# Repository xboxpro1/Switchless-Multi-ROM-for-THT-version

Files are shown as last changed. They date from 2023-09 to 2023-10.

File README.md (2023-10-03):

# CBM Switchless Multi-ROM for 2364 & 27128 & 27256 ROMs

This is a fork, rework and combination of two repositories from RetroNynjah.

<https://github.com/RetroNynjah/Switchless-Multi-ROM-for-2364>

<https://github.com/RetroNynjah/Switchless-Multi-ROM-for-27128-27256>

I would like to thank RetroNynjah for the brilliant idea and excellent work.<br/>
After a long search on the internet, there is finally the perfect ROM switcher.

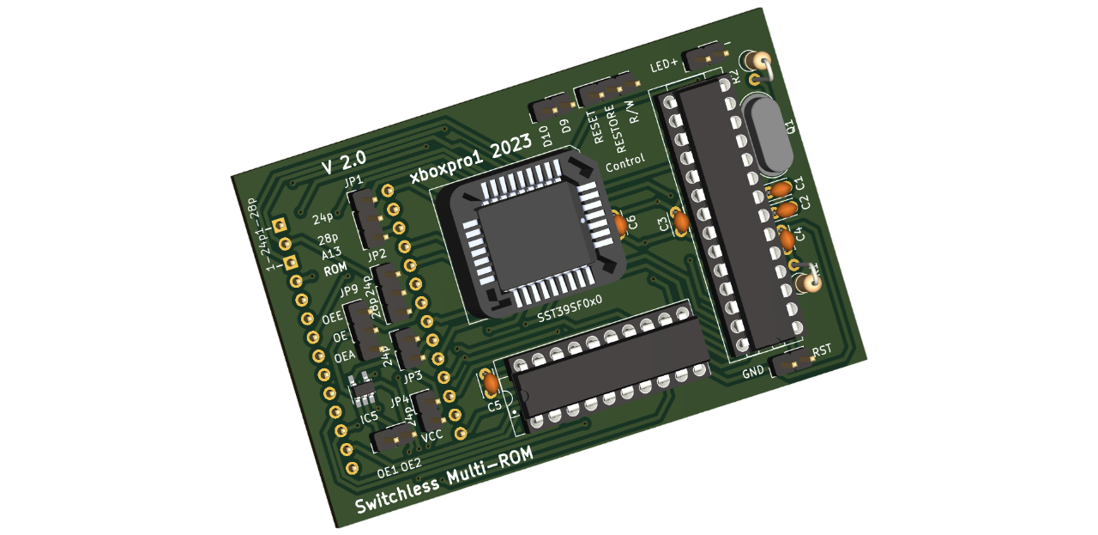
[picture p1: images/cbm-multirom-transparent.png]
<br/>
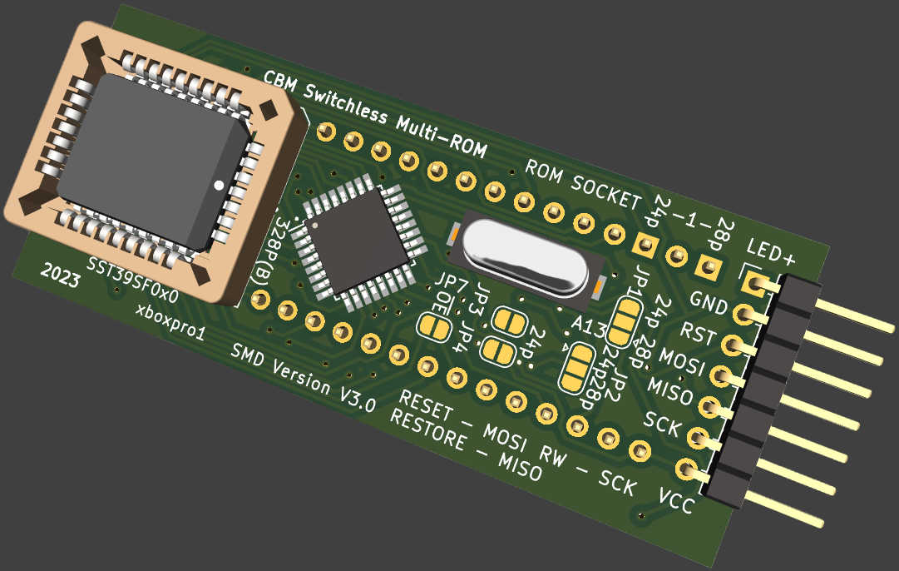
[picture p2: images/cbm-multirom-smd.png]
<br/>

A switchless multi-ROM for 2364 ROM (24-pin) and 27128/27256 ROM (28-pin) type applications. <br/>
The switch is controlled by an MCU that is picking up predefined magic words on the data bus.  

Example use cases:
* Menu driven Kernal switch for Commodore VIC-20
* Menu driven Kernal switch for Commodore C64 (longboards)
* Menu driven Kernal switch for Commodore C64C (shortboard)
* Menu driven Kernal switch for Commodore C128
* You tell me

Check the General-Info.pdf for a general description and BOM.

Check the Application-Info.pdf in the applications folder for examples on how to use it for the use cases above.

Check the Hardware-Info.pdf and SMD-Hardware-Info.pdf in the hardware folder for a general technical description and build instructions.

A short video that shows how it works can be seen here. 
<https://youtu.be/isT9-QBMzEc?si=csgdmX4p8TZYezGX>

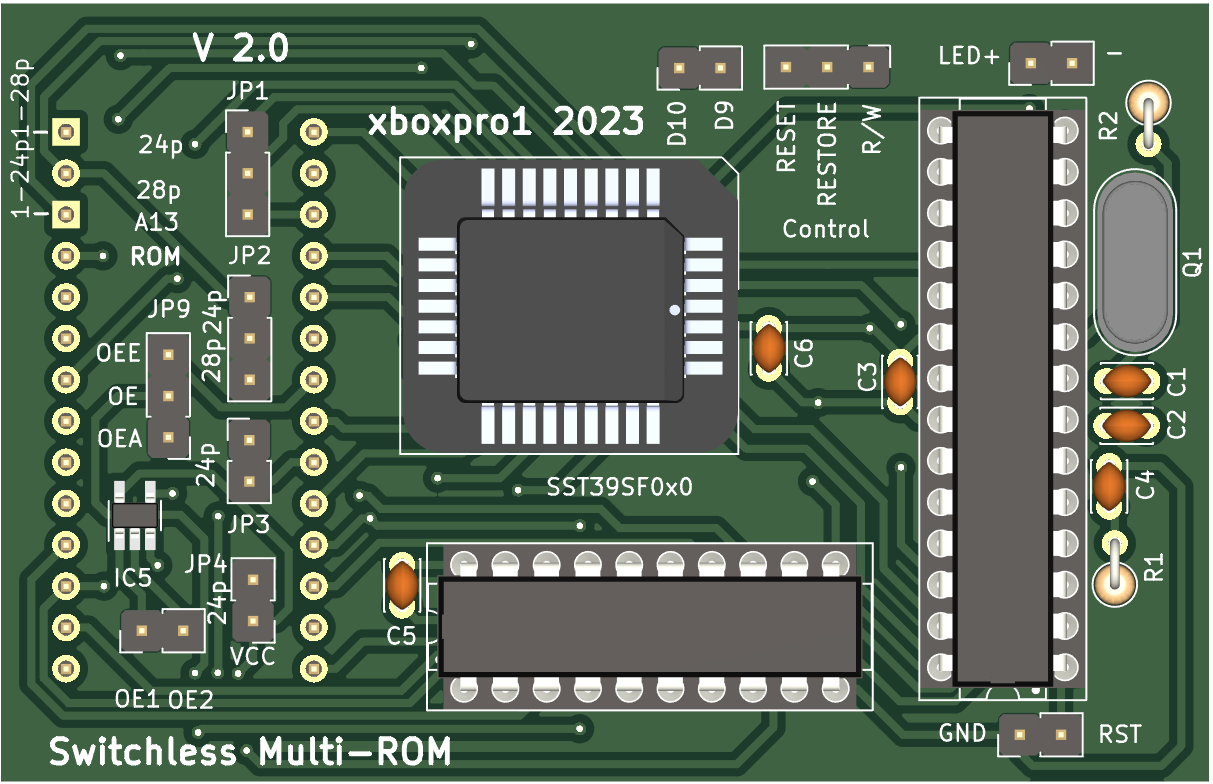
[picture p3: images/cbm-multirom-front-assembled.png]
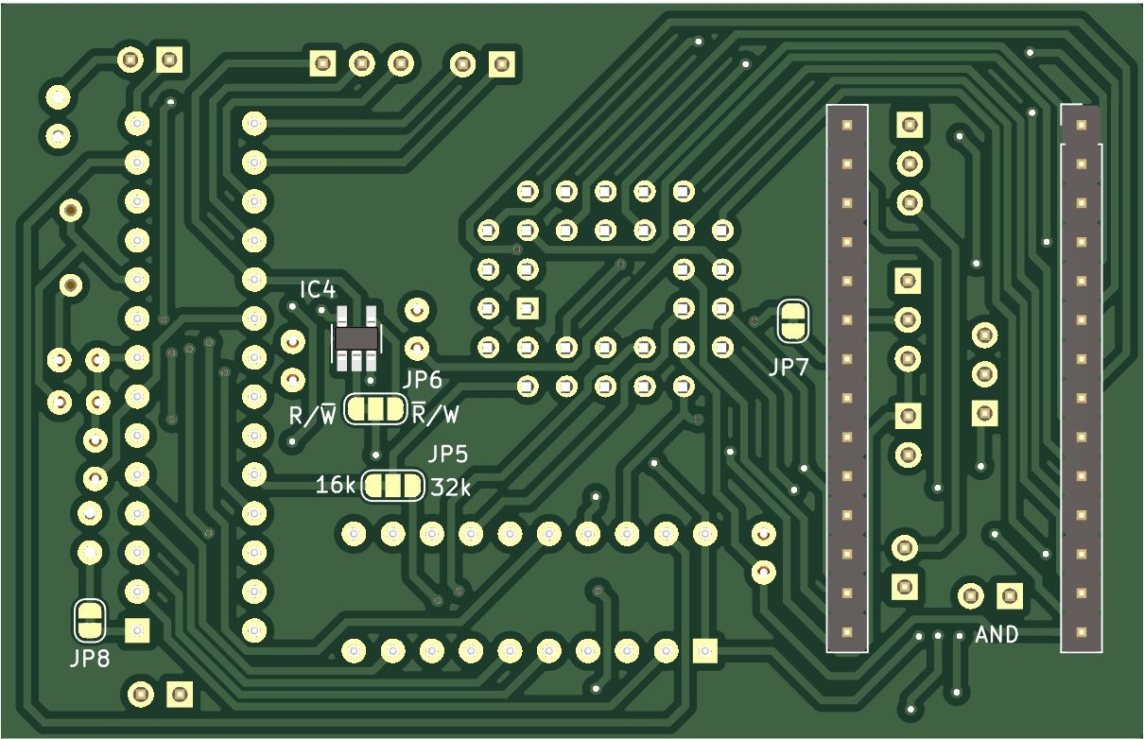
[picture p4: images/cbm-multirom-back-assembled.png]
  <br/>
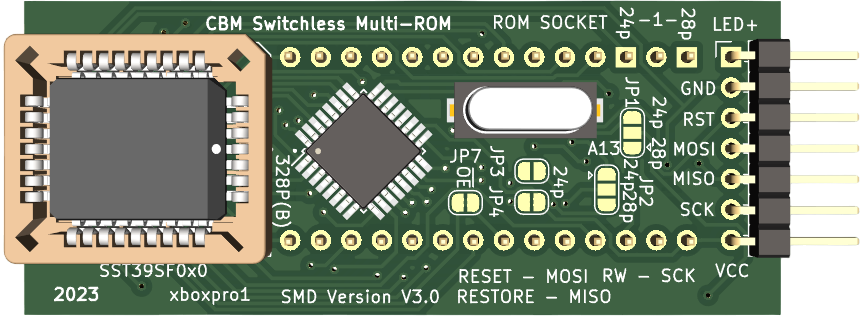
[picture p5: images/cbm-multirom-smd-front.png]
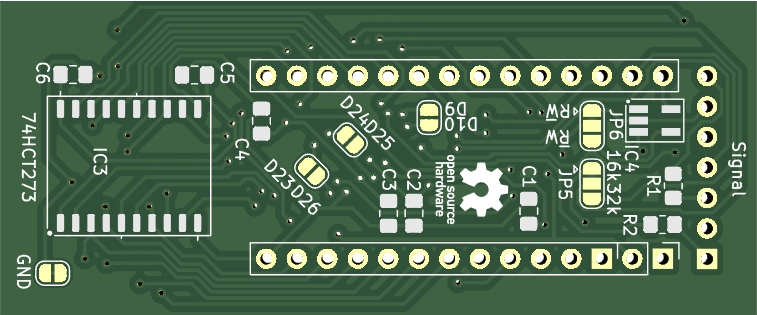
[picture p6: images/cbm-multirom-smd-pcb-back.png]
  <br/>

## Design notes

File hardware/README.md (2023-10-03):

# CBM Switchless Multi-ROM for 2364 & 27128 & 27256 ROMs

This is a fork, rework and combination of two repositories from RetroNynjah.

3D rendering<br/><br/>
3D rendering<br/>

Here are the files to make the hardware and the shematic.

Check the Hardware-Info.pdf and SMD-Hardware-Info.pdf in the hardware folder for a general technical description and build instructions.

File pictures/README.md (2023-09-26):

# CBM Switchless Multi-ROM for 2364 & 27128 & 27256 ROMs

This is a fork, rework and combination of two repositories from RetroNynjah.

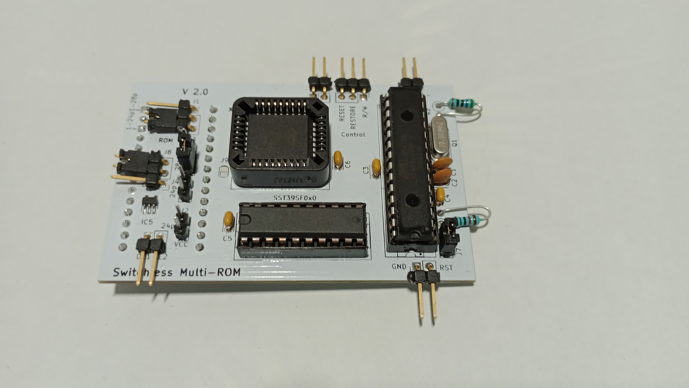
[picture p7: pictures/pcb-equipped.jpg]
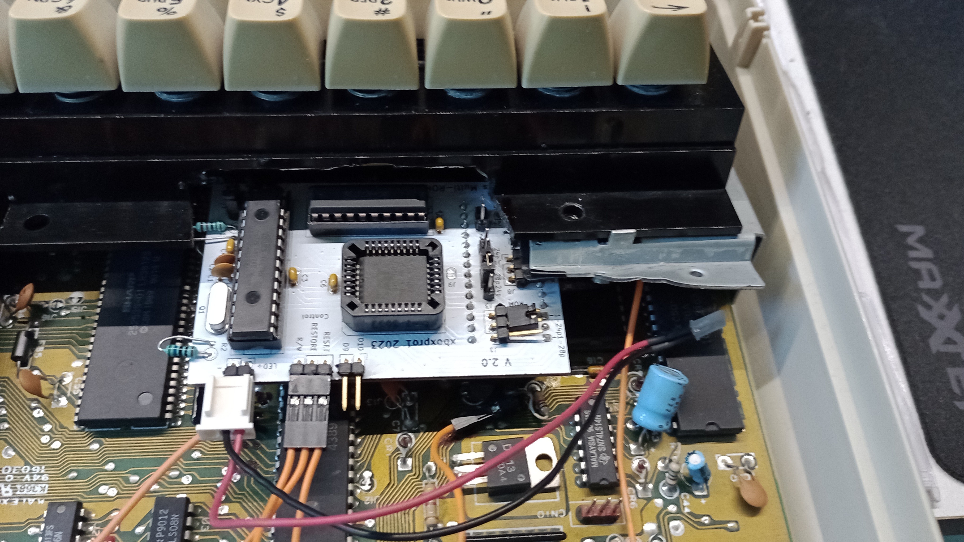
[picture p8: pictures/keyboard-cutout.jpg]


Here are the pictures of a fully assembled PCB that is installed in a C64C.
The keyboard's plastic frame had to be cut.

Check the Hardware-Info.pdf in the hardware folder for a general technical description and build instructions.

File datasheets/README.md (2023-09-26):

# CBM Switchless Multi-ROM for 2364 & 27128 & 27256 ROMs

This is a fork, rework and combination of two repositories from RetroNynjah.

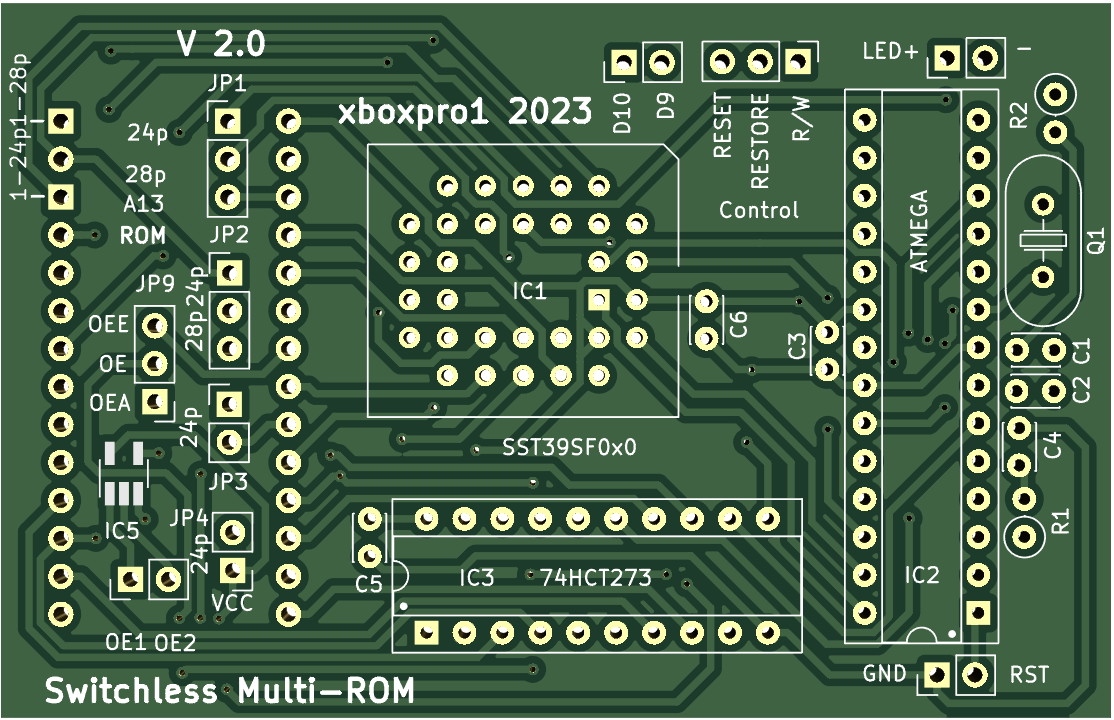
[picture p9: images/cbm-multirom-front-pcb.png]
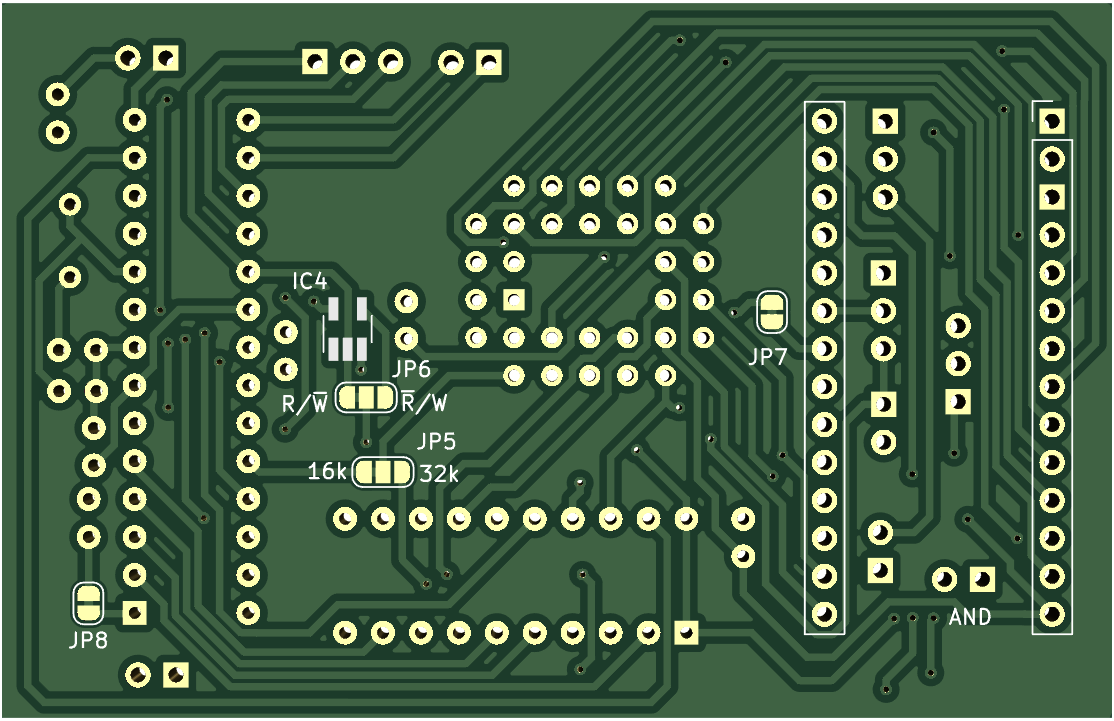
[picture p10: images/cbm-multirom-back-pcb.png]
 <br/>

Here are the used datasheets.

Check the General-Info.pdf for a general description and BOM.

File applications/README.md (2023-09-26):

# CBM Switchless Multi-ROM for 2364 & 27128 & 27256 ROMs

This is a fork, rework and combination of two repositories from RetroNynjah.

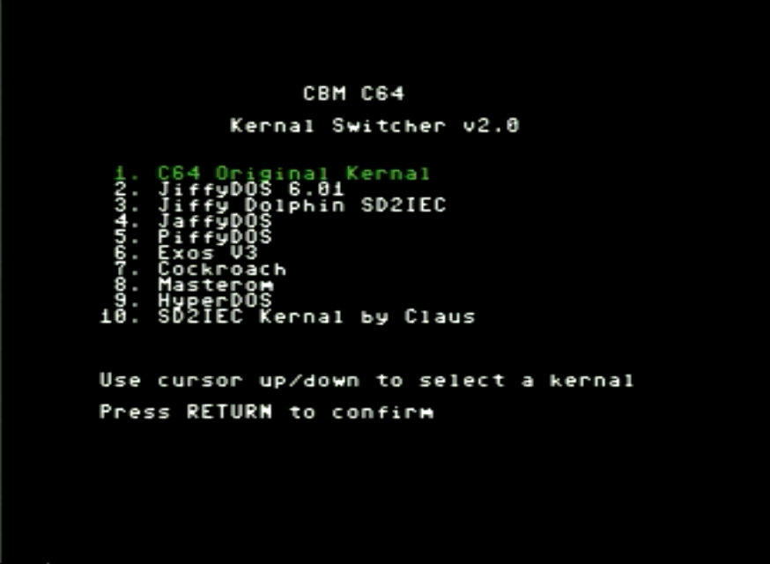
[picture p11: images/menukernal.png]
3D rendering
<br/>

Here are the files for the AVR firmware and the CBM Mini-Kernal.

Check the Application-Info.pdf in the applications folder for examples on how to compile the files.

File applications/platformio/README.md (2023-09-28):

# CBM Switchless Multi-ROM for 2364 & 27128 & 27256 ROMs

This is a fork, rework and combination of two repositories from RetroNynjah.

3D rendering<br/>

Here are the files to compile the AVR firmware with PlatformIO.

Check the Application-Info.pdf in the applications folder for examples on how to compile the files.

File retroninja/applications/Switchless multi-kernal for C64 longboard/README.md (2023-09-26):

# Switchless multi-kernal for C64 longboard

Can be used as a Kernal switch for the C64 longboard motherboards.  
The Kernal menu is activated by pressing the RESTORE key for a few seconds.

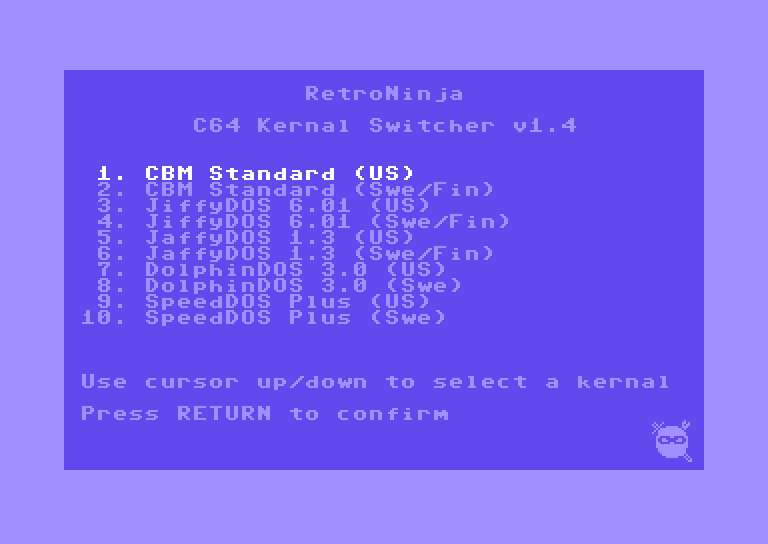
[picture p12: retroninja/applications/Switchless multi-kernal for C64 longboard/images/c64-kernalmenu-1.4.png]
C64 Kernal menu
<br/>

Read more in the User's Guide

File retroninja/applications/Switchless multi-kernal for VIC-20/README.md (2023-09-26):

# Switchless multi-kernal for VIC-20

Can be used as a Kernal switch for the VIC-20.  
The Kernal menu is activated by pressing the RESTORE key for a few seconds.

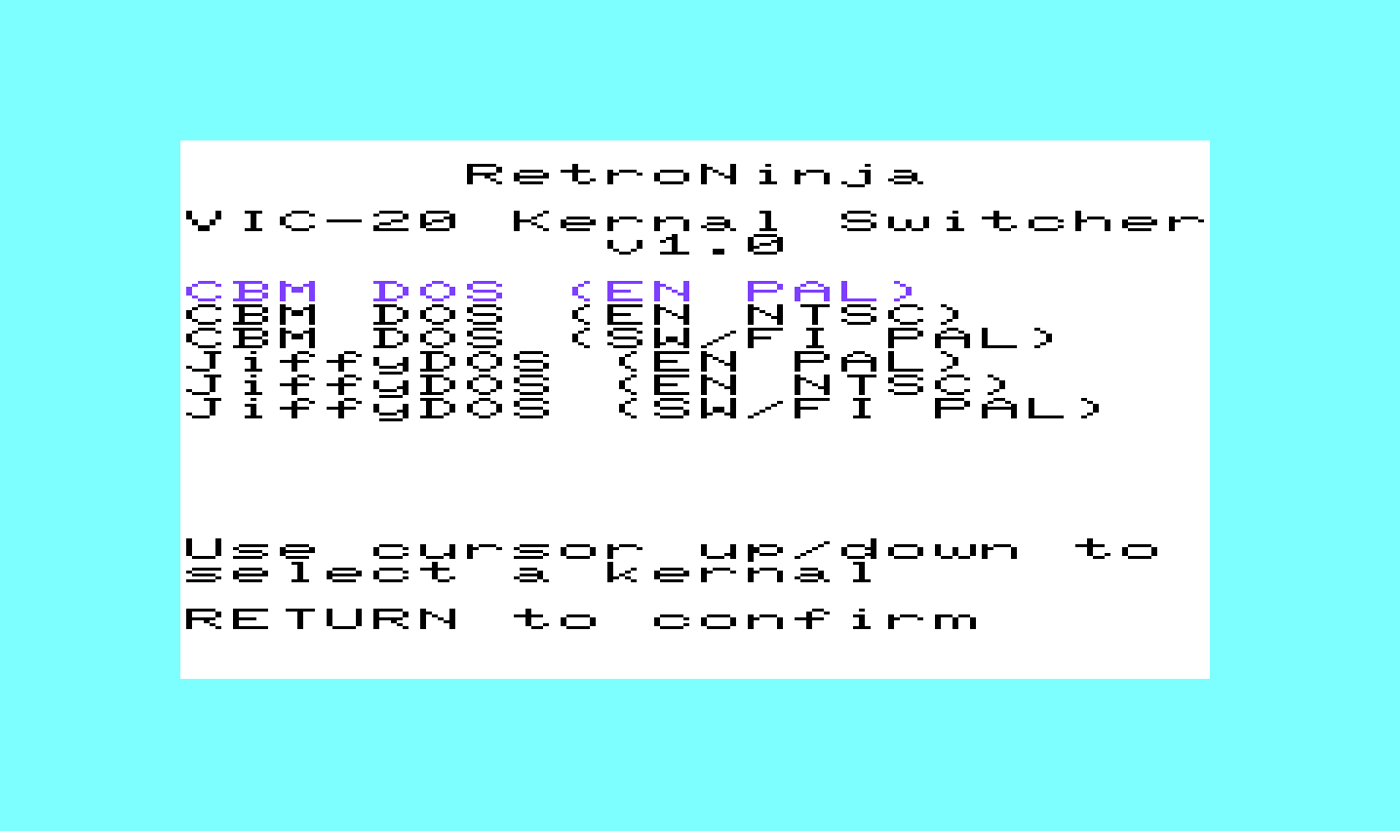
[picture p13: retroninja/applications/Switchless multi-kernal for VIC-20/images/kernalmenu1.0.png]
VIC-20 Kernal menu
<br/>

Read more in the User's Guide

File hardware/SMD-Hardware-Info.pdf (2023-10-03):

## CBM Switchless Multi ROM for 2364 & 27128 & 27256 ROMS

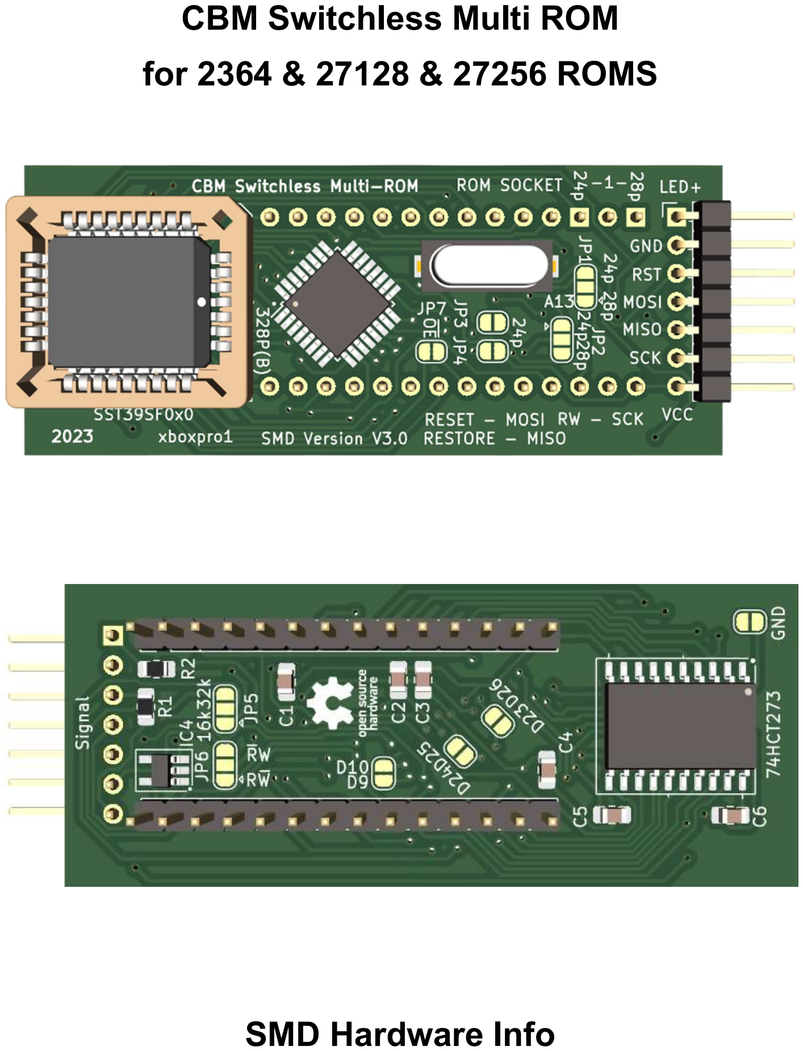
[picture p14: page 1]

## SMD Hardware Info

CBM Switchless Multi ROM for 2364 & 27128 & 27256 ROMS | SMD Hardware Info ______________________________________________________________________

2

2

CBM Switchless Multi ROM for 2364 & 27128 & 27256 ROMS | SMD Hardware Info ______________________________________________________________________

3

3

Table of Contents

CBM Switchless Multi ROM for 2364 & 27128 & 27256 ROMS | SMD Hardware Info ______________________________________________________________________

4

4

Functional Description

At power on, the AVR microcontroller (referred below as MCU) in the Switchless mini Kernal switch holds the reset line active-low while it reads address 0 from its internal EPROM to find out which Kernal ROM it should select, sets the A13-A18 address lines on the flash chip accordingly and releases the reset line to make sure the CBM computer is booted using the correct Kernal ROM image.
If at any time, Restore key is pressed and held for a few seconds the MCU will detect this and switch to Kernal ROM 0 which is the Switchless mini Kernal menu image. When the user selects a Kernal image from the menu, the Switchless mini Kernal writes a predefined switching command to the data bus along with a byte that indicates the selected image number. It does this over and over. Example command: CBMROM64#1 where 1 is a byte with value 0x01 that tells the

Switchless mini Kernal that we want to switch to Kernal ROM image 1. The Kernal switcher now captures the command from the data bus, writes the selected

Kernal number to the MCU EPROM for future use and it sets the address lines A13-A18 accordingly. It then resets the computer using the new Kernal image by pulling the reset line low. The computer will continue to start up using this new Kernal ROM until a new choice is made.
Even at a clock speed of 20 MHz, reading and analyzing data on a 1MHz data bus can be quite a challenge so the data on the computer data bus is buffered in the Switchless mini Kernal switcher by a 74HCT273 flip-flop that is clocked by the write signal (r/w) from the CBM CPU. By clocking the data with the r/w signal we filter out irrelevant bus traffic and the flip-flop holds the relevant data until the next r/w cycle. This gives the MCU a little more time to read the data from the flip-flop.
Switching C64 and C128 Kernals
Hold the Restore key for about three seconds until the Kernal menu is activated. Once in menu you can use cursor up/down to move the Kernal ROM you want to switch to and press Return. The switch resets the computer with the new Kernal ROM and saves your choice for next power-on.
Switching C64 Kernal in a C128
When switching the C64 Kernal in a C128, hold the CBM and Restore keys for about three seconds until the C64 Kernal menu is activated. Keep holding the CBM key while selecting a Kernal with the cursor up/down and Return keys. While pressing Return you should hold the CBM key until the reset is done to be taken to C64 mode. Otherwise you will end up in C128 mode after switching. For the C64 Kernal you have to do a GO64 or holding CBM and Restore key again. The switcher saves your choice for next power-on. In the a C128DCR you can use either C128 or C64 Kernal menu to switch the Kernal

ROM but both C64 and C128 Kernal ROM will be switched at the same time.

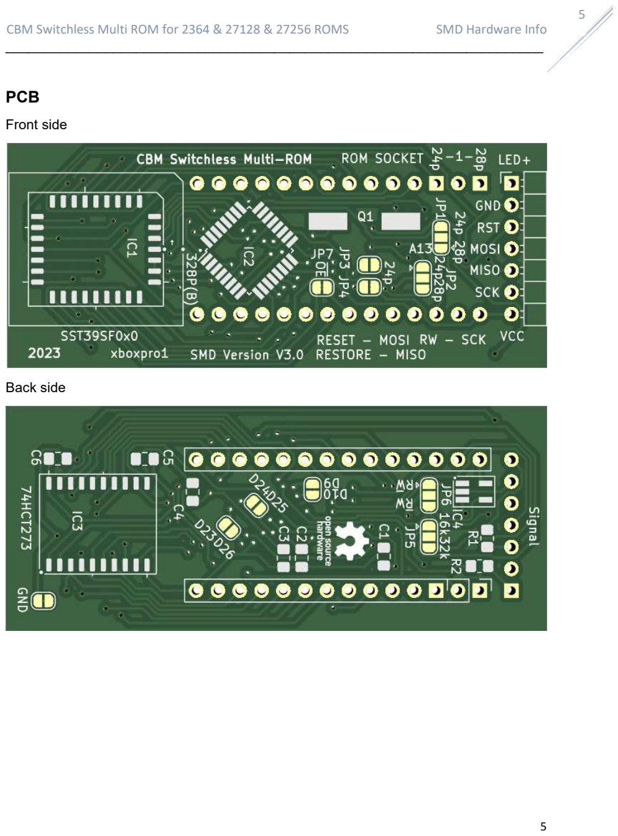
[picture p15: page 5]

CBM Switchless Multi ROM for 2364 & 27128 & 27256 ROMS | SMD Hardware Info ______________________________________________________________________

5

5

PCB

Front side

Back side

CBM Switchless Multi ROM for 2364 & 27128 & 27256 ROMS | SMD Hardware Info ______________________________________________________________________

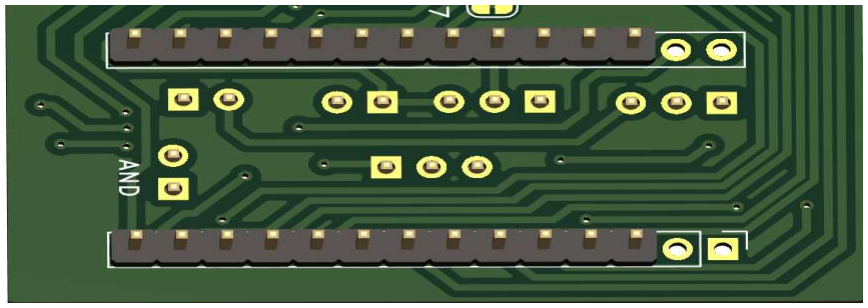
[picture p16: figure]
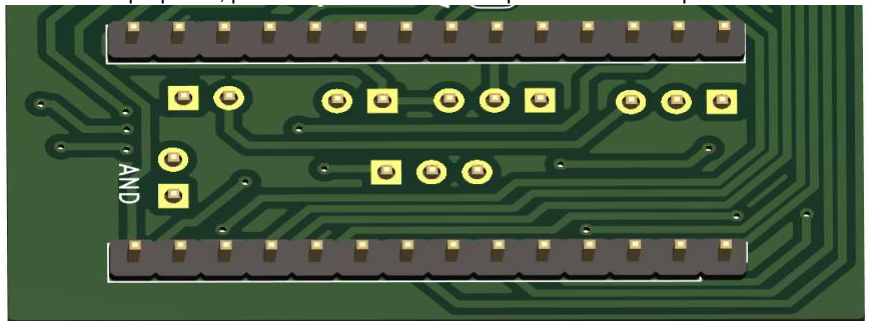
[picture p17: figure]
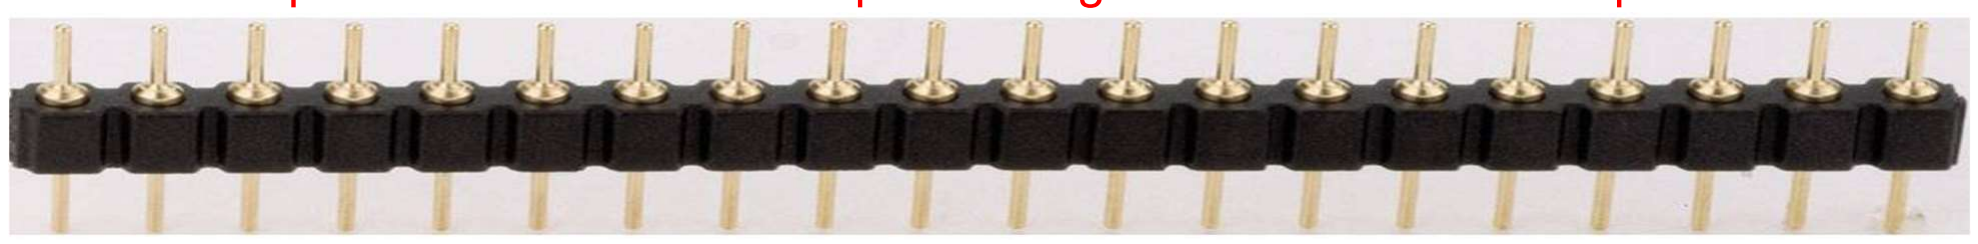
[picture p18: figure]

6

6

PCB Soldering

Recommended soldering order, first the PCB front SMD parts, IC1, IC2, and Q1. Then the PCB back SMD parts, IC3, (IC4), C1-C6, R1 and R2. IC4 is optional. Then the two machined pin headers for the CBM ROM socket.
SMD
If you want to use the Kernal ROM switcher in a CBM 1541, 1541-II, 1551, 1570, 1571 or 1581 Floppy Disk Drive, the signal r/w must be inverted. For this, the SMD IC4 must be soldered on the PCB back side.
Pin headers
If you only want to use the Switchless Multi ROM in a CBM computer with an 8k, 24-pin ROM. You just need to solder the machined pin headers in 24-pin mode.

For all other purposes, please solder the machined pin headers in 28-pin mode.

A machined pin header is round not square. Image below is a machined pin header.

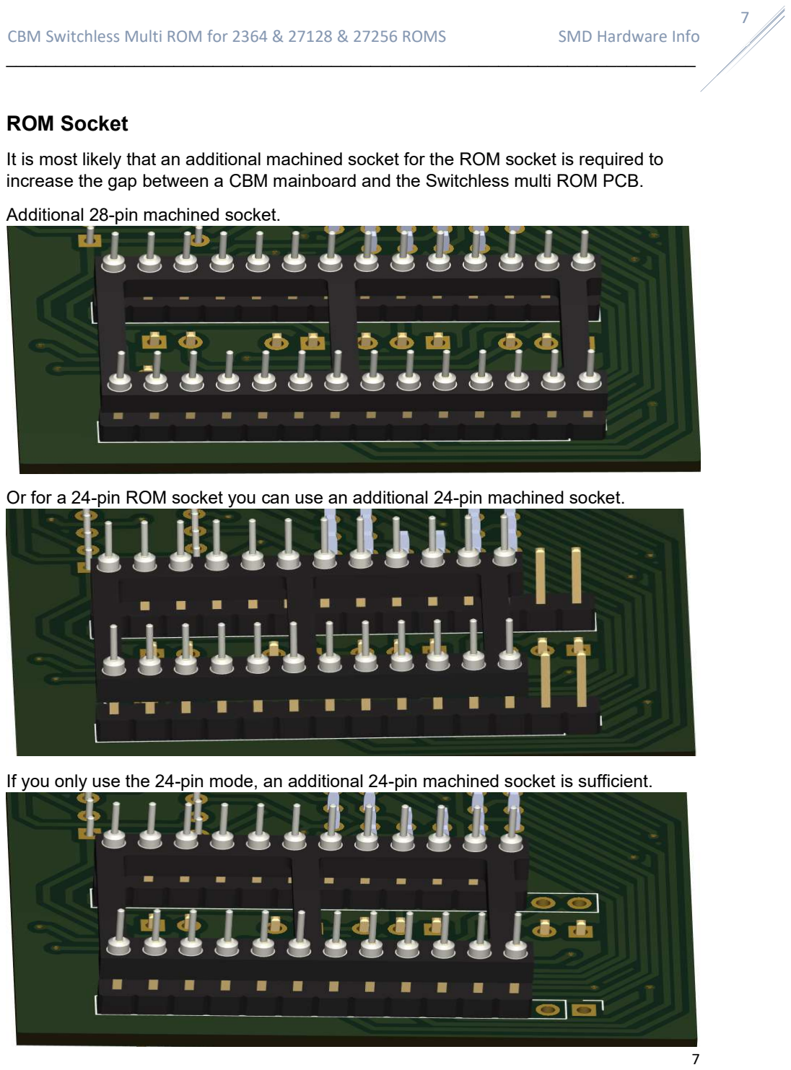
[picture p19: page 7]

CBM Switchless Multi ROM for 2364 & 27128 & 27256 ROMS | SMD Hardware Info ______________________________________________________________________

7

7

ROM Socket

It is most likely that an additional machined socket for the ROM socket is required to increase the gap between a CBM mainboard and the Switchless multi ROM PCB. Additional 28-pin machined socket.

Or for a 24-pin ROM socket you can use an additional 24-pin machined socket.

If you only use the 24-pin mode, an additional 24-pin machined socket is sufficient.

CBM Switchless Multi ROM for 2364 & 27128 & 27256 ROMS | SMD Hardware Info ______________________________________________________________________

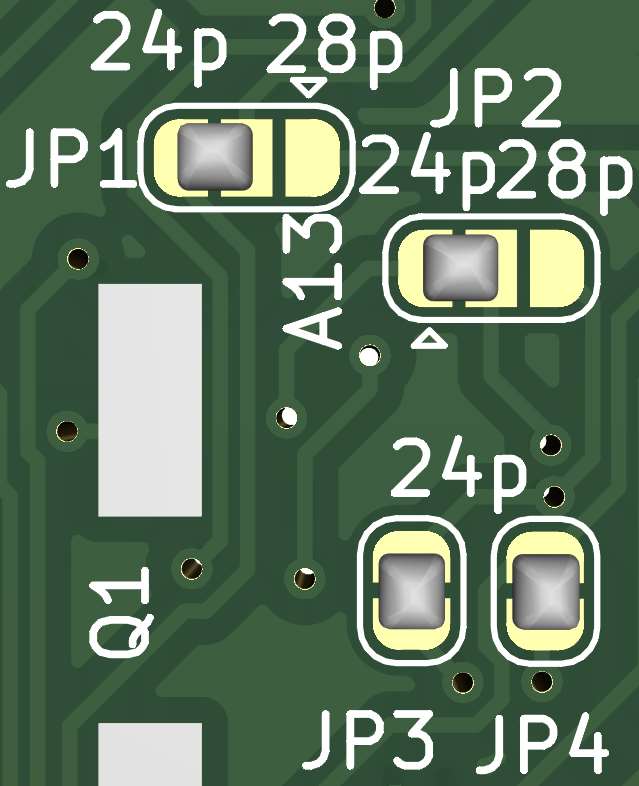
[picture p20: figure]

8

8

Jumper Settings

The pins of the 2364, 27128 and 27256 ROMs are slightly different. The mode must therefore be set using jumpers.

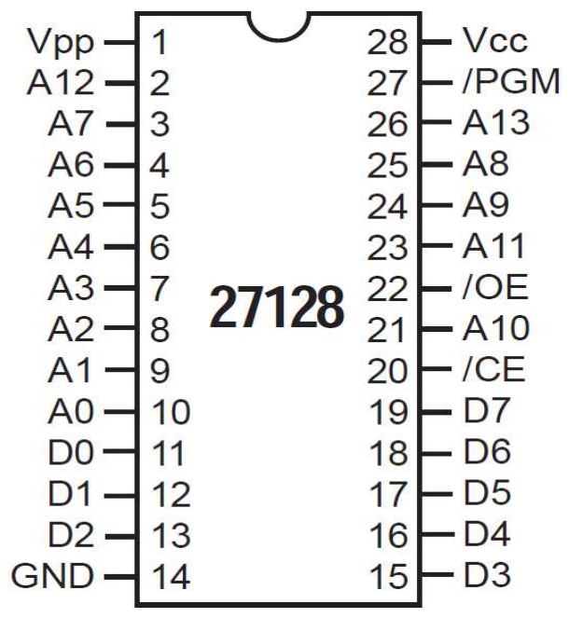
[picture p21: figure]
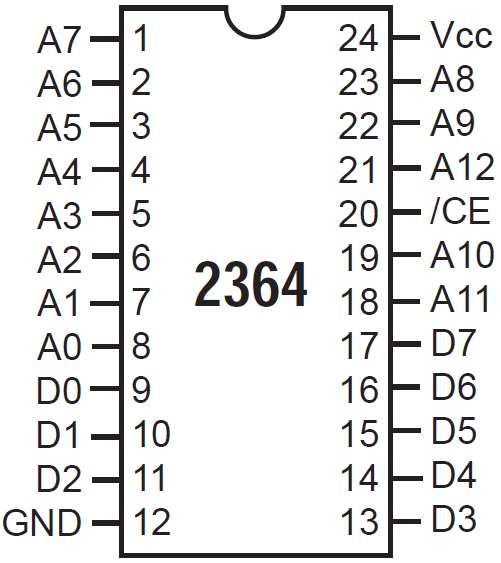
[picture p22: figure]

VIC20, C64, 24-pin, 8k mode
Solder bridge:

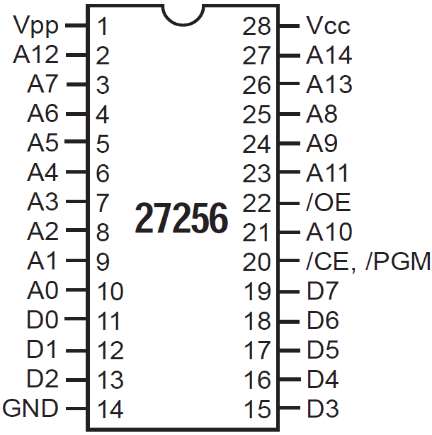
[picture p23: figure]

JP1: 24p (1-2) AVR MCU controls address line A13
JP2: 24p (1-2) CBM CPU controls address line A12 on ROM socket pin 23 JP3: 24p (1-2) CBM CPU controls address line A11 on ROM socket pin 20 JP4: 24p (1-2) CBM ROM socket pin 26 is connected to VCC

CBM Switchless Multi ROM for 2364 & 27128 & 27256 ROMS | SMD Hardware Info ______________________________________________________________________

9

9

Jumper Settings

C64C, C128, 28-pin, 16k mode
Solder bridge:
JP1: 28p (2-3) CBM CPU controls address line A13 on ROM socket pin 26 JP2: 28p (2-3) CBM CPU controls address line A11 on ROM socket pin 23
JP3: open | Attention, it won't work without an open solder bridge. JP4: open | Attention, it won't work without an open solder bridge.

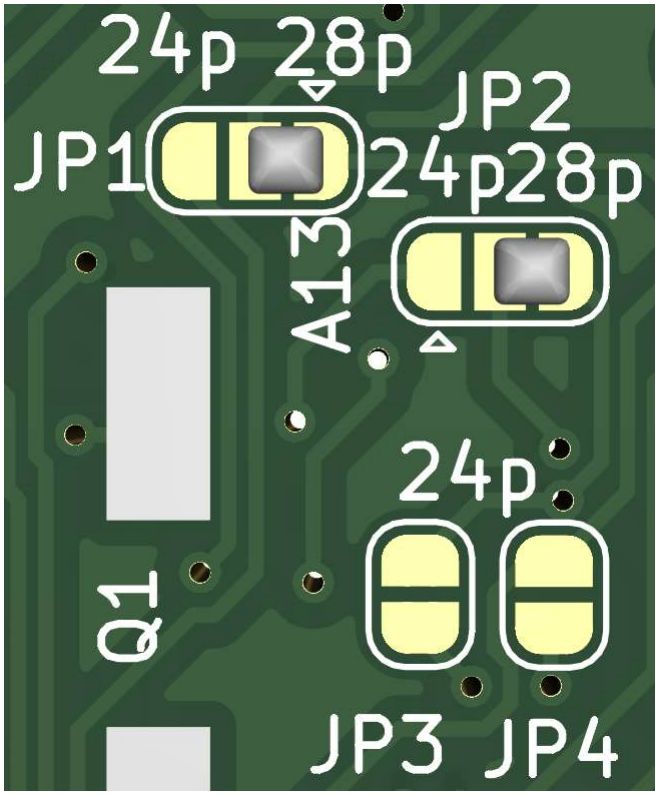
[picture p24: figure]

CBM Switchless Multi ROM for 2364 & 27128 & 27256 ROMS | SMD Hardware Info ______________________________________________________________________

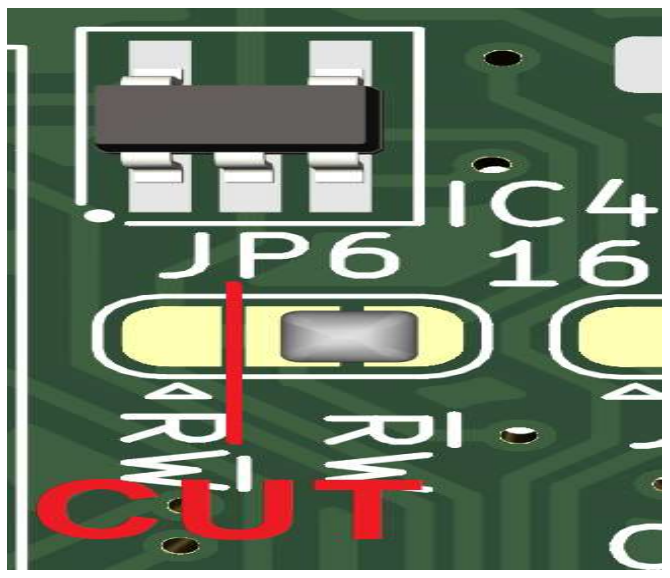
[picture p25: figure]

10

10

Jumper Settings

C128DCR, 28-pin, 32k mode
Solder bridge:
JP1 – JP4 are the same as 28-pin, 16k mode
JP5 is connected for 16k mode by default.
Cut the connection between pin 1 and pin 2 with a cutting knife. Use a multimeter to make sure there is no connection between pin 1 and pin 2. Make a solder bridge between pin 2 and pin 3 for the 32k mode.

CBM CPU controls address line A14 on ROM socket pin 27

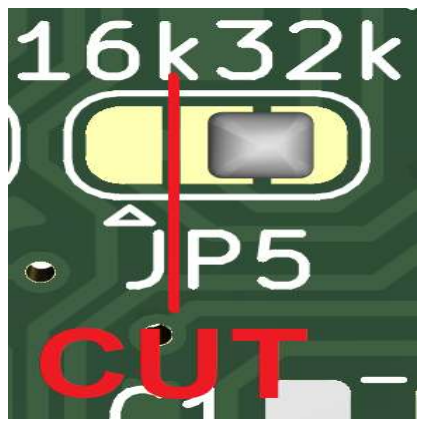
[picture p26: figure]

If you want to use the Kernal ROM switcher in a CBM 1541, 1541-II, 1551, 1570, 1571 or 1581 Floppy Disk Drive, the signal r/w must be inverted.
For this, the SMD IC4 must be soldered on the PCB back side.
JP6 is connected not to invert the r/w signal by default.
Cut the connection between pin 1 and pin 2 with a cutting knife. Use a multimeter to make sure there is no connection between pin 1 and pin 2.

Make a solder bridge between pin 2 and pin 3 to invert the r/w signal.
The r/w signal is inverted for IC3.

CBM Switchless Multi ROM for 2364 & 27128 & 27256 ROMS | SMD Hardware Info ______________________________________________________________________

11

11

LED

The LED+ connector is used for the case's power LED to display the ROM blink codes and Restore key presses. The LED can be deactivated in the firmware in order to be able to use the MCU pin 8 (LED pin) for another purpose.

ISP Connection

To program the MCU via ISP, the ISP programmer must be connected as follows.
MOSI | | PCB MOSI
MISO | | PCB MISO
SCK | | PCB SCK
RESET | | PCB RST
GND | | PCB GND
VCC | | PCB VCC

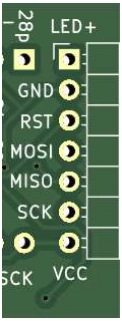
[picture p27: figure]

CBM Switchless Multi ROM for 2364 & 27128 & 27256 ROMS | SMD Hardware Info ______________________________________________________________________

12

12

Parts

Parts for SMD Version V3.0

Nr. | Amount | Component | Part | Description | Comment
1 | 1 | IC1 | SST39SF0x0 | 32-PLCC Flash | SST39SF010/20/40
2 | 1 | IC2 | ATmega MCU | 32-TQFP MCU | Atmega48/88/168/328 P or PB
3 | 1 | IC3 | 74HCT273 | 20-SOIC 5.3mm | Flip-Flop
4 | 1 | IC4 | 74HCT1G04 | SOT23-5 1 * Inverter | Only needed if clock needs inverting
5 | 1 | Q1 | 20MHz Crystal | HC49-SMD | 16MHz is ok for 1MHz systems
6 | 4 | C1 - C4 | 100nF capacitor | 0805 ceramic
7 | 2 | C5, C6 | 27pF capacitor | 0805 ceramic | 22pF works fine too
8 | 1 | R1 | 10kΩ resistor | 0805 Resistor
9 | 1 | R2 | 560Ω resistor | 0805 Resistor
10 | 1 | IC1 Socket | PLCC Socket | SMD PLCC-32 | For flash memory chip
11 | 2 | ROM Headers | 14-Pin Header | Pitch2.54mm | Use machined or flat pins - not square
12 | 1 | Connector | 7-Pin Header | Angeled 2.54mm | For Connection
13 | 1 | ROM Socket | IC Socket 28-pin | 15.24mm THT | Optional additional machined Socket
14 | 1 | ROM Socket | IC Socket 24-pin | 15.24mm THT | Optional additional machined Socket

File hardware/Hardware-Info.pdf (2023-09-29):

## CBM Switchless Multi ROM for 2364 & 27128 & 27256 ROMS

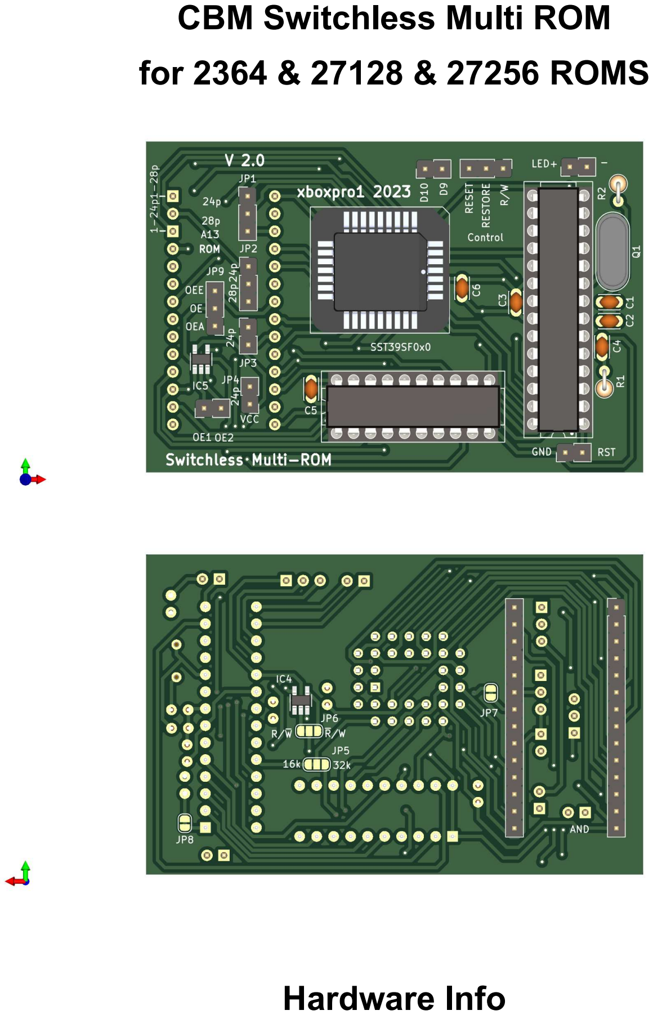
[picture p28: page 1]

## Hardware Info

CBM Switchless Multi ROM for 2364 & 27128 & 27256 ROMS | Hardware Info ______________________________________________________________________

2

2

CBM Switchless Multi ROM for 2364 & 27128 & 27256 ROMS | Hardware Info ______________________________________________________________________

3

3

Table of Contents

CBM Switchless Multi ROM for 2364 & 27128 & 27256 ROMS | Hardware Info ______________________________________________________________________

4

4

Functional Description

At power on, the AVR microcontroller (referred below as MCU) in the Switchless mini Kernal switch holds the reset line active-low while it reads address 0 from its internal EPROM to find out which Kernal ROM it should select, sets the A13-A18 address lines on the flash chip accordingly and releases the reset line to make sure the CBM computer is booted using the correct Kernal ROM image.
If at any time, Restore key is pressed and held for a few seconds the MCU will detect this and switch to Kernal ROM 0 which is the Switchless mini Kernal menu image. When the user selects a Kernal image from the menu, the Switchless mini Kernal writes a predefined switching command to the data bus along with a byte that indicates the selected image number. It does this over and over. Example command: CBMROM64#1 where 1 is a byte with value 0x01 that tells the

Switchless mini Kernal that we want to switch to Kernal ROM image 1. The Kernal switcher now captures the command from the data bus, writes the selected

Kernal number to the MCU EPROM for future use and it sets the address lines A13-A18 accordingly. It then resets the computer using the new Kernal image by pulling the reset line low. The computer will continue to start up using this new Kernal ROM until a new choice is made.
Even at a clock speed of 20 MHz, reading and analyzing data on a 1MHz data bus can be quite a challenge so the data on the computer data bus is buffered in the Switchless mini Kernal switcher by a 74HCT273 flip-flop that is clocked by the write signal (r/w) from the CBM CPU. By clocking the data with the r/w signal we filter out irrelevant bus traffic and the flip-flop holds the relevant data until the next r/w cycle. This gives the MCU a little more time to read the data from the flip-flop.
Switching C64 and C128 Kernals
Hold the Restore key for about three seconds until the Kernal menu is activated. Once in menu you can use cursor up/down to move the Kernal ROM you want to switch to and press Return. The switch resets the computer with the new Kernal ROM and saves your choice for next power-on.
Switching C64 Kernal in a C128
When switching the C64 Kernal in a C128, hold the CBM and Restore keys for about three seconds until the C64 Kernal menu is activated. Keep holding the CBM key while selecting a Kernal with the cursor up/down and Return keys. While pressing Return you should hold the CBM key until the reset is done to be taken to C64 mode. Otherwise you will end up in C128 mode after switching. For the C64 Kernal you have to do a GO64 or holding CBM and Restore key again. The switcher saves your choice for next power-on. In the a C128DCR you can use either C128 or C64 Kernal menu to switch the Kernal

ROM but both C64 and C128 Kernal ROM will be switched at the same time.

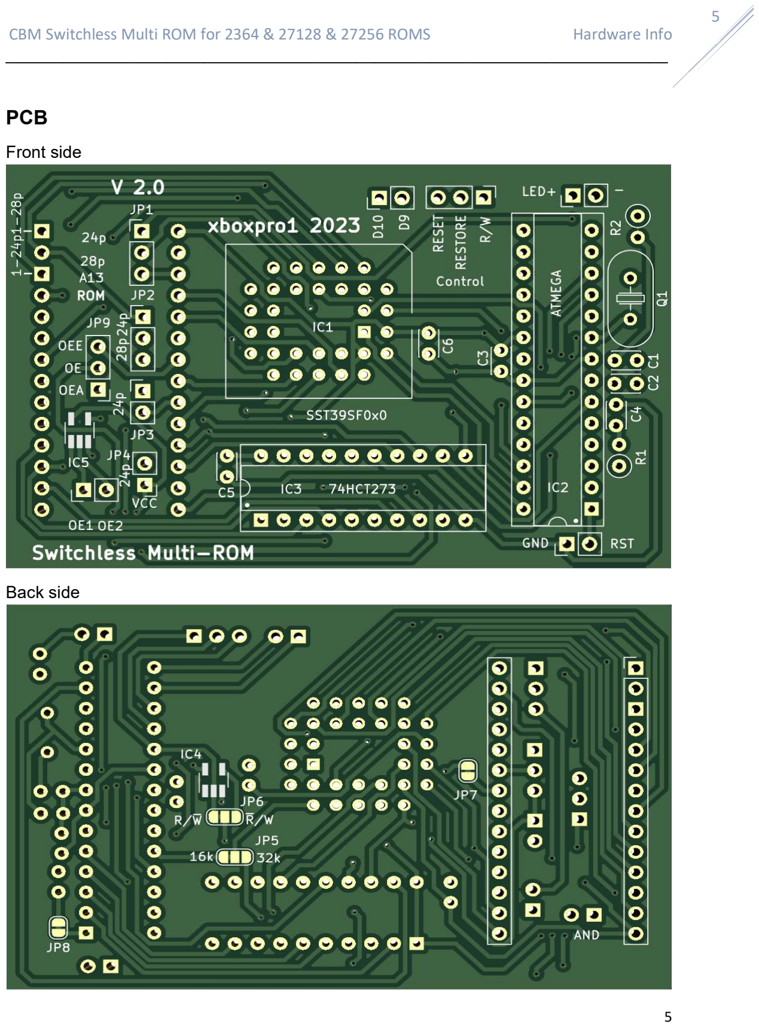
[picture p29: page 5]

CBM Switchless Multi ROM for 2364 & 27128 & 27256 ROMS | Hardware Info ______________________________________________________________________

5

5

PCB

Front side

Back side

CBM Switchless Multi ROM for 2364 & 27128 & 27256 ROMS | Hardware Info ______________________________________________________________________


6

6

PCB Soldering

Recommended soldering order, first the SMD parts, then the two machined pin headers for the CBM ROM socket and then the rest in any order.
SMD
If you want to use the Kernal ROM switcher in a CBM 1541-II, 1571 or 1581 Diskdrive the signal r/w must be inverted. For this, the SMD IC4 must be soldered on the PCB back side. SMD IC5, JP9, the OE1/OE2 and D9/D10 connectors on the PCB front side are not needed unless you want to experiment with the Switchless multi ROM. Pin headers
If you only want to use the Switchless multi ROM in a CBM computer with an 8k, 24-pin ROM. You just need to solder the machined pin headers in 24-pin mode.

For all other purposes, please solder the machined pin headers in 28-pin mode.

A machined pin header is round not square. Image below is a machined pin header.

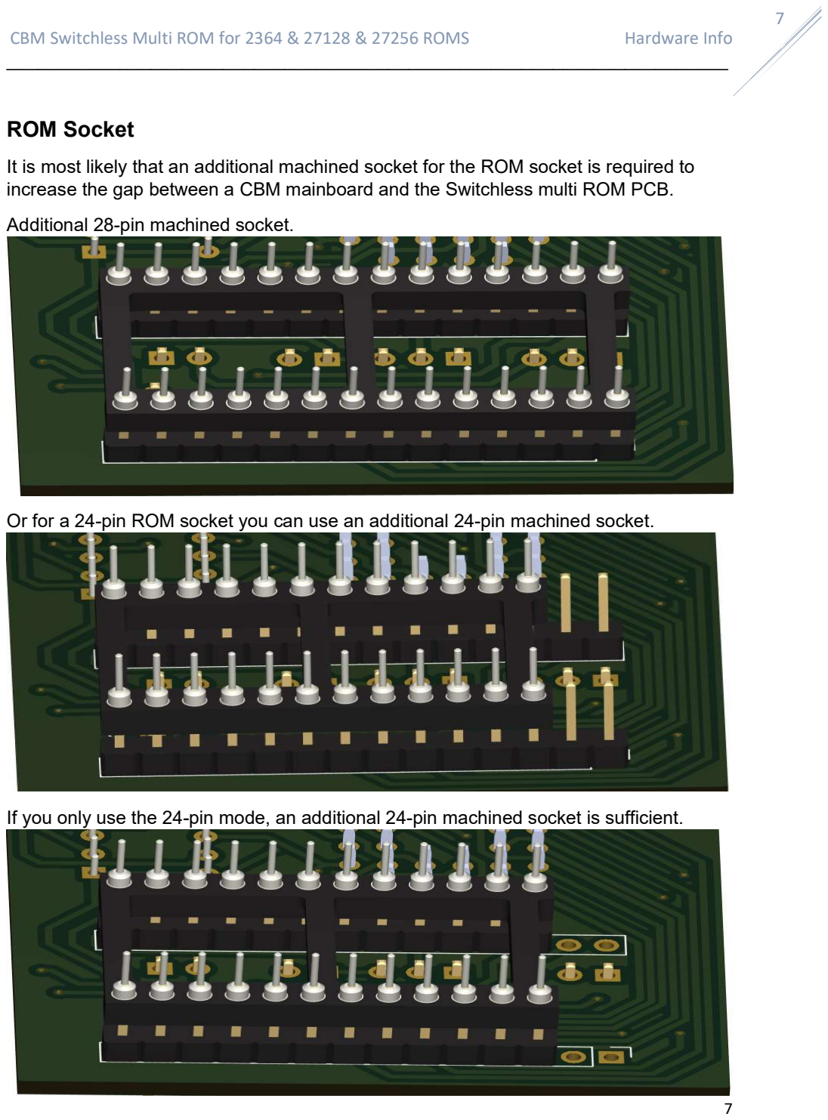
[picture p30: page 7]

CBM Switchless Multi ROM for 2364 & 27128 & 27256 ROMS | Hardware Info ______________________________________________________________________

7

7

ROM Socket

It is most likely that an additional machined socket for the ROM socket is required to increase the gap between a CBM mainboard and the Switchless multi ROM PCB. Additional 28-pin machined socket.

Or for a 24-pin ROM socket you can use an additional 24-pin machined socket.

If you only use the 24-pin mode, an additional 24-pin machined socket is sufficient.


CBM Switchless Multi ROM for 2364 & 27128 & 27256 ROMS | Hardware Info ______________________________________________________________________

8

8

Jumper Settings

The pins of the 2364, 27128 and 27256 ROMs are slightly different. The mode must therefore be set using jumpers.

VIC20, C64, 24-pin, 8k mode
JP1: 24p (1-2) AVR MCU controls address line A13
JP2: 24p (1-2) CBM CPU controls address line A12 on ROM socket pin 23 JP3: 24p (1-2) CBM CPU controls address line A11 on ROM socket pin 20 JP4: 24p (1-2) CBM ROM socket pin 26 is connected to VCC

CBM Switchless Multi ROM for 2364 & 27128 & 27256 ROMS | Hardware Info ______________________________________________________________________


9

9

Jumper Settings

C64C, C128, 28-pin, 16k mode
JP1: 28p (2-3) CBM CPU controls address line A13 on ROM socket pin 26 JP2: 28p (2-3) CBM CPU controls address line A11 on ROM socket pin 23
JP3: open | Attention, it won't work without an open jumper. JP4: open | Attention, it won't work without an open jumper.

CBM Switchless Multi ROM for 2364 & 27128 & 27256 ROMS | Hardware Info ______________________________________________________________________


10

10

Jumper Settings

C128DCR, 28-pin, 32k mode
JP1 – JP4 are the same as 28-pin, 16k mode
JP5:
JP5 is connected for 16k mode by default.
Cut the connection between pin 1 and pin 2 with a cutting knife. Use a multimeter to make sure there is no connection between pin 1 and pin 2. Make a solder bridge between pin 2 and pin 3 for the 32k mode.

CBM CPU controls address line A14 on ROM socket pin 27
If you want to use the Switchless multi Kernal ROM in a 1541-II, 1571 or 1581 Floppy Disk Drive the signal r/w must be inverted.
For this, the SMD IC4 must be soldered on the PCB back side.


JP6:
JP6 is connected not to invert the r/w signal by default.
Cut the connection between pin 1 and pin 2 with a cutting knife. Use a multimeter to make sure there is no connection between pin 1 and pin 2.

Make a solder bridge between pin 2 and pin 3 to invert the r/w signal.
The r/w signal is inverted for IC3.


CBM Switchless Multi ROM for 2364 & 27128 & 27256 ROMS | Hardware Info ______________________________________________________________________


11

11

LED

The LED connector is used for the case's power LED to display the ROM blink codes and Restore key presses. The LED can be deactivated in the firmware in order to be able to use the MCU pin 8 (LED pin) for another purpose.

ISP Connection

To program the MCU via ISP, the ISP programmer must be connected as follows.
MOSI | | PCB RESET
MISO | | PCB RESTORE
SCK | | PCB R/W
RESET | | PCB RST
GND | | PCB GND
VCC | | PCB JP4 – pin 1

CBM Switchless Multi ROM for 2364 & 27128 & 27256 ROMS | Hardware Info ______________________________________________________________________

12

12

Experimental

Parts
Some parts on the PCB are for experimental testing and are not needed for normal operation. Unless you want to experiment too.
These parts are: IC5, JP9, connector OE1/OE and D9/D10.


Additional MCU pins


There are two additional MCU pins (9 and 10) on the D9/D10 connector for other purposes.
Jumper
There are two additional jumpers on the PCB back side which are connected by default. JP7 connects the OE signal from the ROM socket pin 22 (OEE) with the flash-chip OE

signal on the PLCC socket pin 24 (OE). If you cut the connection it won't work at all. Unless you make a solder bridge on JP7 or solder JP9 and connect the pins OEE and OE with a jumper.
JP8 connects the resistor R1 to the AVR MCU external reset pin 1. If you cut the connection, you have thanks to the MCUdude MiniCore library an additional MCU pin
22. For this, reset must be disabled via the fuse settings when flashing the MCU. Attention:
ISP programming of the MCU is no longer possible if reset is disabled via fuse settings. In order to be able to flash the MCU you have to use the USB universal programmer.


CBM Switchless Multi ROM for 2364 & 27128 & 27256 ROMS | Hardware Info ______________________________________________________________________

13

13

Experimental

JP9 connects the OE signal from the ROM socket pin 22 (OEE) or the output from IC5, a single “AND” Gate, with the flash-chip OE signal on the PLCC socket pin 24 (OE).
IC5 is a single “AND” Gate for experimental testing. Theoretically, the flash chip could accommodate Character ROM, Basic ROM and Kernal ROM at the same time.
To do this, the MCU firmware would have to be experimentally changed.
OE1/OE2 connector
The OE1/OE2 connector is for the two inputs of the single “AND” Gate.

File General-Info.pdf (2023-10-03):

## CBM Switchless Multi ROM for 2364 & 27128 & 27256 ROMS


## General Info

CBM Switchless Multi ROM for 2364 & 27128 & 27256 ROMS | General Info ______________________________________________________________________

2

2

CBM Switchless Multi ROM for 2364 & 27128 & 27256 ROMS | General Info ______________________________________________________________________

3

3

Table of Contents

CBM Switchless Multi ROM for 2364 & 27128 & 27256 ROMS | General Info ______________________________________________________________________

4

4

Foreword

This is a fork, rework and combination of two repositories from RetroNynjah. https://github.com/RetroNynjah/Switchless-Multi-ROM-for-2364https://github.com/RetroNynjah/Switchless-Multi-ROM-for-27128-27256
I would like to thank RetroNynjah for the brilliant idea and excellent work. After a long search on the internet, I finally found a perfect ROM switcher.

Overview

The Switchless Multi ROM PCB is meant to sit in a ROM socket instead of
a 24-pin 2364 ROM or a 28-pin 27128/27256 ROM.
The AVR microcontroller (referred below as MCU) is connected to the data pins of the ROM socket through a flip-flop that latches the data to give the MCU more time to read the data. It is also connected to some header pins that can be connected to a clock source (r/w signal), a reset signal, a Restore key signal and optionally other signals. It also has an on-board flash chip that contains multiple ROM images.
With the help of an external clock source (r/w signal), the MCU can capture bytes that are passing on the data bus and react to a predefined command string of ”magic bytes” by switching the upper address pins on the flash circuit to switch to a different ROM image. This command string is sent from the a mini Kernal after selecting a kernel ROM. The mini kernel is selected by holding the Restore key for longer than two seconds.
The Switchless Multi ROM has three firmware modes: 2364, 27128 and 27256 mode. The 24-pin or 28-pin hardware mode is selected via jumper.
In 2364 mode, 8Kbyte ROMs, address lines A13 – A18 are set by the MCU.
In 27128 mode, 16Kbyte ROMs, address lines A14 – A18 are set by the MCU.
In 27256 mode, 32Kbyte ROMs, address lines A15 – A18 are set by the MCU.
Mode switching in the MCU firmware is done with bit shifting (flash Bank).
There is an Excel sheet in the tools folder. The macros are harmless, but not necessary. The macros switch Excel error detection off and on. Switches to hexadecimal uppercase letters and filter non hexadecimal letters.
In this Excel sheet you can see the switching between 8k, 16k and 32k ROMs via bank switching (bit shifting). And how the address lines are controlled.

CBM Switchless Multi ROM for 2364 & 27128 & 27256 ROMS | General Info ______________________________________________________________________

5

5

Changes

General
Instead of SMD parts, the board is mostly made of through-hole parts (THT). This makes it easier to solder for hobbyists, and reflashing the flash-chip.

The Switchless Multi ROM can be used as a replacement for a 2364 24-pin ROM or a 27128 / 27256 28-pin ROM.
Hardware
MCU Port C (PC0-PC5) controls the address lines A13 - A18.
MCU Port B0 (pin 8) controls the LED.
Switching between a 24-pin ROM and a 28-pin ROM is done via jumpers. Use of the case's power LED instead of the invisible on-board LED. Firmware
The address lines are set with direct port manipulation instead of setting each address line individually.
Using the Pololu FastGPIO library makes the source code easier to understand and readable. The firmware is faster and the size smaller.
The firmware switches between 8k, 16k and 32k ROM´s via flash bank switching. The LED blinking can be easy disabled.
Mini Kernal
Changed the ”magic bytes” command string and deactivated sprites.

Notes

The hardware is not compatible with the RetroNynjah firmware. The MCU firmware currently does not support floppy drives.

CBM Switchless Multi ROM for 2364 & 27128 & 27256 ROMS | General Info ______________________________________________________________________

6

6

Requirements

Software
To compile the firmware for the MCU, the Arduino IDE needs to be installed. See: https://www.arduino.cc/en/software
MCUdude MiniCore must be installed using the Arduino IDE's Board Manager. See: https://github.com/MCUdude/MiniCore
To use the FastGPIO library from Pololu, it must be installed using the Arduino IDE´s Library Manager.
See: https://github.com/pololu/fastgpio-arduino
In order to compile the menu mini Kernal, CBM prg Studio must be installed. See: https://www.ajordison.co.uk/index.html
If you want to flash the MCU firmware via ISP, I recommend AVRDUDESS. See: https://github.com/ZakKemble/AVRDUDESS
Hardware
A USB universal programmer is required to flash the MCU firmware and the flash-chip memory. Like the TL866II Plus programmer, for example.
To flash the MCU firmware via ISP, I recommend the USBASP AVR Programmer. Use Zadig to install the USBASP driver for Windows.
See: https://www.instructables.com/USBASP-Installation-in-Windows-10/ Soldering tools, a Multimeter, a PLCC32-DIP32 adapter.
PCB
I recommend having the PCB made by a manufacturer, such as PCBWAY or ELECROW. Ten boards cost around €15 with shipping. The gerber zip file is required for production.

CBM Switchless Multi ROM for 2364 & 27128 & 27256 ROMS | General Info ______________________________________________________________________

7

7

Preparation

To install the Switchless Multi ROM on a CBM mainboard, several preparations must be made. If the Kernal ROM IC is soldered in, it must be removed and a socket installed in its place.
Although the Kernal IC is located at different positions, it can be found via the label.
On the VIC20 mainboard, the label is UE12. Commodore identifier 901486.
See: http://www.zimmers.net/anonftp/pub/cbm/schematics/computers/vic20/parts.txt On the C64 mainboard, the label is U4. Commodore identifier 901227.
See: http://www.zimmers.net/anonftp/pub/cbm/schematics/computers/c64/README On the SX-64 mainboard, the label is U4. Commodore identifier 251104.
See: http://www.zimmers.net/anonftp/pub/cbm/schematics/computers/c64/README On the C64C mainboard, the label is U4. Commodore identifier 251913.
See: http://www.zimmers.net/anonftp/pub/cbm/schematics/computers/c64/README On the C128 mainboard, the label for the C64C mode ROM is U32. Identifier 251913. On the C128 mainboard, the label for the C128 mode ROM is U35. Identifier 318020. On the C128DCR mainboard, the label is U32. Commodore identifier 318023.

See: http://www.zimmers.net/anonftp/pub/cbm/schematics/computers/c128/parts.txt http://www.zimmers.net/anonftp/pub/cbm/firmware/computers/c128/128ROMs.readme

Furthermore, the Switchless Multi ROM required 3 additional signals: r/w (available on any CIA pin 22) reset (available on any CIA pin 34) Restore key (available on keyboard connector pin 3)

Cables can be soldered directly to the pins on the back of the CBM motherboard described above or connected through the hole. Through-hole connections can be derived from these signals and used with pin headers instead. For such vias, the solder must be removed using a desoldering station or a soldering iron and a desoldering pump and then the pin headers can be installed there. This enables the use of Dupont cables. CBM mainboard schematics can be found at: http://www.zimmers.net/anonftp/pub/cbm/schematics/computers/
These signals must be connected to the control connector on the circuit board. r/w | pin 1 Restore key | pin 2 Reset | pin 3

CBM Switchless Multi ROM for 2364 & 27128 & 27256 ROMS | General Info ______________________________________________________________________

8

8

Parts

Parts for the SMD Version V3.0 can be found in the hardware folder.
The AVR ATmega model is not critical. The firmware requires less than 2KB of MCU flash memory. I have tested Atmega48A, 328P and they have worked for me.
For 1MHz systems, it is enough with 16MHz.
IC5, JP9, connector OE1/OE2 and connector D9/D10 are optional and not necessary. These parts are for experimental purposes only. Theoretically, the flash chip could accommodate Character ROM, Basic ROM and Kernal ROM at the same time.
I usually order my components from the distributor tme.eu.

Additional Info

Hardware information can be found in the hardware folder. Application information is in the applications folder.
RetroNynjah´s Guides are in the retroninja folder. I recommend reading these guides too. You can find a lot of useful information. For example, many images where you can find the signals, r/w, reset and the Restore key on the CBM mainboards.
Keep it simple.
Nr. | Amount | Component | Part | Description | Comment
1 | 1 | IC1 | SST39SF0x0 | 32-PLCC Flash | SST39SF010/20/40
2 | 1 | IC2 | ATmega MCU | 28-pin PDIP | Atmega48/88/168/328
3 | 1 | IC3 | 74HCT273 | 20-pin PDIP | Flip-Flop
4 | 1 | IC4 | 74HCT1G04 | SOT23-5 1 * Inverter | Only needed if clock needs inverting
5 | 1 | IC5 | 74HCT1G08 | SOT23-5 1 * AND Gate | Optional
6 | 1 | Q1 | 20MHz Crystal | HC49/4H THT | 16MHz is ok for 1MHz systems
7 | 4 | C1 - C4 | 100nF capacitor | 2.5mm THT
8 | 2 | C5, C6 | 27pF capacitor | ceramic 2.5mm THT | 22pF works fine too
9 | 1 | R1 | 10kΩ resistor | 0207 THT
10 | 1 | R2 | 560Ω resistor | 0207 THT
11 | 1 | IC1 Socket | PLCC Socket | 32-pin THT | M-PLCC 32 T
12 | 1 | IC2 Socket | IC Socket 28-pin | 7.62mm THT | For AVR
13 | 1 | IC3 Socket | IC Socket 20-pin | 7.62mm THT | For Flip-Flop
14 | 2 | ROM Headers | 14-Pin Header | Pitch2.54mm | Use machined or flat pins - not square
15 | 1 | Connector | 20-Pin Header | Straight 2.54mm | For Connection and Jumper
16 | 1 | Connector | 20-Pin Header | Angeled 2.54mm | For Connection and Jumper
17 | 5 | J1 - J4, J9 | Jumper | Pitch2.54mm | Jumpers for configuration
18 | 1 | ROM Socket | IC Socket 28-pin | 15.24mm THT | Optional additional machined Socket
19 | 1 | ROM Socket | IC Socket 24-pin | 15.24mm THT | Optional additional machined Socket

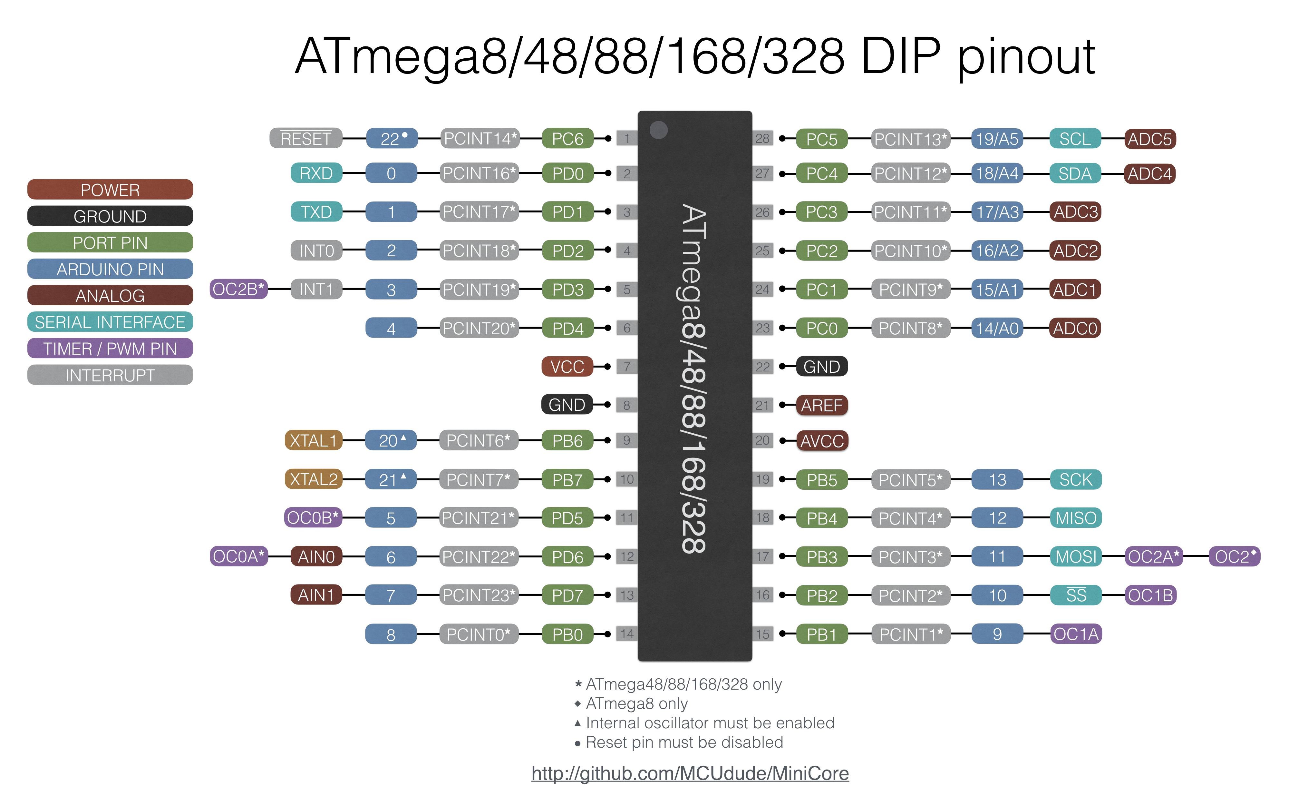
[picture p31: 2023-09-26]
tools/atmega-pinout.jpg

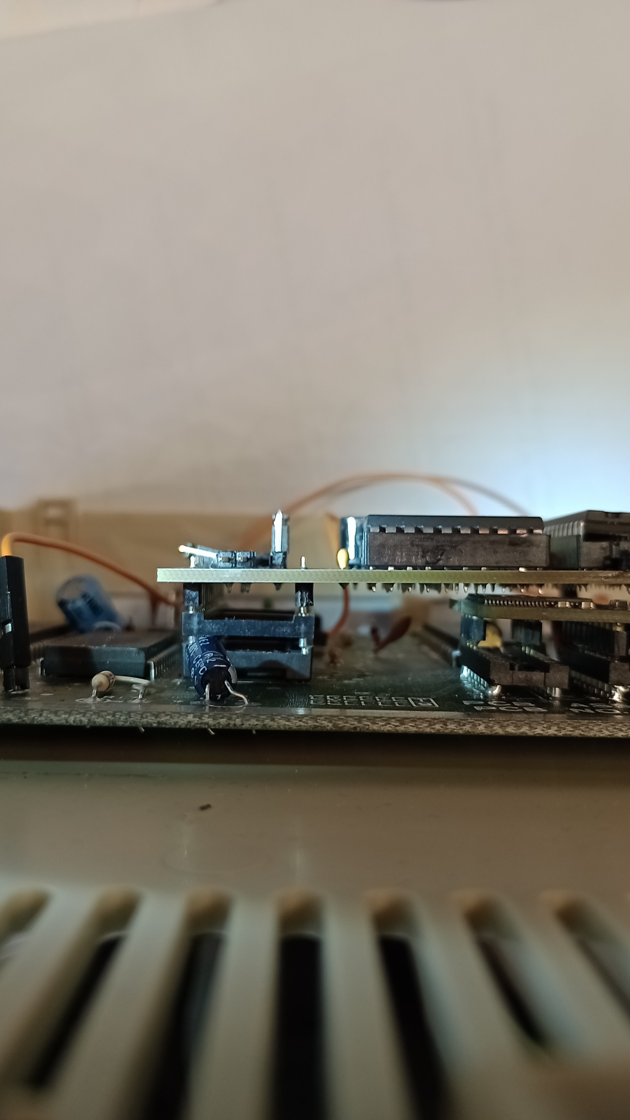
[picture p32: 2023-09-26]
pictures/additional-ic-socket.jpg

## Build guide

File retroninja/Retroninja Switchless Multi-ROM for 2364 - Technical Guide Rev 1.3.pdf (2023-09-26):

# Retroninja Switchless Multi-ROM for 2364

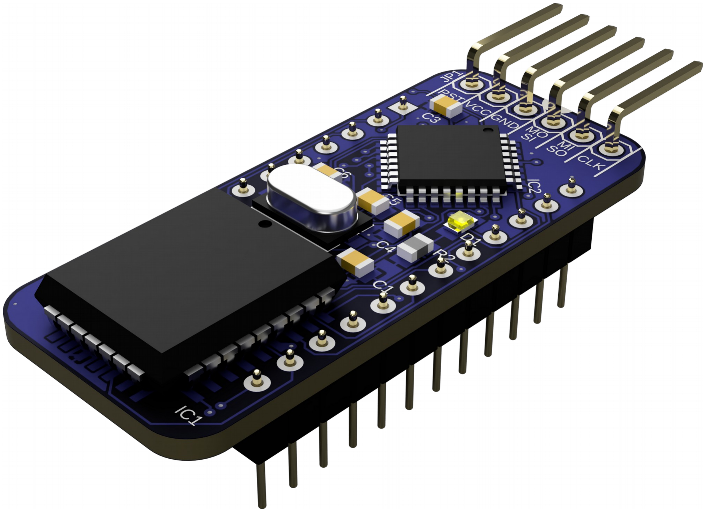
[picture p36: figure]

# Technical Guide

Retroninja Switchless Multi-ROM for 2364 | Technical Guide Version 1.3

## Table of Contents

# Background

I first created this ROM switcher as a DOS ROM switcher for the Commodore 1541 disk drive which in turn was derived from a Commodore 1541-II drive ROM switch that I had previously designed.
I realized that it can be used for a lot of other equipment that is using similar ROMs so it was re-branded and modified making the clock inverter optional.

# Theory of operation

The circuit is meant to sit in a ROM socket instead of a 24-pin 2364 ROM.
The AVR microcontroller (MCU) is connected to the data pins of the ROM socket through a flip-flop that latches the data to give the MCU more time to read the data. It's also connected to some header pins that can be connected to a clock source, a reset line and optionally other signals. It also has an on-board flash chip that contains multiple ROM images.
With the help of an external clock source, the MCU can capture bytes that are passing on the data bus and react to a predefined string of ”magic bytes” by switching the upper address pins on the flash circuit to switch to a different ROM image.
The flip-flop triggers on positive-edge of clock and if data is arriving on the bus at the negative edge of the clock signal then the clock source needs to be inverted for the flip-flop to latch the data correctly. This can be done by installing the inverter gate at IC5 and configuring solder jumper SJ1 for inverted clock.
The need for this differs between implementations depending on how the magic bytes ends up on the bus. The address pins above A12 (A13-A18) are controlled by the MCU which gives a maximum of 64*8KByte switchable ROMs.
An onboard LED can be used for diagnostic blinking or other feedback.

# Usage examples

The two use cases I've used it in is for switching JiffyDOS ROM in Commodore disk drives and Kernal in the Commodore 8-bit computers but it should be usable for other things too.

Commodore 1541 DOS ROM Switcher
The MCU source code for the 1541 ROM switch can be found under samples in the GitHub repository at: https://github.com/RetroNynjah/Switchless-Multi-ROM-for-2364
At power on, the MCU in the ROM switcher reads address 0 from its internal EEPROM to find out which ROM it should select, sets the A13-A18 address pins on the flash chip accordingly and resets the drive to make sure it’s booted with the correct image. This can be noticed when the drive is powered on and the drive initializes and stops spinning and then spins up again briefly during the switch reset.
It then starts listening for a switch command.
Even at a clock speed of 16 MHz, reading and analyzing data on a 1MHz data bus can be a challenge so the data on the 1541 data bus is buffered in the switcher by a 74AHCT273 flip-flop that is clocked by the Write signal on the 6502 MPU in the 1541. By clocking the data with the R/W signal we filter out irrelevant bus traffic and the flip-flop holds the relevant data until the next R/W cycle. This gives the MCU a little more time to read the data from the flip-flop.
The MCU listens for a predefined sequence of bytes in reverse order (MORNR@) and once the sequence is found, it treats the following numeric character as the target ROM image number. The reverse order of the characters on the bus is why the image number must be specified at the beginning of the command.

The MCU sets address pins A13-A18 on the flash chip according to image selection and it stores the ROM number at address 0 of its internal EEPROM for use at next power-on. It then resets the drive by toggling the IEC reset line.
The command can be sent from basic on a computer such as C64 or C128 by utilizing any disk drive command that contains text strings such as:

The LOAD command in the example will return a file not found error but you should see the drive switch ROM and perform a drive reset. The ROM switch LED will blink 2 times to indicate that image 2 was selected.
When building a 1541 ROM switch you should bridge the solder jumper like this:
SJ1
Inverted Clock | Non-inverted Clock

Note: To invert clock we must also install IC5

Some pins on the switch needs to be connected to the right signals in the drive. These signals can be connected to the drive using test clips but to have a secure installation it's better to solder the cables to the bottom of the PCB.
Switch pin | Drive signal
CLK | R/W (6502 pin 34)
MOSI | RESET (Middle pin of IEC DIN connector)

This switch only suits the 1541 and clones that has 24-pin ROM sockets.
1541C/1541-II drives and some clones have 28-pin 27128 type ROMs. I have another Multi-ROM version that is compatible with those in the following repository: https://github.com/RetroNynjah/Switchless-Multi-ROM-for-27128-27256

Commodore 64 longboard menu-driven Kernal switch
The MCU source code and Mini-Kernal source code for the C64 longboard kernal switch can be found under applications in the GitHub repository at:
https://github.com/RetroNynjah/Switchless-Multi-ROM-for-2364
At power on, the MCU in the Kernal switch reads address 0 from its internal EEPROM to find out which Kernal it should select, sets the A13-A18 address pins on the flash chip accordingly and resets the computer to make sure it’s booted with the correct image.
If at any time, restore is pressed and held for a few seconds the MCU will detect this and switch to Kernal 0 which is a menu Kernal. For this application I created a custom Mini-Kernal for the C64 that displays a list of Kernals to choose from.

LOAD “2@RNROM”,8

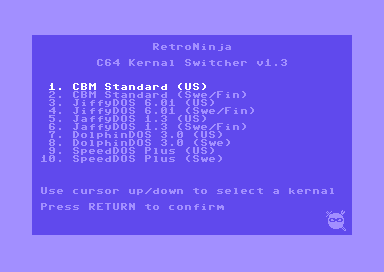
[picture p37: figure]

When the user selects a Kernal image from the menu, the Mini-Kernal writes a predefined switching command to RAM along with a byte that indicates the selected image number. It does this over and over. Example of the command: RNROM64#1 where 1 is a byte with value 0x01 that tells the switch that we want to switch to kernal image 1.
The Kernal switch now captures the command from the data bus, writes the selected kernal number to the MCU EEPROM for future use, then it switches the address pins A13-A18 accordingly. It then pulls the reset line briefly to make the computer restart using the new Kernal. The computer will continue to start up using this Kernal until a new choice is made.
The flash is populated with the Mini-Kernal followed by up to 10*8 KB Kernals. It would in theory be possible to add up to 63 kernals if both the Mini-Kernal and the MCU firmware was modified in some way to accommodate that many Kernal images.
Here's an example layout that fills out an SST39SF010A:

If the same layout would be used with a larger flash chip it should be duplicated to fill out the flash. When building a C64 kernal switch you should bridge the solder jumpers like this:
SJ1
Inverted Clock | Non-inverted Clock

Note: As we don't invert the clock we don't need to install IC5

Some pins on the switch needs to be connected to the right signals in the computer. These signals can be connected to various ICs in the computer using test clips but to have a secure installation it's better to solder the cables to vias on the PCB. See pictures in the samples directory of the GitHub repository.
Switch pin | Computer signal
CLK | R/W
MISO | RESTORE
MOSI | RESET
Mini-Kernal | CBM Kernal | JiffyDOS US | JiffyDOS SE | JiffyDOS DK | JaffyDOS US | JaffyDOS SE | SpeedDOS | SpeedDOS | DolphinDOS | DolphinDOS | Mini-Kernal | Mini-Kernal | Mini-Kernal | Mini-Kernal | Mini-Kernal
8kB | 8kB | 8kB | 8kB | 8kB | 8kB | 8kB | 8kB | 8kB | 8kB | 8kB | 8kB | 8kB | 8kB | 8kB | 8kB

This C64 Kernal switch only suits the C64 longboards which have a 24pin ROM and has basic in a separate ROM. All C64 motherboards are longboards except for PCB 250469 which can be found in newer C64C's. The C64 shortboard (PCB 250469) have 28-pin 27128 type Kernal ROMs and I have another Multi-ROM version that is compatible with those in the following repository: https://github.com/RetroNynjah/Switchless-Multi-ROM-for-27128-27256

Commodore VIC-20 menu-driven Kernal switch
The MCU source code and Mini-Kernal source code for the VIC-20 kernal switch can be found under applications in the GitHub repository at:
https://github.com/RetroNynjah/Switchless-Multi-ROM-for-2364
At power on, the MCU in the Kernal switch reads address 0 from its internal EEPROM to find out which Kernal it should select, sets the A13-A18 address pins on the flash chip accordingly and resets the computer to make sure it’s booted with the correct image.
If at any time, restore is pressed and held for a few seconds the MCU will detect this and switch to Kernal 0 which is a menu Kernal. For this application I created a custom Mini-Kernal for the VIC-20 that displays a list of Kernals to choose from.

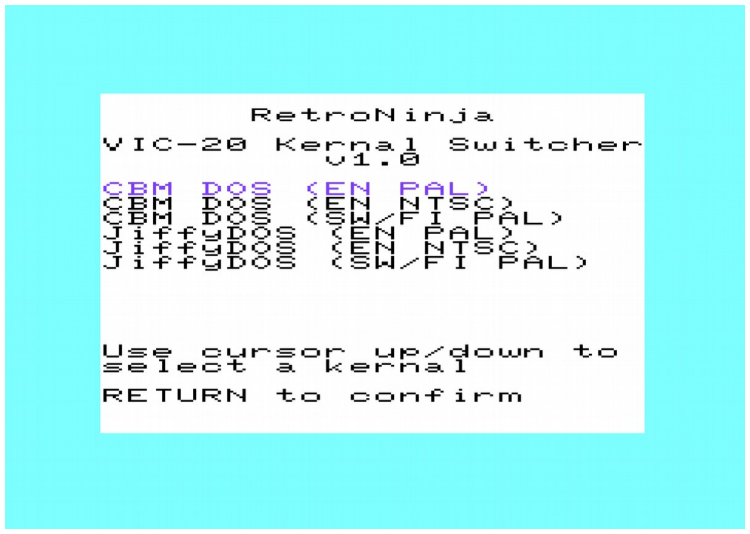
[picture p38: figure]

When the user selects a Kernal image from the menu, the Mini-Kernal writes a predefined switching command to RAM along with a byte that indicates the selected image number. It does this over and over. Example of the command: RNROM20#1 where 1 is a byte with value 0x01 that tells the switch that we want to switch to kernal image 1.
The Kernal switch now captures the command from the data bus, writes the selected kernal number to the MCU EEPROM for future use, then it switches the address pins A13-A18 accordingly. It then pulls the reset line briefly to make the computer restart using the new Kernal. The computer will continue to start up using this Kernal until a new choice is made.
The flash is populated with the Mini-Kernal followed by up to 10*8 KB Kernals. It would in theory be possible to add up to 63 kernals if both the Mini-Kernal and the MCU firmware was modified in some way to accommodate that many Kernal images.
Here's an example layout that fills out an SST39SF010A:

If the same layout would be used with a larger flash chip it should be duplicated to fill out the flash.

Mini-Kernal | CBM EN PAL | CBM EN NTSC | CBM SE PAL | Jiffy EN PAL | Jiffy EN NTSC | Jiffy SE PAL | Mini-Kernal | Mini-Kernal | Mini-Kernal | Mini-Kernal | Mini-Kernal | Mini-Kernal | Mini-Kernal | Mini-Kernal | Mini-Kernal
8kB | 8kB | 8kB | 8kB | 8kB | 8kB | 8kB | 8kB | 8kB | 8kB | 8kB | 8kB | 8kB | 8kB | 8kB | 8kB

When building a VIC-20 kernal switch you should bridge the solder jumpers like this: SJ1
Inverted Clock | Non-inverted Clock

Note: As we don't invert the clock we don't need to install IC5

Some pins on the switch needs to be connected to the right signals in the computer. These signals can be connected to various ICs in the computer using test clips but to have a secure installation it's better to solder the cables to vias on the PCB. See pictures in the samples directory of the GitHub repository.
Switch pin | Computer signal
CLK | R/W
MISO | RESTORE
MOSI | RESET

# Assembling the module

The PCB is small and a bit difficult to solder but it can be hand soldered. The reason for the small size is space constraints in some Commodore drives that this module was designed for originally. Other drives any devices may have the same constraints so keeping it small is good for compatibility.
The flash chip (PLCC) is the trickiest part to solder and If you find it hard to hand solder I recommended reflow soldering the top side using stencil and solder paste. Then solder the bottom side by hand and finally solder the pin headers.
There is a solder jumper on the bottom that must be configured.
If you configure SJ1 for inverted clock then you must also install IC5. Otherwise you can leave it out. It will only be used when SJ1 is configured for inverted clock.
Note: Don't forget to program the flash before soldering!

# Parts

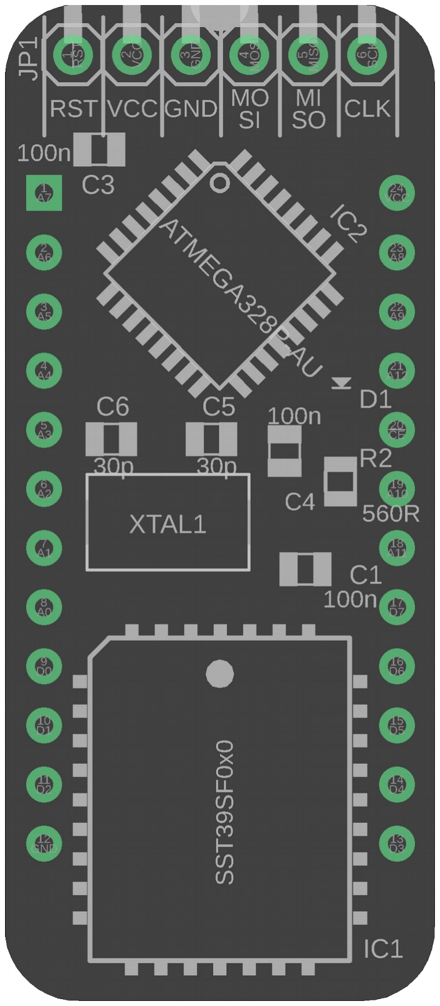
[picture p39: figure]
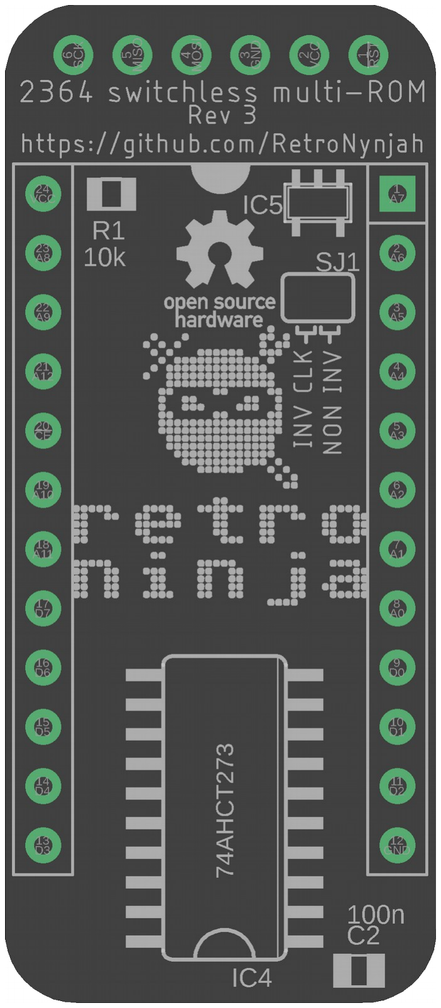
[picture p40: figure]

Top side is to the left, bottom side is to the right.
Component | Part | Description | Comment
JP1 | Header | 6-pin right-angle
D1 | LED | 0805 LED
C1, C2, C3,C4 | 100nF capacitor | 0805 ceramic capacitor
C5, C6 | 30pF capacitor | 0805 ceramic capacitor | 22pF works fine too
XTAL1 | ECS-160-20-3X-TR | 16MHz Crystal 7.0x4.1 mm
R1 | 10kΩ resistor | 0805 Resistor
R2 | 560Ω resistor | 0805 Resistor
IC1 | SST39SF0x0 | 32-PLCC Flash 4.5-5.5V | SST39SF010/20/40
IC2 | ATmega MCU | 32-TQFP MCU | Atmega48/88/168/328
IC3 | Headers | 2 header rows, 14 pin | Use machined or flat pins - not square
IC4 | 74AHCT273 | 20-SOIC 5.3mm Flip-Flop
IC5 | 741G04 | SOT23-5 1 x Inverter | Only needed if clock needs inverting
The ATmega model is not critical. The firmware requires less than 2KB of MCU flash. I have tested Atmega48, 48A, 48PA, 88A, 328P and they have worked for me. Any other pin-compatible ATmega could work too depending on your application.

# Programming the microcontroller

The firmware can be flashed using the 6-pin ISP header. The source code is written for Arduino and programming the firmware can be done directly from the Arduino IDE using an ISP programmer.
If you are using an Atmega328 it can be programmed as an Arduino UNO. The other variants require custom board definitions. I have used the MiniCore from MCUdude (https://github.com/MCUdude/MiniCore) with default board settings.
If you can't or don't want to use Arduino I have some precompiled hex files for the Kernal switch and drive ROM switch along with fuse configurations and syntax examples for how to program them using avrdude. These can be found under the Examples folder in my GitHub repository.

# Programming the flash chip (ROM)

The flash chip needs to be programmed before soldering it. If you need to reprogram the flash later it must first be desoldered and then resoldered again after reprogramming.
You need to concatenate all your images into one file and fill up any empty space in flash with valid extra images to avoid bricking your host device if an incorrect image number is selected. If that would happen the EEPROM can be reset by re-flashing the firmware.
All images must be 8kB in size.

# Document revision history

1.0 Initial version
1.1 Cover page image corrected
1.2 BOM Corrected
1.3 VIC-20 Kernal switch section added

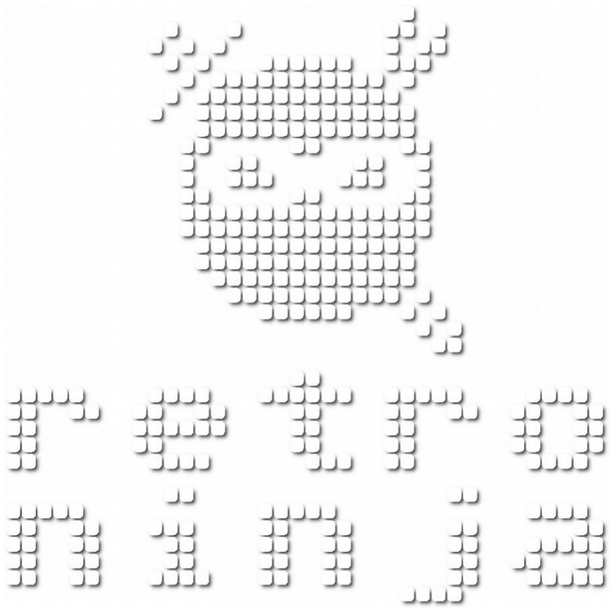
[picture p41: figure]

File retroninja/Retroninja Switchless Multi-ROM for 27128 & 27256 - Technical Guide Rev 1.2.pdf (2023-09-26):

# Retroninja Switchless Multi-ROM for 27128

& 27256

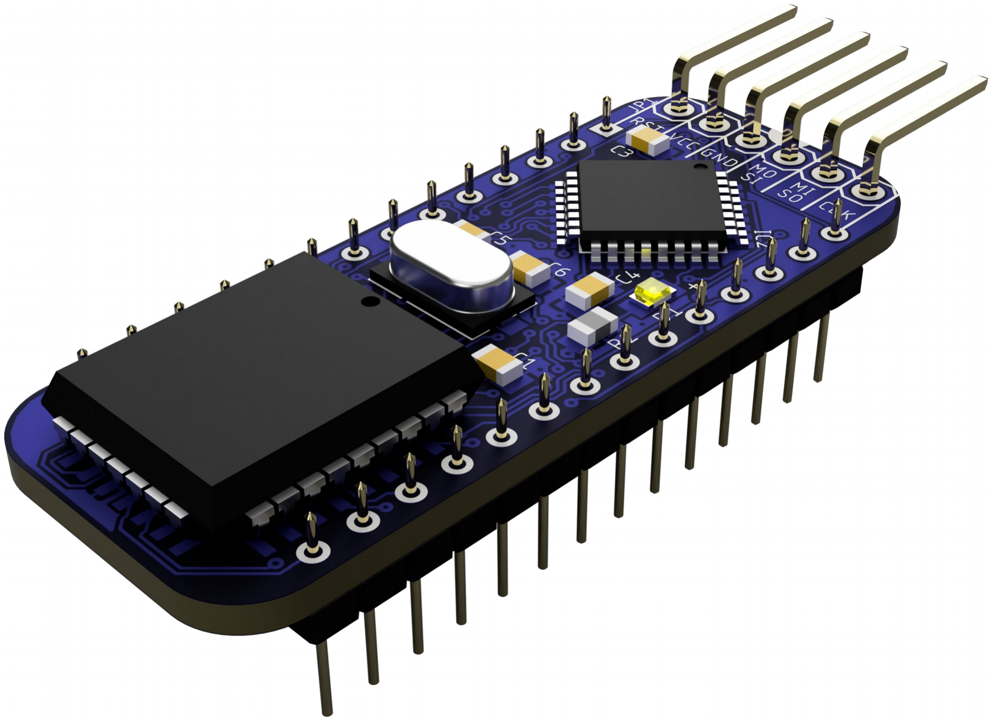
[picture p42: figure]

# Technical Guide

Retroninja Switchless Multi-ROM for 27128 & 27256 | Technical Guide Version 1.2

## Table of Contents

# Background

I first created this ROM switcher as a DOS ROM switcher for the Commodore 1541-II disk drive which uses a 27128 compatible ROM. The space in the 1541-II is very limited. That's why the module is so small and has to use SMD components.
I realized that it can be used for a lot of other equipment that is using similar ROMs so it was re-branded and upgraded to support switching 27256 ROM images too.

# Theory of operation

The circuit is meant to sit in a ROM socket instead of a 28-pin 27128/27256 ROM.
The AVR microcontroller (MCU) is connected to the data pins of the ROM socket through a flip-flop that latches the data to give the MCU more time to read the data. It's also connected to some header pins that can be connected to a clock source, a reset line and optionally other signals. It also has an on-board flash chip that contains multiple ROM images.
With the help of an external clock source, the MCU can capture bytes that are passing on the data bus and react to a predefined string of ”magic bytes” by switching the upper address pins on the flash circuit to switch to a different ROM image.
The flip-flop triggers on positive-edge of clock and if data is arriving on the bus at the negative edge of the clock signal then the clock source needs to be inverted for the flip-flop to latch the data correctly. This can be done by installing the inverter gate at IC5 and configuring solder jumper SJ1 for inverted clock.
The need for this differs between implementations depending on how the magic bytes ends up on the bus. The module has two modes: 27128 and 27256 mode. The mode is selected using a solder jumper. In 27128 mode the A14 address pin on the flash chip is controlled by the MCU giving the MCU five address pins (A14-A18) to use which gives a maximum of 32*16KByte ROMs. In 27256 mode the A14 pin is controlled by the host system leaving four address pins (A15-A18) to the MCU which gives a maximum of 16*32KByte ROMs. An onboard LED can be used for diagnostic blinking or other feedback.

# Usage examples

The two use cases I've used it in is for switching JiffyDOS ROM in Commodore disk drives and Kernal in the Commodore 8-bit computers but it should be usable for other things too.

Commodore 1541-II/1571/1581 DOS ROM Switcher
The MCU source code for the 1541-II/1571/1581 ROM switch can be found under applications in the GitHub repository: https://github.com/RetroNynjah/Switchless-Multi-ROM-for-27128-27256
At power on, the MCU in the ROM switcher reads address 0 from its internal EPROM to find out which ROM it should select, sets the A14-A18 (or A15-A18) address pins on the flash chip accordingly and resets the drive to make sure it’s booted with the correct image. This can be noticed when the drive is powered on and the drive initializes and stops spinning and then spins up again briefly during the switch reset.
It then starts listening for a switch command.
Even at a clock speed of 20 MHz, reading and analyzing data on a 1-2MHz data bus can be quite a challenge so the data on the drive data bus is buffered in the switcher by a 74AHCT273 flip-flop that is clocked by the Write signal on the 6502 MPU in the drive. By clocking the data with the R/W signal we filter out irrelevant bus traffic and the flip-flop holds the relevant data until the next R/W cycle. This gives the MCU a little more time to read the data from the flip-flop.

The MCU listens for a predefined sequence of bytes in reverse order (MORNR@) and once the sequence is found, it treats the following numeric character as the target ROM image number. The reverse order of the characters on the bus is why the image number must be specified at the beginning of the command.
The MCU sets address pins A14-A18 (or A15-A18) on the flash chip according to image selection and it stores the ROM number at address 0 of its internal EPROM for use at next power-on. It then resets the drive by toggling the reset line.
The command can be sent from basic on a computer such as C64 or C128 by utilizing any disk drive command that contains text strings such as:

If the computer is equipped with JiffyDOS and the correct drive has been selected using CTRL-D or similar, DOS wedge commands can be used for switching ROM:

The commands in the above examples will return a file not found error but you should see the drive switch ROM and perform a drive reset and turn of the error LED. The ROM switch LED will blink 2 times to indicate that image 2 was selected.
When building a 1541-II ROM switch you should bridge the solder jumpers like this:
SJ1
Inverted Clock | Non-inverted Clock

Note: To invert clock we must also install IC5

SJ2
27256 | 27128

And for a 1571 and 1581 ROM switch the solder jumpers should be configured like this: SJ1
Inverted Clock | Non-inverted Clock

Note: To invert clock we must also install IC5

SJ2
27256 | 27128

Some pins on the switch needs to be connected to the right signals in the drive. These signals can be connected to the drive using test clips but to have a secure installation it's better to solder the cables to the bottom of the PCB.

LOAD “2@RNROM”,8

@2@RNROM

Switch pin | Drive signal
CLK | R/W (6502 pin 34)
MOSI | RESET (Middle pin of IEC DIN connector)

This switch only suits the 1541-II/1571/1581 and clones that has 28-pin ROM sockets.
1541 drives and some of it's clones have 24-pin 2364 type ROMs and I have another Multi-ROM version that is compatible with those in the following repository: https://github.com/RetroNynjah/Switchless-Multi-ROM-for-2364

Commodore 64 shortboard/C128 menu-driven Kernal switch
The MCU source code and Mini-Kernal source code for the C64 shortboard/C128 kernal switch can be found under samples in the GitHub repository at: https://github.com/RetroNynjah/Switchless-Multi-ROM-for-27128-27256
At power on, the MCU in the Kernal switch reads address 0 from its internal EPROM to find out which Kernal it should select, sets the A14-A18 (or A15-A18) address pins on the flash chip accordingly and resets the drive to make sure it’s booted with the correct image.
If at any time, restore is pressed and held for a few seconds the MCU will detect this and switch to Kernal 0 which is a menu Kernal. For this application I created a custom Mini-Kernal for the C64 and one for the C128 that display lists of Kernals to choose from.


When the user selects a Kernal image from the menu, the Mini-Kernal writes a predefined switching command to RAM along with a byte that indicates the selected image number. It does this over and over. Example of the command: RNROM64#1 or RNROM128#1 where 1 is a byte with value 0x01 that tells the switch that we want to switch to kernal image 1.
The Kernal switch now captures the command from the data bus, writes the selected kernal number to the MCU EPROM for future use, then it switches the address pins A14/A15-A18 accordingly. It then pulls the reset line briefly to make the computer restart using the new Kernal. The computer will continue to start up using this Kernal until a new choice is made.
Having different commands for the platforms makes it possible to equip both the ROM sockets in a Commodore 128 (not CR/DCR) with Kernal switches and keep them separated.
In this case both switches will trigger their menus when RESTORE is held as the MCUs don't know if they are being addressed or not. The MCUs will switch back to the previous image if they detect that a reset is being performed by something other than themselves.
To activate the C64 switch menu in a C128 you hold the CBM key together with RESTORE. When selecting an image from the C64 kernal menu you hold CBM while you press RETURN to make it boot into C64 mode with the new Kernal.
The C128CR/DCR doesn't have a separate ROM for the C64 part and doesn't need an separate switch for C64 mode but it needs to have the C64 Basic and Kernal images bundled in the same flash ROM as the C128 Kernals. This switch will switches Kernals for both C64 mode and C128 mode at the same time. This can be both good or bad depending on how you combine your Kernals.
It also needs to have the Mini-Kernals modified so that both Mini-Kernals uses the same switching
command such as RNROMDCR#1 and have an MCU firmware compatible with 27256 switching.
I have not yet created a firmware for that as I don't have access to a CR/DCR.
For the C128, the flash is populated with a 16 KB C128 Mini-Kernal followed by up to 31*16 KB Kernals (good luck finding more than a couple). It's wise to fill all empty space in flash with enough copies of the Mini-Kernal.

For the C64, the flash is populated with a 16 KB combination of 8 KB basic ROM and 8 KB Mini-Kernal followed by up to 31*16 KB Basic+Kernal combinations.
Here's an example ROM layout for a C64 shortboard or the C64 Kernal in the C128 that fits an SST39SF010A:

Example for a C128 with an SST39SF010A:

Example for a C128CR/DCR with an SST39SF010A:

As both C64 mode and C128 mode Kernals are in the same ROM a larger flash chip may be needed to accommodate all Kernals. If you have more C64 Kernals than C128 Kernals you still need to fill the vacant C128 slots with working Kernals such as a stock CBM kernal or you will never be able to start the C128 into C64 mode either.
When building a C64/C128 kernal switch you should bridge the solder jumpers like this:
SJ1
Inverted Clock | Non-inverted Clock

Note: As we don't invert the clock we don't need to install IC5

| SJ2 (non CR/DCR)
27256 | 27128

SJ2 (CR/DCR)
27256 | 27128
Basic | Mini-Kernal | Basic | CBM Kernal | Basic | JiffyDOS US | Basic | JiffyDOS SE | Basic | JiffyDOS DK | Basic | JaffyDOS | Basic | DolphinDOS | Basic | SpeedDOS
8kB | 8kB | 8kB | 8kB | 8kB | 8kB | 8kB | 8kB | 8kB | 8kB | 8kB | 8kB | 8kB | 8kB | 8kB | 8kB
16kB | | 16kB | | 16kB | | 16kB | | 16kB | | 16kB | | 16kB | | 16kB
C64 Basic | 64 Mini | 128 Mini | C64 Basic | 64 CBM krnl | 128 CBM krnl | C64 Basic | 64 Jiffy US | 128 Jiffy US | C64 Basic | 64 Jiffy SE | 128 Jiffy SE
8kB | 8kB | | 8kB | 8kB | | 8kB | 8kB | | 8kB | 8kB
16kB | | 16kB | 16kB | | 16kB | 16kB | | 16kB | 16kB | | 16kB
Mini-Kernal | CBM Kernal | JiffyDOS US | JiffyDOS SE | JiffyDOS DK | Mini-Kernal | Mini-Kernal | Mini-Kernal
16kB | 16kB | 16kB | 16kB | 16kB | 16kB | 16kB | 16kB

Some pins on the switch needs to be connected to the right signals in the computer. These signals can be connected to various ICs in the computer using test clips but to have a secure installation it's better to solder the cables to vias on the PCB. See pictures in the samples directory of the GitHub repository.
Switch pin | Computer signal
CLK | R/W
MISO | RESTORE
MOSI | RESET

This switch when configured as a C64 Kernal switch only suits the C64 shortboard (PCB 250469) and the C64 part of the C128. C64 longboards have 24-pin 2364 type Kernal ROMs and I have another Multi-ROM version that is compatible with those in the following repository: https://github.com/RetroNynjah/Switchless-Multi-ROM-for-2364

# Assembling the module

The PCB is small and a bit difficult to solder but it can be hand soldered. The reason for the small size is space constraints in the Commodore 1541-II disk drives that this PCB was initially designed for. Other drives such as 1571 and 1581 have the same constraints.
The flash chip (PLCC) is the trickiest part to solder and I recommended reflow soldering the top side using stencil and solder paste. Then solder the bottom side by hand and finally solder the pin headers.
There are two solder jumpers on the bottom that must be configured.
If you configure SJ1 for inverted clock then you must also install IC5. Otherwise you can leave it out. It will only be used when SJ1 is configured for inverted clock.
Note: Don't forget to program the flash before soldering!

# Parts

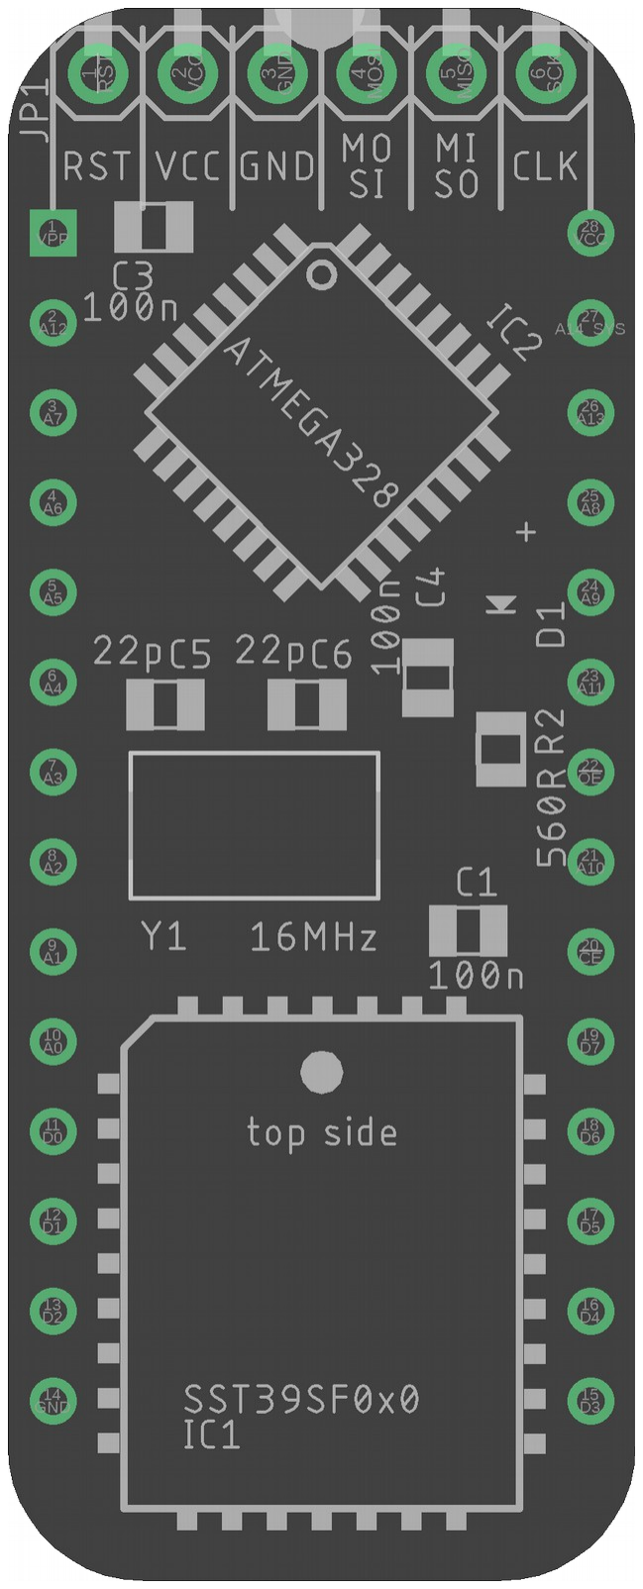
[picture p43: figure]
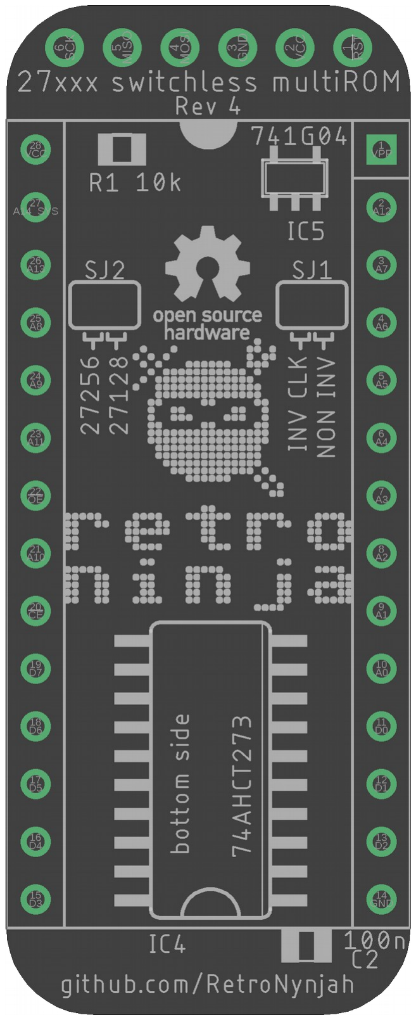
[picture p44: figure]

Top side is to the left, bottom side is to the right.
Component | Part | Description | Comment
JP1 | Header | 6-pin right-angle
D1 | LED | 0805 LED
C1, C2, C3,C4 | 100nF capacitor | 0805 ceramic
C5, C6 | 30pF capacitor | 0805 ceramic | 22pF works fine too
Y1 | ECS-200-20-3X-TR | 20MHz Crystal | 16MHz is ok for 1MHz systems
R1 | 10kΩ resistor | 0805 Resistor
R2 | 560Ω resistor | 0805 Resistor
IC1 | SST39SF0x0 | 32-PLCC Flash 4.5-5.5V | SST39SF010/20/40
IC2 | ATmega MCU | 32-TQFP MCU | Atmega48/88/168/328
IC3 | Headers | 2 header rows, 14 pin | Use machined or flat pins - not square
IC4 | 74AHCT273 | 20-SOIC 5.3mm Flip-Flop
IC5 | 741G04 | SOT23-5 1 x Inverter | Only needed if clock needs inverting
The ATmega model is not critical. The firmware requires less than 2KB of MCU flash. I have tested Atmega48, 48A, 48PA, 48PB, 88A, 328P and they have worked for me. Any other pin-compatible ATmega could work too depending on your application but it must be able to run at 20MHz if you are going to use it in a 2MHz system such as 1571/1581. For 1MHz systems it is enough with 16MHz.

# Programming the microcontroller

The firmware can be flashed using the 6-pin ISP header. The source code is written for Arduino and programming the firmware can be done directly from the Arduino IDE using an ISP programmer.
If you are using an Atmega328 it can be programmed as an Arduino UNO. The other variants require custom board definitions. I recommend the DIY AVR cores that can be installed using the Arduino Boards Manager (https://github.com/sleemanj/optiboot).
If you can't or don't want to use Arduino I have some pre-compiled hex files for the Kernal switch and drive ROM switch along with fuse configurations and syntax examples for how to program them using avrdude. These can be found under the Applications folder in my GitHub repository.

# Programming the flash chip (ROM)

The flash chip needs to be programmed before soldering it. If you need to reprogram the flash later it must first be de-soldered and then re-soldered again after reprogramming.
You need to concatenate all your images into one file and fill up any empty space in flash with valid extra images to avoid bricking your host device if an incorrect image number is selected. If that would happen the EPROM can be reset by re-flashing the firmware.
In 27128 mode all images should be 16KB and in 27256 mode all the images need to be 32KB.

# Document revision history

1.0 Initial version
1.1 BOM Corrected
1.2 Updated BOM with 20MHz crystal, changed AVR core and added information about 1571 & 1581

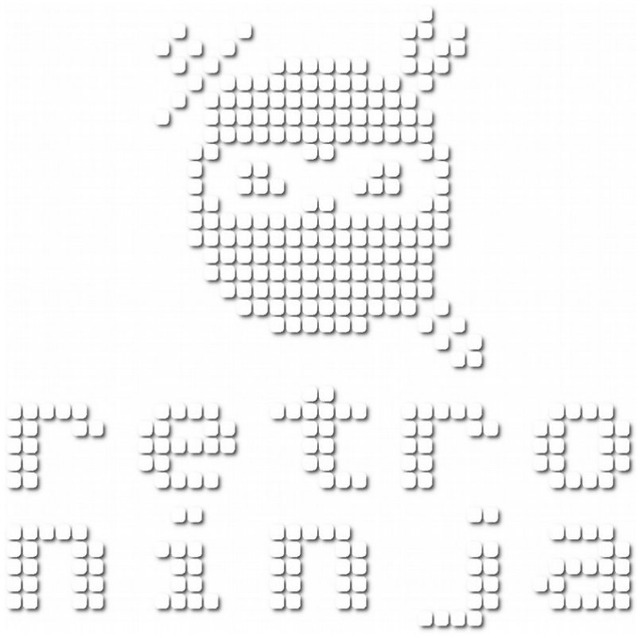
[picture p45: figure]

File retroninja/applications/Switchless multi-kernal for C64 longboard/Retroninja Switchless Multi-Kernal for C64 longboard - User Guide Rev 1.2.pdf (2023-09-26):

# Retroninja Switchless Multi-Kernal for C64 longboard

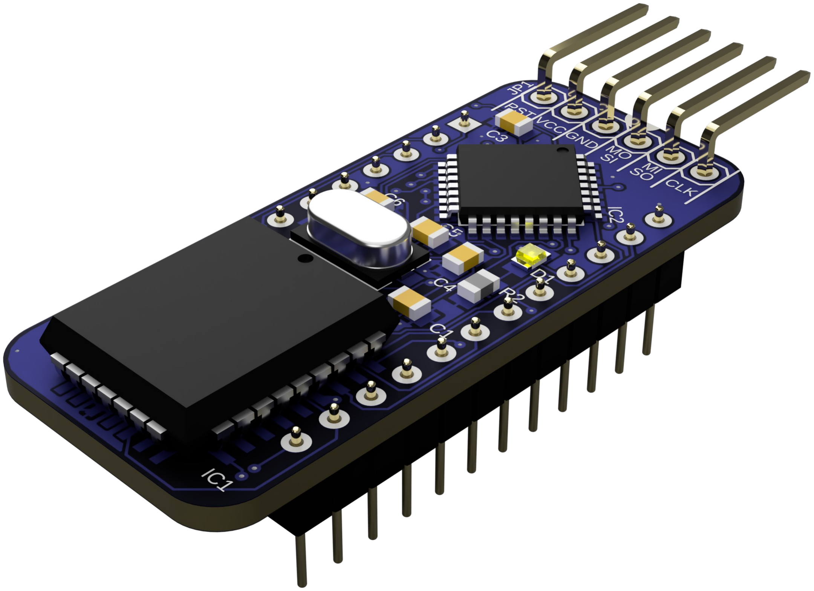
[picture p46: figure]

# User Guide

Retroninja Switchless Multi-Kernal for C64 longboard | User Guide Version 1.1

## Table of Contents

# Functional description

t power on, the MCU in the Kernal switch holds the reset line active while it reads address 0 from its internal EPROM to find out which Kernal it should select, sets the A13-A18 address pins on the flash chip accordingly and releases the reset line to make sure the computer is booted using the correct Kernal.
If at any time, restore is pressed and held for a few seconds the MCU will detect this and switch to Kernal 0 which is a menu Kernal. For this application I created a custom Mini-Kernal for the C64 that displays a list of Kernals to choose from.


When the user selects a Kernal image from the menu, the Mini-Kernal writes a predefined switching command to RAM along with a byte that indicates the selected image number. It does this over and over. Example of the command: RNROM64#1 where 1 is a byte with value 0x01 that tells the switch that we want to switch to kernal image 1.
The Kernal switch now captures the command from the data bus, writes the selected kernal number to the MCU EPROM for future use, then it switches the address pins A13-A18 accordingly. It then resets the computer using the new Kernal by pulling the reset line. The computer will continue to start up using this new Kernal until a new choice is made.
The flash is populated with the Mini-Kernal followed by up to 10*8 KB Kernals. It would in theory be possible to add up to 63 kernals if both the Mini-Kernal and the MCU firmware was modified in some way to accommodate that many Kernal images.
Here's an example layout that fills out an SST39SF010A:

If the same layout would be used with a larger flash chip it should be duplicated to fill out the flash.
This C64 Kernal switch only suits the C64 longboards which have a 24pin ROM and has basic in a separate ROM. All C64 motherboards are longboards except PCB 250469.
The C64 shortboard (PCB 250469) have 28-pin 27128 type Kernal ROMs and I have another Multi-ROM version that is compatible with those at: https://github.com/RetroNynjah/Switchless-Multi-ROM-for-27128-27256
Mini-Kernal | CBM Kernal | JiffyDOS US | JiffyDOS SE | JiffyDOS DK | JaffyDOS US | JaffyDOS SE | SpeedDOS | SpeedDOS | DolphinDOS | DolphinDOS | Mini-Kernal | Mini-Kernal | Mini-Kernal | Mini-Kernal | Mini-Kernal
8kB | 8kB | 8kB | 8kB | 8kB | 8kB | 8kB | 8kB | 8kB | 8kB | 8kB | 8kB | 8kB | 8kB | 8kB | 8kB

# Installing the Kernal switch

The switch will replace the kernal ROM chip U4.
U4 is not always socketed and if it isn't it must first be desoldered from the board and a 24 pin socket should be soldered to the board before the switch is installed. Pay attention to the direction of the notch on U4 that indicates the location of pin 1. The notch on the socket should face the same direction and so should pin 1 on the switch. Pin 1 on the switch is at the end that has six header pins. It is also indicated by a printed notch on the bottom side of the switch.
If any EPROM adapters are installed at U4 they need to be removed and the switch should be installed directly in the socket
The below pins on the switch must be connected to the right signals on the motherboard.
Switch pin | Computer signal | Example of locations
CLK | R/W | 6510 pin 38, 6526 pin 22
MISO | RESTORE | KBD connector pin 3
MOSI | RESET | 6510 pin 40, 6526 pin 34
The connections can be made on the chips using test clips but it's recommended to solder pin headers to vias on the motherboard and connect to the pin headers using Dupont wires or solder one end of Dupont cables directly to the vias for a permanent installation.
If you want to solder pin headers to the vias you can try inserting them from the top side without taking the board out. Try heating the pins with the soldering iron while pushing them into the via using pliers but to get the best possible connection of the pins they should be soldered from the bottom of the motherboard. The below pictures show examples of suitable vias for different motherboards.

PCB 250407

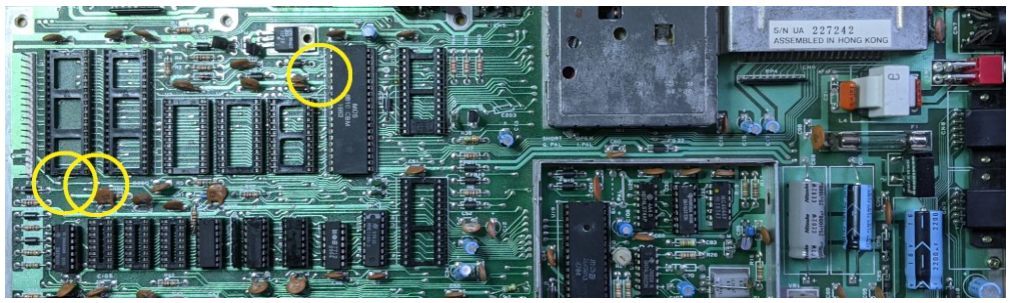
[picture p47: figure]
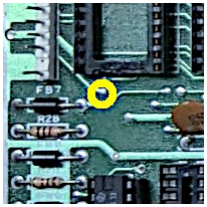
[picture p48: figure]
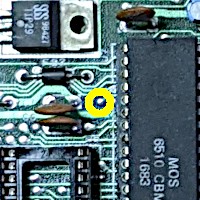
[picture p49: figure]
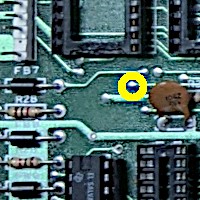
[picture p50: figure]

RESTORE | R/W | RESET

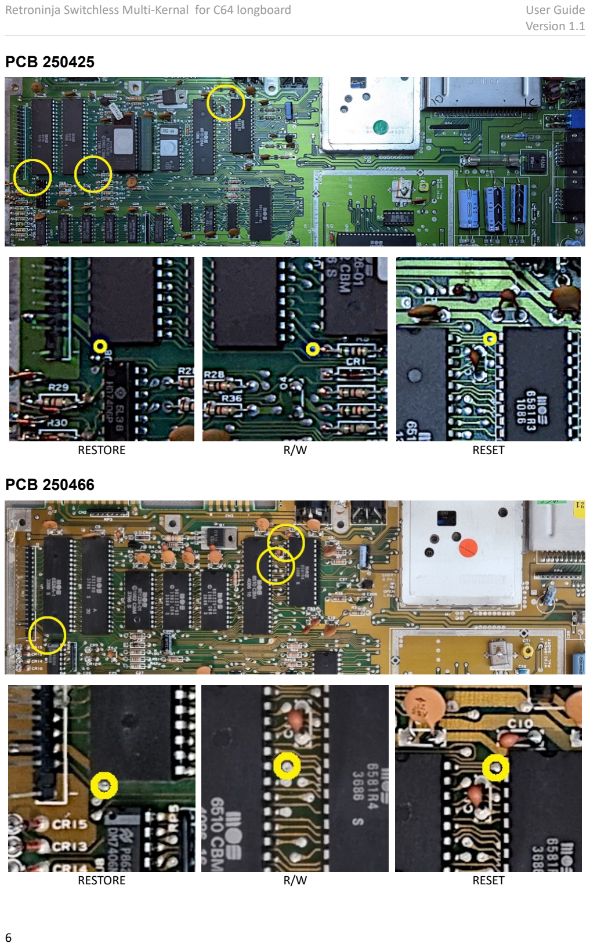
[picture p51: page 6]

PCB 250425

RESTORE | R/W | RESET

PCB 250466

RESTORE | R/W | RESET

# Using the Kernal switch

Hold the restore key for about three seconds until the kernal menu is activated. Once in menu you can use cursor up/down to move to the Kernal you want to switch to and press return. The switch resets the computer with the new Kernal and saves your choice for next power-on.

# Upgrading the firmware

The firmware in the microcontroller can be upgraded using the 6-pin ISP header. The source code is written for Arduino and programming the firmware can be done directly from the Arduino IDE using an ISP programmer.
If your device is using an Atmega328 it can be programmed as an Arduino UNO. The other variants require custom board definitions. I have used the MiniCore from MCUdude (https://github.com/MCUdude/MiniCore) with default board settings.
If you can't or don't want to use Arduino I have some precompiled hex files for the Kernal switch and drive ROM switch along with fuse configurations and syntax examples for how to program them using avrdude. These can be found under the Applications folder in the GitHub repository at: https://github.com/RetroNynjah/Switchless-Multi-ROM-for-2364

# Programming the flash chip (ROM)

The flash chip needs to be programmed before soldering it. If you need to reprogram the flash later it must first be desoldered and then resoldered again after reprogramming.
The flash chip should contain the Mini-Kernal image followed by all switchable kernal images in correct order. All images needs to have a size of exactly 8KB.

# Document revision history

1.0 Initial version
1.1 Cover page image corrected
1.2 Added Kernal ROM location/socket information

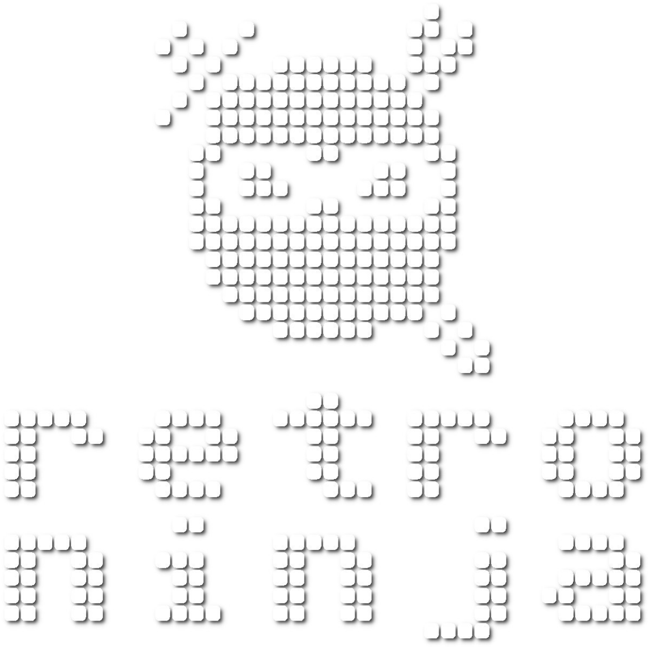
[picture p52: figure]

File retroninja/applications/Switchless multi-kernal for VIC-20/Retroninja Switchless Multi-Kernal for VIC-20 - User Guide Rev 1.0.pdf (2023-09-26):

# Retroninja Switchless Multi-Kernal for VIC-

20


# User Guide

Retroninja Switchless Multi-Kernal for VIC-20 | User Guide Version 1.0

## Table of Contents

# Functional description

At power on, the MCU in the Kernal switch holds the reset line active while it reads address 0 from its internal EPROM to find out which Kernal it should select, sets the A13-A18 address pins on the flash chip accordingly and releases the reset line to make sure the computer is booted using the correct Kernal.
If at any time, restore is pressed and held for a few seconds the MCU will detect this and switch to Kernal 0 which is a menu Kernal. For this application I created a custom Mini-Kernal for the VIC-20 that displays a list of Kernals to choose from.

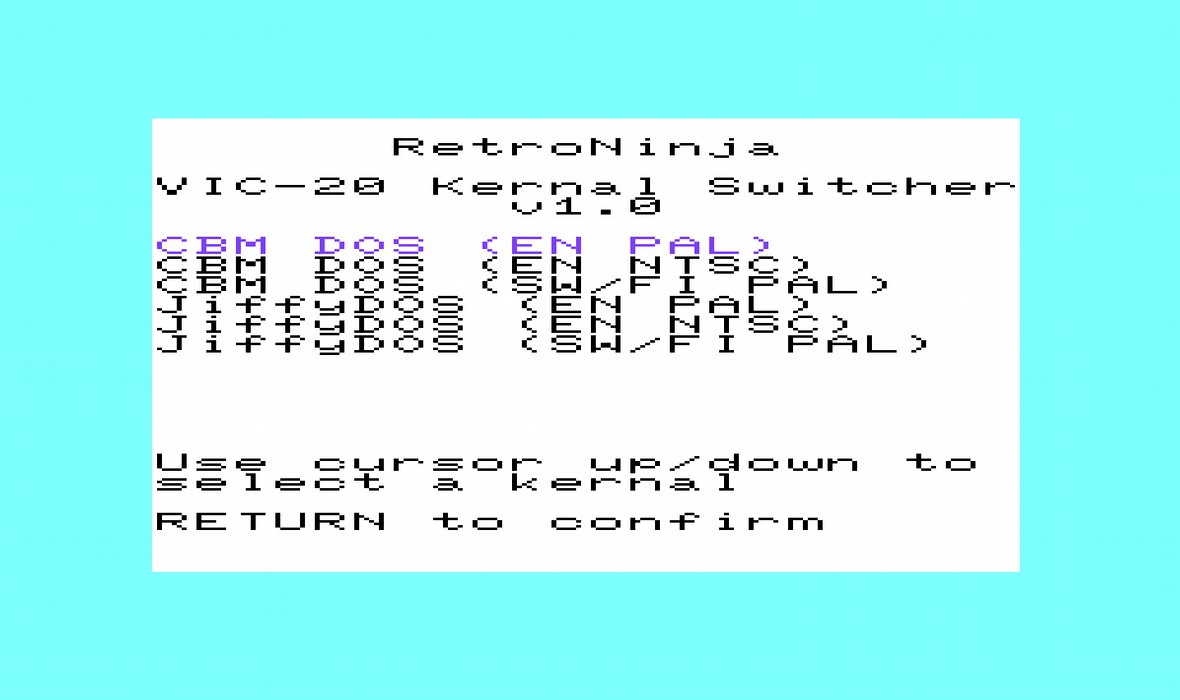
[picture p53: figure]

When the user selects a Kernal image from the menu, the Mini-Kernal writes a predefined switching command to RAM along with a byte that indicates the selected image number. It does this over and over. Example of the command: RNROM20#1 where 1 is a byte with value 0x01 that tells the switch that we want to switch to kernal image 1.
The Kernal switch now captures the command from the data bus, writes the selected kernal number to the MCU EPROM for future use, then it switches the ROM address pins A13-A18 accordingly. It then resets the computer using the new Kernal by pulling the reset line. The computer will continue to start up using this new Kernal until a new choice is made.
The flash is populated with the Mini-Kernal followed by up to 10*8 KB Kernals. It would in theory be possible to add up to 63 Kernals if both the Mini-Kernal and the MCU firmware was modified in some way to accommodate that many Kernal images.
Here's an example layout that fills out an SST39SF010A:

If the same layout would be used with a larger flash chip it should be duplicated to fill out the flash.

Mini-Kernal | CBM EN PAL | CBM EN NTSC | CBM SE PAL | Jiffy EN PAL | Jiffy EN NTSC | Jiffy SE PAL | Mini-Kernal | Mini-Kernal | Mini-Kernal | Mini-Kernal | Mini-Kernal | Mini-Kernal | Mini-Kernal | Mini-Kernal | Mini-Kernal
8kB | 8kB | 8kB | 8kB | 8kB | 8kB | 8kB | 8kB | 8kB | 8kB | 8kB | 8kB | 8kB | 8kB | 8kB | 8kB

# Installing the Kernal switch

The switch will replace the kernal ROM chip (UD6 on Rev E boards, UE12 on boards 324003/250403).
The kernal ROM chip is not always socketed and if it isn't, it must first be desoldered from the board and a 24 pin socket should be soldered to the board before the switch is installed. Pay attention to the direction of the notch on the chip that indicates the location of pin 1. The notch on the socket should face the same direction and so should pin 1 on the switch. Pin 1 on the switch is at the end that has six header pins. It is also indicated by a printed notch on the bottom side of the switch.
If any EPROM adapters are installed at positionUD6/UE12 they need to be removed and the switch should be installed directly in the socket
The below pins on the switch must be connected to the right signals on the motherboard.
Switch pin | Computer signal | Example of locations
CLK | R/W (CRW) | 6502 pin 34, 6522 pin 22
MISO | RESTORE | KBD connector pin 3
MOSI | RESET | 6502 pin 40, 6526 pin 34
The connections can be made on the chips using test clips but it's recommended to solder pin headers to vias on the motherboard where available and connect the pin headers using Dupont wires or solder a cable to the motherboard for a permanent installation. If you want to solder pin headers to the vias you can try inserting them from the top side without taking the board out. Try heating the pins with the soldering iron while pushing them into the via using pliers but to get the best possible connection of the pins they should be soldered from the bottom of the motherboard.
The below pictures show examples of suitable vias for different motherboards.

PCB 324003

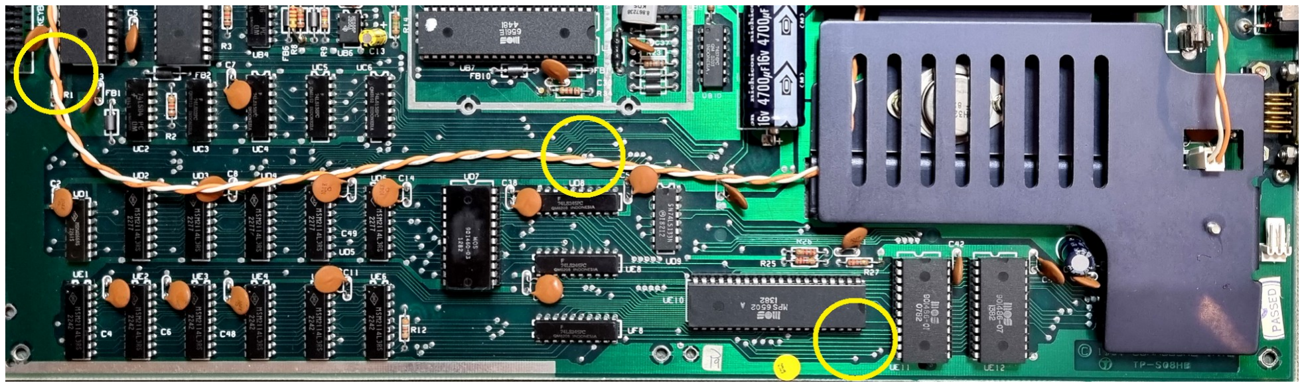
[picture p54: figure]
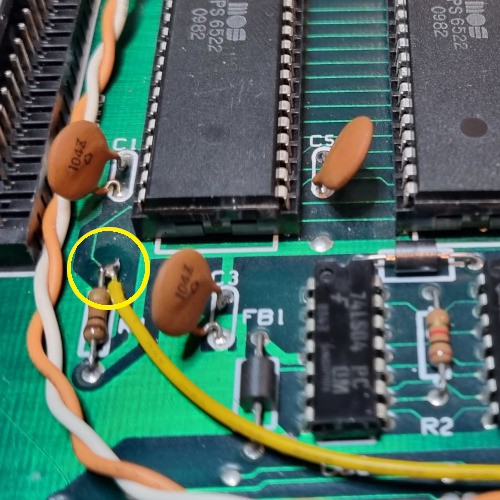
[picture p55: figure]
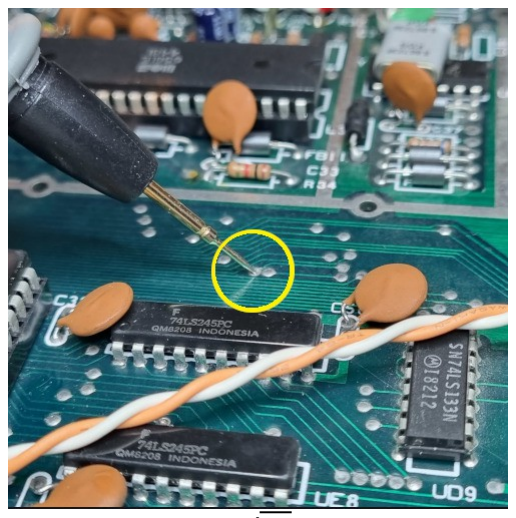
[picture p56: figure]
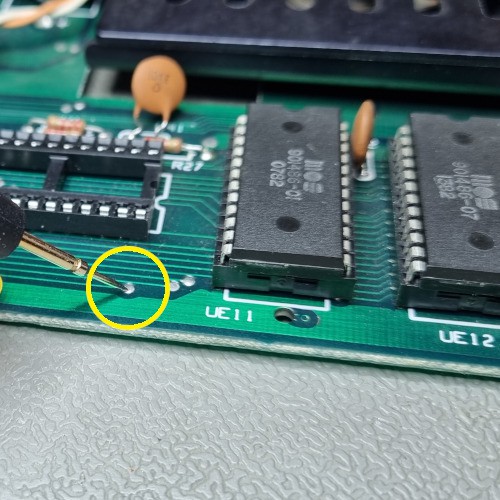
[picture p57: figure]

RESTORE | R/W | RESET
The restore signal doesn't go through any VIAs on this PCB. Solder the restore wire to the upper end of resistor R1 or solder it to the bottom of the PCB. Pin 40 of VIA UAB3 is the point closest to the ROM socket. Make sure none of the header pins on the switch touches the heat sink.

PCB 250403
TBD

Rev E
TBD

# Using the Kernal switch

Hold the restore key for about three seconds until the kernal menu is activated. Once in menu you can use cursor up/down to move to the Kernal you want to switch to and press return. The switch resets the computer with the new Kernal and saves your choice for next power-on.

# Upgrading the firmware

The firmware in the microcontroller can be upgraded using the 6-pin ISP header. The source code is written for Arduino and programming the firmware can be done directly from the Arduino IDE using an ISP programmer.
If your device is using an Atmega328 it can be programmed as an Arduino UNO. The other variants require custom board definitions. I have used the MiniCore from MCUdude (https://github.com/MCUdude/MiniCore) with default board settings.

If you can't or don't want to use Arduino I have some precompiled hex files for the Kernal switch and drive ROM switch along with fuse configurations and syntax examples for how to program them using avrdude. These can be found under the Applications folder in the GitHub repository at: https://github.com/RetroNynjah/Switchless-Multi-ROM-for-2364

# Programming the flash chip (ROM)

The flash chip needs to be programmed before soldering it. If you need to reprogram the flash later it must first be desoldered and then resoldered again after reprogramming.
The flash chip should contain the Mini-Kernal image followed by all switchable kernal images in correct order. All images needs to have a size of exactly 8KB.

# Document revision history

1.0 Initial version

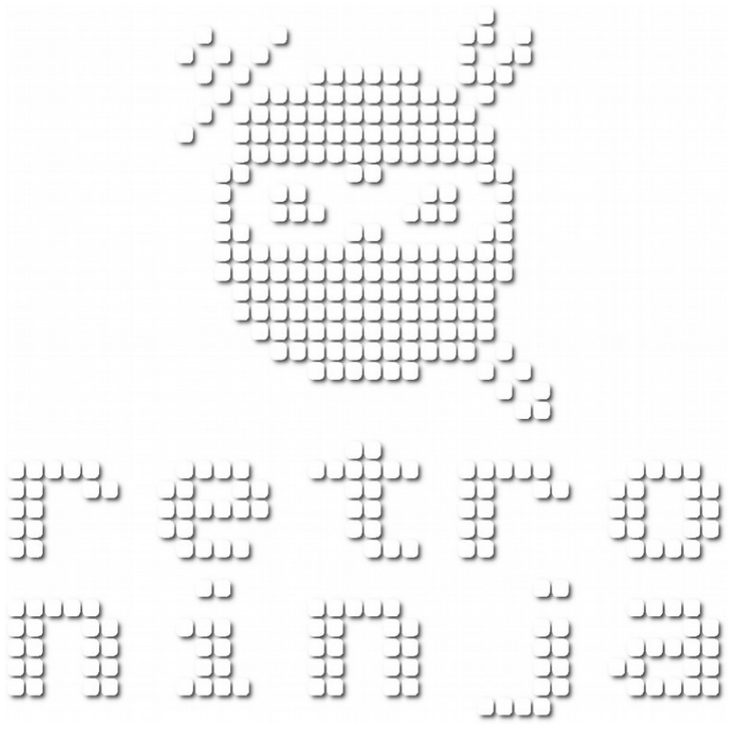
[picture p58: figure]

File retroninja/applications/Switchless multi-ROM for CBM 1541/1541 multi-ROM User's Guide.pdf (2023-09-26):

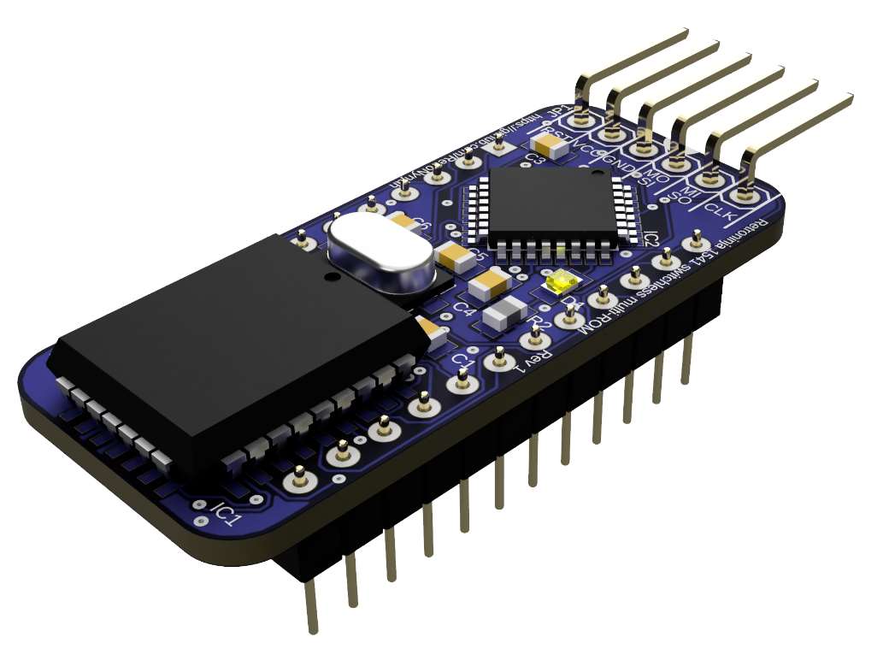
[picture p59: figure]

P a g e 1 | 6

# Switchless Multi-ROM for CBM 1541 User’s Guide

This microcontroller-based switchless ROM-switcher for the 1541 disk drive lets you switch drive ROM between stock CBM DOS and JiffyDOS using simple basic commands.
It’s possible to use other DOS versions too as long as only the upper half of the ROM set ($E000) needs switching as with JiffyDOS.

## Usage

The switcher is listening to the data bus for a predefined word and a number. The easiest way to send the word to the drive is to issue a load command to the drive from basic with the word as filename.
The default magic word is #@RNROM where # is the number of the ROM image you want to switch to.
LOAD “1@RNROM”,8 switches drive 8 to DOS image 1 and LOAD “2@RNROM”,8 switches to image 2 and so on. The default valid range of numbers is 1-8. It is possible to modify the code to allow bigger numbers but the amount of available ROMs on the market is not that large.
The drive will respond with a file not found error but the programmer will pick up the command, blink the multi-ROM LED to indicate which image was selected, switch the ROM by setting the high address pins accordingly and reset the drive using the newly selected ROM.
The selected ROM will be remembered and used at power-on.

Retroninja 1541 switchless multi-ROM | User’s Guide version 1.1
P a g e 2 | 6

## Theory of operation

At power on, the microcontroller in the ROM switcher reads address 0 from its internal EPROM to find out which ROM it should select, sets the address A13-A16 on the flash chip and resets the drive to make sure it is booted with the correct image. This can be noticed when the drive is powered on and the drive initializes and stops spinning and then spins up again briefly during the switch reset. It then starts listening for a switch command.
Even at a clock speed of 16 MHz, reading and analyzing a 1MHz data bus can be a challenge so the data on the 1541 data bus is buffered in the switcher by a 74AHCT273 flip-flop that is clocked by the Write signal on the 6502 MPU in the 1541. By clocking the data with the R/W signal we filter out irrelevant bus traffic and the flip-flop holds the data until the next write cycle. This gives the microcontroller enough time to read the data from the flip-flop.
The microcontroller listens for a predefined sequence of bytes in reverse order (MORNR@) and once the sequence is found, it treats the following numeric character as the target ROM image number. The reverse order of the characters on the bus is why the image number must be specified at the beginning of the command.
The microcontroller sets address pins A13-A16 on the flash chip according to image selection and it stores the ROM number at address 0 of its internal EPROM for use at next power-on. It then resets the drive by toggling the IEC reset line.

P a g e 3 | 6

## Building the circuit

The switcher is small and a bit difficult to solder but it can be hand soldered. The reason for the small size is space constraints in some drives. This design started off as a Multi-ROM for the 1541-II which has even less space around the ROM. You can find that version among my other repositories on GitHub.
The Flash chip is the trickiest part to solder and I recommended reflow soldering the top side using stencil and solder paste. Then solder the bottom side by hand and finally solder the pin headers.

### Parts

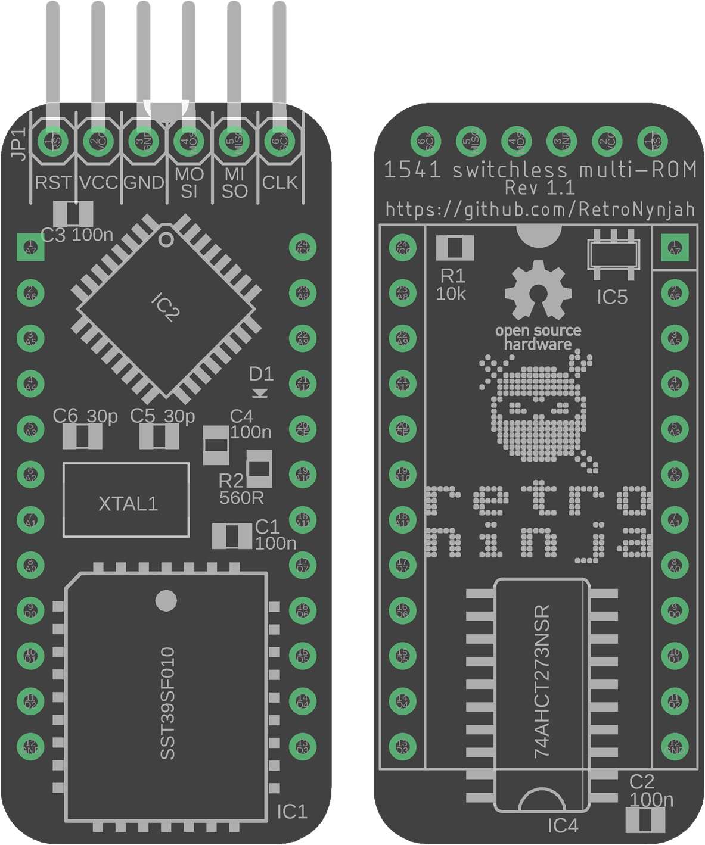
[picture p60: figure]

The switcher is designed for the SST39SF010A flash chip but the bigger SST39SF020/SST39SF040 could be used too if no SST39SF010A is available. Remember to duplicate the flash contents to fill all of flash to prevent floating pins from switching to empty flash areas.
The microcontroller does not have to be an ATmega328P but it is much easier if you want to program it from the Arduino IDE as it will be seen as an Arduino UNO.
It could be possible to replace it with other compatible MCUs such as variations of ATmega8/48/88/168/328 if you find or create the right Arduino board definitions for compiling the firmware. The chip needs to be pin-compatible with the ATmega328P TQFP-32 and capable of running at 16MHz so the V and PB variations will not work. I have used the ATmega88A.
The flip-flop needs to be a 74AHCT273. LS/HCT/AHC or any other variant will most likely not work.

P a g e 4 | 6

The 74AHCT1G04 single gate inverter is needed for inverting the active low write signal from the 6502 to the active high clock input of the flip-flop.
The crystal should be a 16MHz crystal but 20 MHz might work too if you recompile the sketch and burn the fuses accordingly. Not tested.
The LED on the board is optional but flashes a number of times indicating the number of the selected ROM when switching. It is only there for debugging reasons.
The pin headers that goes into the ROM socket should have round machined pins or be of that long flat type that is used for the pass-through pin headers on Arduino shields.
Square pin headers destroy the ROM socket in the drive.

### Programming the microcontroller

The recommended microcontroller for this board is an ATmega328P. The code for the controller was created using the Arduino environment and the device can be programmed in circuit from a sketch in the Arduino IDE using an ISP programmer. The board type can be set to Arduino UNO.
It can be programmed using AVRDUDE and the pre-compiled HEX file or using the popular TL866II programmer. The pin-out of the programming pins on the PCB matches the pin-out of the TL866II ICSP connector so a straight 6-pin cable can be used.
If you use an ATmega328P, the fuse settings should be the same as for an Arduino UNO. lfuse=0xFF, hfuse=0xDE, efuse=0xFD
How to use an Arduino as ISP or how to use an ISP programmer such as a USBASP will not covered by this document.

### Programming the flash chip

Due to space constraints, there are no on-board programming headers for the flash chip so the flash chip must be programmed in a flash/EPROM programmer before soldering it to the board or desoldered for reprogramming.
It could also be possible to make a programming adapter to put on top of the flash chip to program it while it’s still soldered to the board but this is not tested.
The high ROM chip in the 1541 is only 64 kbit (8 kilobyte) while the flash chip is 1 Mbit (128 kilobyte). It’s highly recommended to fill the entire flash chip with working DOS images to prevent bricking of the drive by selecting a non-existing image. The switcher will not work without a working ROM in the drive that can receive the serial data and put it on the data bus.
If you just use two ROM images, fill the flash with the same two images over and over for safety.

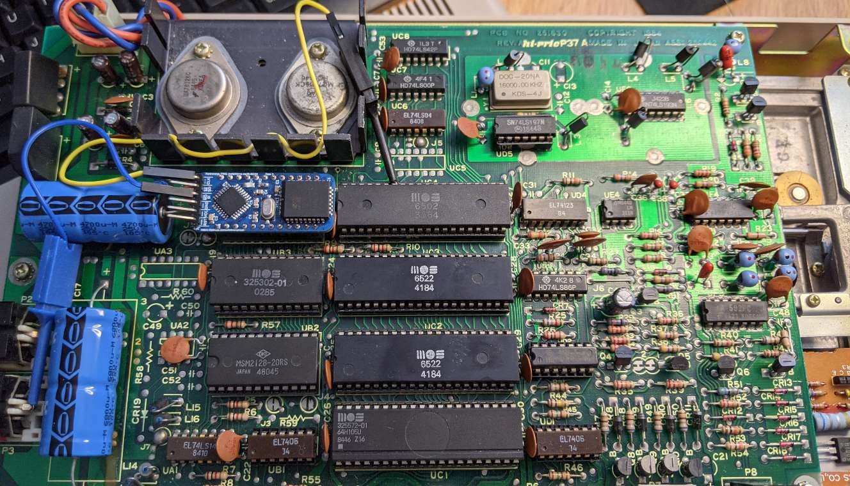
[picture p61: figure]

P a g e 5 | 6

## Installation

The circuit can be installed in the drive without soldering by using DuPont cables with test clips that attaches to the R/W pin on the 6502 MPU and to the reset pin on the back of any of the IEC connectors. However, it is recommended to solder the cables to the pins on the bottom of the drive PCB. That makes for a much more robust and transportable solution.
An even more stable solution is to solder the cables to the edge of the switcher PCB instead of using a pin header but that could make it harder to upgrade the firmware in the future.
The edge of the Multi-ROM PCB with the six ISP pins should face the notched end of the ROM socket (Pin 1). You may have to bend a ceramic capacitor out of the way a little before you can insert it.

The clock signal (CLK on the Multi-ROM) connects to the R/W pin (pin 34) on the 6502 MPU.
MOSI on the Multi-ROM connects to IEC reset. That’s the center pin on the back of the IEC connectors. The Multi-ROM works without a connection to IEC reset but a manual drive reset would then be needed after switching ROM.
The sketch and a pre-compiled firmware for the Multi-ROM can be found at https://github.com/RetroNynjah/1541-Switchless-Multi-ROM

## Troubleshooting

If the device becomes bricked due to an incorrect DOS image, program the ATmega with a sketch that sets byte 0 to 0x00 or 0xFF in the internal EPROM. Then upload the original Multi-ROM sketch again and you should be back on track.
Switching may not work if you are using a fast loader such as Action Replay in your computer. Try switching the ROM without the fast loader. Switching ROM using JiffyDOS in the C64 is working fine though.

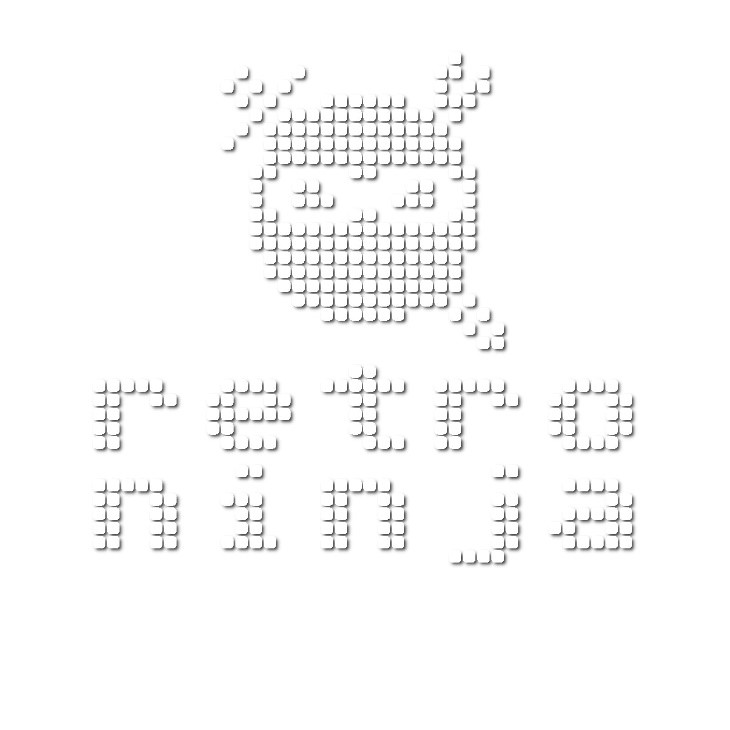
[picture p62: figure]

P a g e 6 | 6

## Possible other uses

A second switcher for the low ROM in the 1541 could be used simultaneously if you need to switch both ROMs simultaneously or maybe use a slave 2364 ROM adapter for the low ROM and connect the unused address A13-A16 to the same address pins on the Switchless Multi-ROM using bodge wire or similar.
The switcher could possibly be used for other 2364 ROM switching applications if you can find the right clock signal and strings to listen for.
The switcher could work in other 1541 compatible drives that are using 2364 ROMs but none have been tested so far. The 1541-II switcher emulates a 16kB 27128 EPROM has been tested in a number of compatible drives.

## Change history

This is the change history for the user’s guide.
For changes to the schematics, PCB or firmware, please refer to the GitHub repository at https://github.com/RetroNynjah/1541-Switchless-Multi-ROM
Date | Version | Description
2021-05-15 | 1 | Initial version
2021-05-22 | 1.1 | Alternative ATmega MCUs

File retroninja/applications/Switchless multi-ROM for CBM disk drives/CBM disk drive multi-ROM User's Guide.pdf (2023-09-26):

# Switchless Multi-ROM for CBM 1541-II, 1571 & 1581 User’s Guide

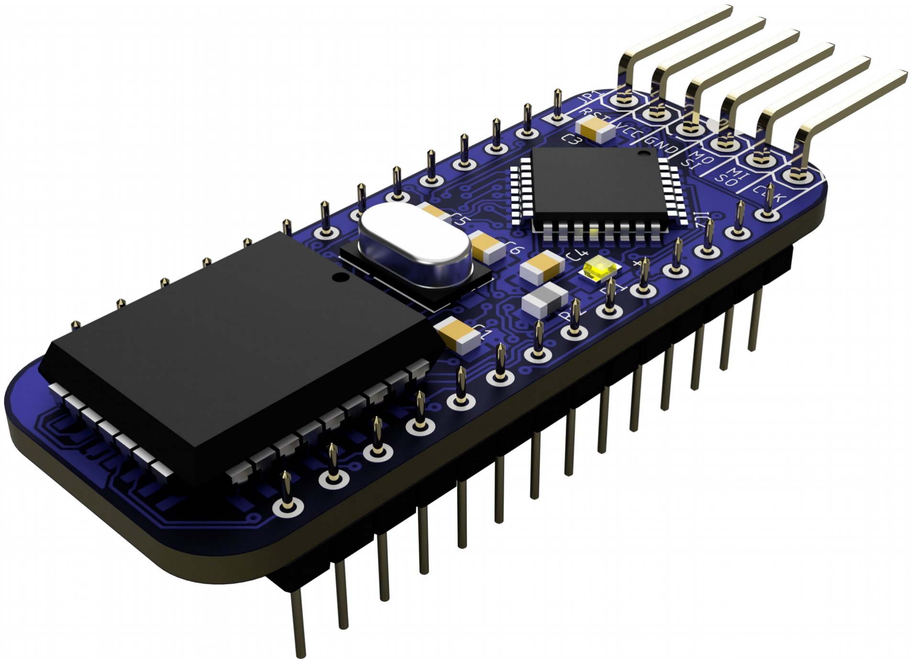
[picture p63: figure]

This microcontroller-based switchless ROM-switcher for the 1541-II, 1571 and 1581 disk drives lets you switch drive ROM between stock CBM DOS and JiffyDOS or other DOS version using simple basic commands. It's based on the switchless multi-ROM for 27128/27256 ROMs. Read more about it at: https://github.com/RetroNynjah/Switchless-Multi-ROM-for-27128-27256

## Usage

The switcher is listening to the data bus for a predefined word and a number. The easiest way to send the word to the drive is to issue a load command to the drive from basic with the word as filename or to utilize a JiffyDOS wedge command.
The default magic word is #@RNROM where # is the number of the ROM image you want to switch to.
LOAD “1@RNROM”,8 switches drive 8 to DOS image 1 and LOAD “2@RNROM”,8 switches to image 2 and so on. The default valid range of numbers is 1-4.
The drive will respond with a file not found error but the programmer will pick up the command, blink the multi-ROM LED to indicate which image was selected, switch the ROM by setting the high address pins accordingly and reset the drive using the newly selected ROM.
The selected ROM will be remembered and used at power-on.
If you have a JiffyDOS kernal in your computer you can select the right device using CTRL+D and issue the following commands instead: @1@RNROM or @2@RNROM
P a g e 1 | 5

Retroninja 1541-II switchless multi-ROM | User’s Guide version 1.2

## Theory of operation

At power on, the microcontroller in the ROM switcher reads address 0 from its internal EPROM to find out which ROM it should select, sets the address A14-A16 or A15-A16 on the flash chip depending on ROM size and then resets the drive to make sure it’s booted with the correct image. This can be noticed when the drive is powered on and the drive initializes and stops spinning and then spins up again briefly during the switch reset.
It then starts listening for a switch command.
Even at a clock speed of 20 MHz, reading and analyzing a 1-2MHz data bus can be a challenge so the data on the 1541-II data bus is buffered in the switch by a 74AHCT273 flip-flop that is clocked by the Write signal on the 6502 MPU in the disk drive. By clocking the data with the R/W signal we filter out irrelevant bus traffic and the flip-flop holds the data until the next write cycle. This gives the microcontroller enough time to read the data from the flip-flop.
The microcontroller listens for a predefined sequence of bytes in reverse order (MORNR@) and once the sequence is found, it treats the following numeric character as the target ROM image number. The reverse order of the characters on the bus is why the image number must be specified at the beginning of the command.
The microcontroller sets address pins A14-A16 or A15-A16 on the flash chip according to image selection and it stores the ROM number at address 0 of its internal EPROM for use at next power-on. It then resets the drive by toggling the IEC reset line.

## Building the circuit

The switcher is small and a bit difficult to solder but it can be hand soldered. The reason for the small size is space constraints in many disk drives such as the 1541-II, 1571 and 1581.
The Flash chip is the trickiest part to solder and I recommend reflow soldering of the top side using stencil and solder paste. Then solder the bottom side by hand and finally solder the pin headers.

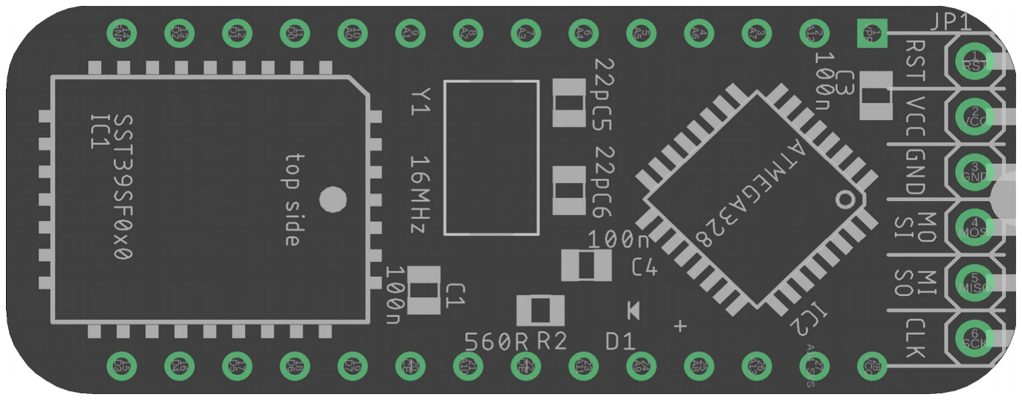
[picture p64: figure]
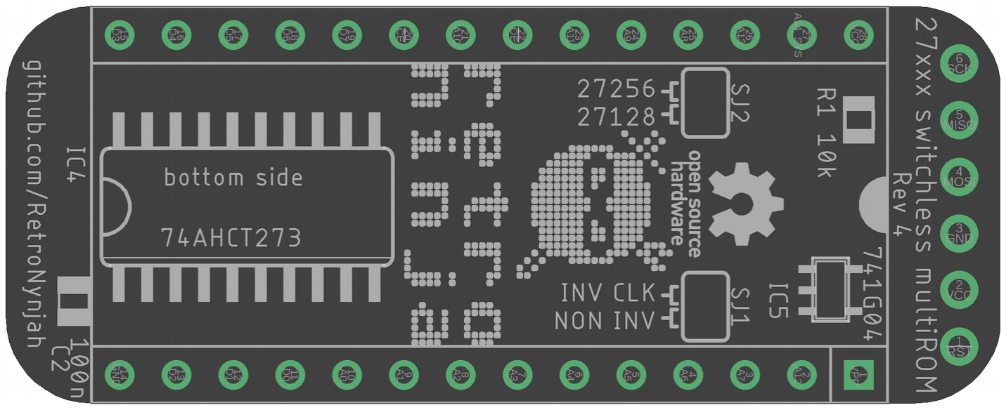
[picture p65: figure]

P a g e 2 | 5

### Parts

The switcher is designed for the SST39SF010A flash chip but the bigger SST39SF020/SST39SF040 could be used too if no SST39SF010A is available. Remember to duplicate the flash contents to fill all of flash to prevent floating pins from switching to empty flash areas.
The microcontroller can be pretty much any variation of ATmega48/88/168/328 as long as it can run at 20MHz.
The flip-flop needs to be a 74AHCT273. LS/HCT/AHC or any other variant will most likely not work. The 74AHCT1G04 single gate inverter is needed for inverting the active low write signal from the 6502 to the active high clock input of the flip-flop.
The recommended crystal is a 20 MHz crystal (for 1571/1581) but a 16MHz works for 1541-II.
The LED on the board is optional but flashes a number of times indicating the number of the selected ROM when switching. It is only there for debugging reasons.
The pin headers that goes into the ROM socket should have round machined pins or be of that long flat stackable type that is used for the pass-through pin headers on Arduino shields. The flat ones are recommended as the profile gets even lower with those headers. There is almost no headroom in the 1541-II, 1571 and 1581 external drives. The internal drives in the 128D models have more room. Square pin headers destroy the ROM socket in the drive so don't use those.

### Programming the microcontroller

The code for the controller was created using the Arduino environment and the device can be programmed in circuit from a sketch in the Arduino IDE using an ISP programmer.
I recommend the DIY AVR cores that can be installed using the Arduino Boards Manager (https://github.com/sleemanj/optiboot).
If you can't or don't want to use Arduino there are some precompiled hex files for the Kernal switch and along with fuse configurations and syntax examples for how to program it using avrdude. These can be found under the Applications folder in my GitHub repository at https://github.com/RetroNynjah/Switchless-Multi-ROM-for-27128-27256
How to use an Arduino as ISP or how to use an ISP programmer such as a USBASP will not covered by this document.
The firmware can also be programmed using AVRDUDE and the pre-compiled HEX file or using the popular TL866II programmer. The pin-out of the programming pins on the PCB matches the pin-out of the TL866II ICSP connector so a straight 6-pin cable can be used.

### Programming the flash chip

Due to space constraints, there are no on-board programming headers for the flash chip so the flash chip must be programmed in a flash/EPROM programmer before soldering it to the board or desoldered for reprogramming.
It could also be possible to make a programming adapter to put on top of the flash chip to program it while it’s still soldered to the board but this is not tested.
The ROM chip in the 1541-II is only 128 kbit (16 kilobyte) and the 1571/1581 drive ROMs are 256kbit (32 kilobyte) while the flash chip is 1 Mbit (128 kilobyte). It’s highly recommended to fill the entire flash chip with working DOS images to prevent bricking of the drive by selecting a non-existing image. The switcher will not work without a working ROM in the drive that can receive the serial data and
P a g e 3 | 5

put it on the data bus.
If you just use two ROM images, fill the flash with the same two images over and over for safety.

## Installation

The circuit can be installed in the drive without soldering by using DuPont cables with test clips that attaches to the R/W pin on the 6502 MPU and to the reset pin on the back of any of the IEC connectors. However, it is recommended to solder the cables to the pins on the bottom of the drive PCB. That makes for a much more robust and transportable solution.
An even more stable solution is to solder the cables to the edge of the switcher PCB instead of using a pin header but that could make it harder to upgrade the firmware in the future.
The edge of the Multi-ROM PCB with the six ISP pins should face the notched end of the ROM socket (Pin 1).

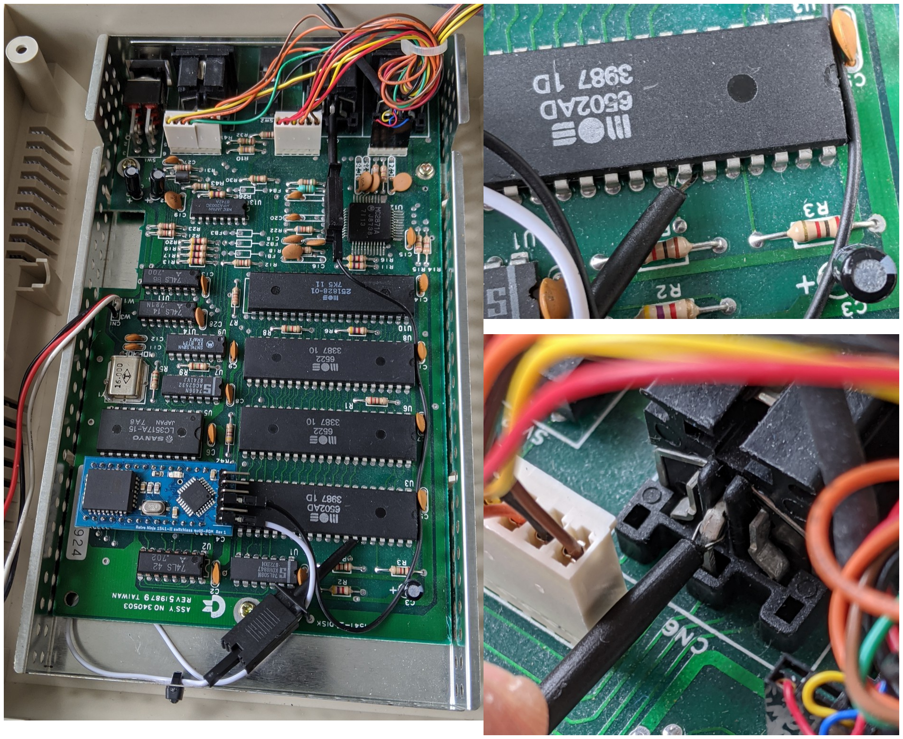
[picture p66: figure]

The clock signal (CLK on the Multi-ROM) connects to the R/W pin (pin 34) on the 6502 MPU.
MOSI on the Multi-ROM connects to IEC reset. That’s the center pin on the back of the IEC connectors. The Multi-ROM works without a connection to IEC reset but a manual drive reset would then be needed after switching ROM.
The sketch and a pre-compiled firmware for the Multi-ROM can be found in the Applications directory in the repository at:
https://github.com/RetroNynjah/Switchless-Multi-ROM-for-27128-27256
P a g e 4 | 5

## Troubleshooting

If the device becomes bricked due to an incorrect DOS image, program the ATmega with a sketch that sets byte 0 to 0x00 or 0xFF in the internal EPROM. Then upload the original Multi-ROM sketch again and you should be back on track.
You can also set byte 0 of the EEPROM to 0x00 using AVRDUDE or using the Minipro software. Switching will not work if you are some fast loaders such as Action Replay in your computer. Try switching the ROM without the fast loader. Switching ROM using JiffyDOS in the C64 is working fine though.
The switcher work in other CBM compatible drives that are using 27128 or 27256 ROMs. The Enhancer 2000 has been tested and works but unfortunately there's just not space enough in the OC-118 drive.

## Change history

This is the change history for the user’s guide.
For changes to the schematics, PCB or firmware, please refer to the GitHub repository at https://github.com/RetroNynjah/Switchless-Multi-ROM-for-27128-27256
Date | Version | Description
2021-05-15 | 1 | Initial version
2021-05-22 | 1.1 | Alternative ATmega MCUs
2023-01-10 | 1.2 | Major update. Now supports 1571/1581. Updated recommendations for crystals and microcontrollers

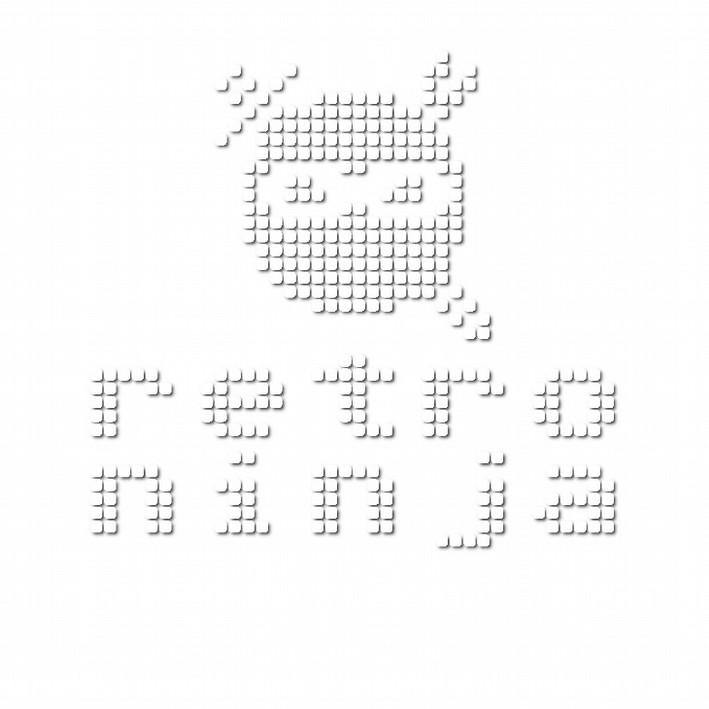
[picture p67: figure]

P a g e 5 | 5

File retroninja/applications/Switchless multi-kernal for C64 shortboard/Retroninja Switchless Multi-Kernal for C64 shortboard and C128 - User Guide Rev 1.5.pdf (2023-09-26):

# Retroninja Switchless Multi-Kernal for C64 shortboard and C128


# User Guide

Retroninja Switchless Multi-Kernal for C64 shortboard and C128

User Guide
Version 1.5

## Table of Contents

# Functional description

At power on, the MCU in the Kernal switch holds the reset line active while it reads address 0 from its internal EPROM to find out which Kernal it should select, sets the A14-A18 address pins on the flash chip accordingly and releases the reset line to make sure the computer is booted using the correct Kernal.
If at any time, restore is pressed and held for a few seconds the MCU will detect this and switch to Kernal 0 which is a menu Kernal. For this application I created custom Mini-Kernals for the C64 and the C128 that displays a list of Kernals to choose from.


When the user selects a Kernal image from the menu, the Mini-Kernal writes a predefined switching command to RAM along with a byte that indicates the selected image number. It does this over and over. Example of the command: RNROM64#1 where 1 is a byte with value 0x01 that tells the switch that we want to switch to kernal image 1.
The Kernal switch now captures the command from the data bus, writes the selected kernal number to the MCU EPROM for future use, then it switches the address pins A14-A18 accordingly. It then resets the computer using the new Kernal by pulling the reset line. The computer will continue to start up using this new Kernal until a new choice is made.
The flash is populated with the Mini-Kernal followed by up to 10*16 KB Kernals. It would in theory be possible to add up to 31 Kernals if both the Mini-Kernal and the MCU firmware was modified in some way to accommodate that many Kernal images.
Here's an example for a C64 layout that fills out an SST39SF010A:

Example for C128 with an SST39SF010A:

Example for C128DCR with an SST39SF010A:

As both C64 mode and C128 mode Kernals are in the same ROM a larger flash chip may be needed to accommodate all Kernals. If you have more C64 Kernals than C128 Kernals you still need to fill the C128 slots with working Kernals such as a stock CBM kernal or you will never be able to start the C128 into C64 mode either.

Basic | Mini-Kernal | Basic | CBM Kernal | Basic | JiffyDOS US | Basic | JiffyDOS SE | Basic | JiffyDOS DK | Basic | JaffyDOS | Basic | DolphinDOS | Basic | SpeedDOS
8kB | 8kB | 8kB | 8kB | 8kB | 8kB | 8kB | 8kB | 8kB | 8kB | 8kB | 8kB | 8kB | 8kB | 8kB | 8kB
16kB | | 16kB | | 16kB | | 16kB | | 16kB | | 16kB | | 16kB | | 16kB
Mini-Kernal | CBM Kernal | JiffyDOS US | JiffyDOS SE | JiffyDOS DK | Mini-Kernal | Mini-Kernal | Mini-Kernal
16kB | 16kB | 16kB | 16kB | 16kB | 16kB | 16kB | 16kB
C64 Basic | 64 Mini | 128 Mini | C64 Basic | 64 CBM krnl | 128 CBM krnl | C64 Basic | 64 Jiffy US | 128 Jiffy US | C64 Basic | 64 Jiffy SE | 128 Jiffy SE
8kB | 8kB | | 8kB | 8kB | | 8kB | 8kB | | 8kB | 8kB
16kB | | 16kB | 16kB | | 16kB | 16kB | | 16kB | 16kB | | 16kB

The C64 version of this Kernal switch only suits the C64 shortboards (PCB 250469) and the C64 part of the C128.
The C128DCR doesn't have a separate ROM for the C64 part and doesn't need an separate switch for C64 mode but it needs a specially combined DCR version of this switch.
C64 longboards have 24-pin 2364 type Kernal ROMs and I have another Multi-ROM version that is compatible with those at:
https://github.com/RetroNynjah/Switchless-Multi-ROM-for-2364

# Installing the Kernal switch

The below pins on the switch must be connected to the right signals on the C64 motherboard.
Switch pin | Computer signal | Example of locations
CLK | R/W | 8500 pin 38, 6526 pin 22
MISO | RESTORE | KBD connector pin 3
MOSI | RESET | 8500 pin 40, 6526 pin 34

The signals can be found at the below places on the C128 motherboard.
Switch pin | Computer signal | Example of locations
CLK | R/W | 8502 pin 39, 8563 pin 9, 6526 pin 22
MISO | RESTORE | KBD connector pin 3, U16 pin 9
MOSI | RESET | 8502 pin 40, 6526 pin 34

The connections can be made on the chips using test clips but it's recommended to solder pin headers to vias on the motherboard and connect to the pin headers using Dupont wires or solder one end of Dupont cables directly to the vias for a permanent installation.
If you want to solder pin headers to the vias you can try inserting them from the top side without taking the board out. Try heating the pins with the soldering iron while pushing them into the via using pliers but to get the best possible connection of the pins they should be soldered from the bottom of the motherboard. The following pages show where the switch should be installed and shows examples of suitable vias for different motherboards.

C64 PCB 250469
The switch will replace Kernal ROM chip named U4 on this board. U4 is normally not socketed and needs to be desoldered from the board and replaced with a socket before the switch is installed.
Pay attention to the notch on the ROM chip U4 indicating pin 1. The socket should have it's notch facing the same direction and the switch should also be installed with pin 1 facing the same direction.
Pin 1 on the switch is at the end that has six header pins. It is also indicated by a printed notch on the bottom side of the board.

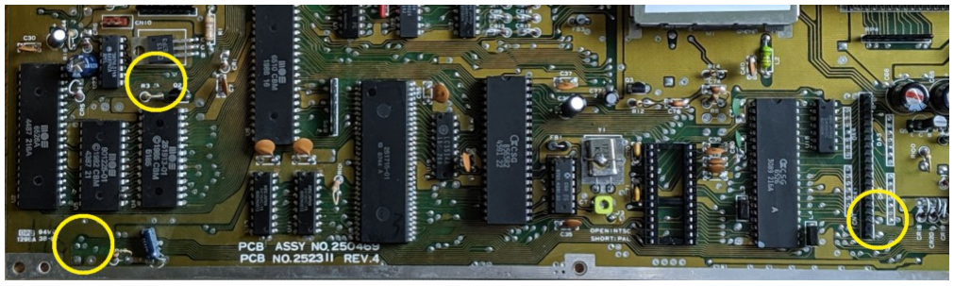
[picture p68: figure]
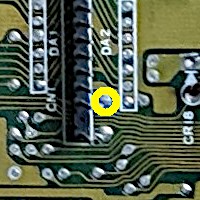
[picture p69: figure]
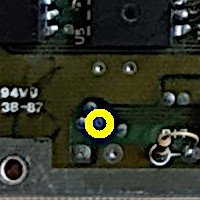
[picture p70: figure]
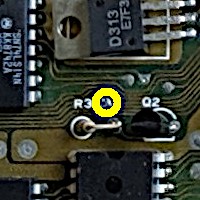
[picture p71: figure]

RESTORE | R/W | RESET

C128/C128D
This board requires two switches. The switch for C128 will replace the C128 Kernal ROM named U35 and the C64 mode switch replaces the C64 Kernal ROM U32.
Pay attention to the notch on the socket that indicates pin 1. Pin 1 on the switch is at the end that has six header pins. It is also indicated by a printed notch on the bottom side of the board.
The R/W signal in the point marked below can be a bit low on some C128s such as the Rev 7 boards and on the C128 Neo. If you can't get the switch to switch kernal after selecting an image (hangs on selection), try connecting to the R/W signal on the 8563 or 8502 instead to see if that makes a difference. See page 6 for connection points.

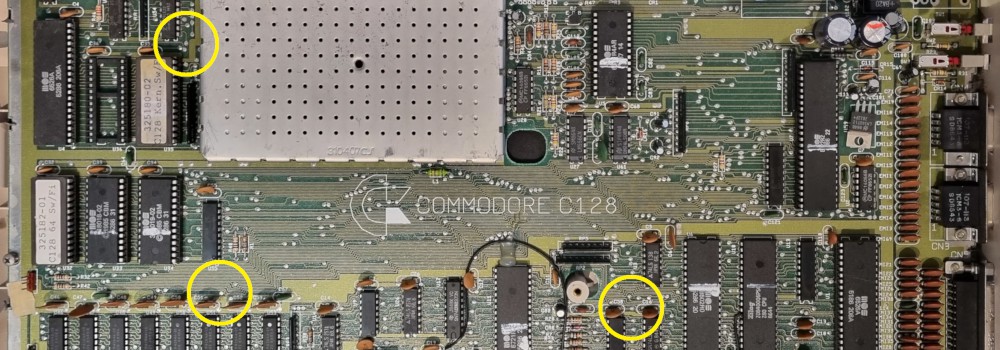
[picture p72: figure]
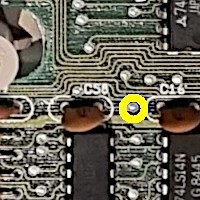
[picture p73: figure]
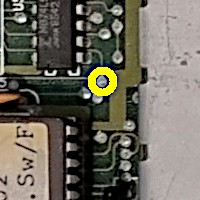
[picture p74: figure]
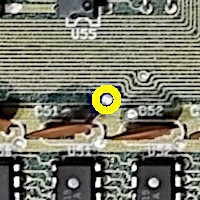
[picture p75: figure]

RESTORE | R/W | RESET


C128DCR
This board has a combined Kernal ROM for C64 and C128 named U32. Replace the Kernal ROM U32 with the switch.
Pay attention to the notch on the socket that indicates pin 1. Pin 1 on the switch is at the end that has six header pins. It is also indicated by a printed notch on the bottom side of the board.
RESTORE | R/W | RESET

# Using the Kernal switch

Switching C64 and C128 Kernals
Hold the restore key for about three seconds until the kernal menu is activated. Once in menu you can use cursor up/down to move to the Kernal you want to switch to and press return. The switch resets the computer with the new Kernal and saves your choice for next power-on.

Switching C64 Kernal in a C128
When switching the C64 Kernal in a C128, hold the CBM and restore keys for about three seconds until the C64 kernal menu is activated. Keep holding the CBM key while selecting Kernal with the cursor up/down and return keys. While pressing return you should hold the CBM key until the reset is done to be taken to C64 mode. Otherwise you will end up in C128 mode after switching C64 Kernal and will have to do a GO64 or CBM+reset again.
The switch saves your choice for next power-on.

In the a C128DCR you can use either C128 kernal menu or C64 kernal menu to switch Kernal but both C64 Kernal and C128 Kernal will be switched at the same time.

# Upgrading the firmware

The firmware in the microcontroller can be upgraded using the 6-pin ISP header. The source code is written for Arduino and programming the firmware can be done directly from the Arduino IDE using an ISP programmer.
If your device is using an Atmega328 it can be programmed as an Arduino UNO. The other variants require custom board definitions. I recommend the DIY AVR cores that can be installed using the Arduino Boards Manager (https://github.com/sleemanj/optiboot).
If you can't or don't want to use Arduino there are some precompiled hex files for the Kernal switch and along with fuse configurations and syntax examples for how to program it using avrdude. These can be found under the Applications folder in my GitHub repository at: https://github.com/RetroNynjah/Switchless-Multi-ROM-for-27128-27256

# Programming the flash chip (ROM)

The flash chip needs to be programmed before soldering it. If you need to reprogram the flash later it must first be desoldered and then resoldered again after reprogramming.
The flash chip should contain the Mini-Kernal image followed by all switchable kernal images in correct order. All images needs to have a size of exactly 16KB.

C64
In a C64 switch those 16KB are made up of 8KB Basic + 8KB Kernal.

C128/C128D
In the C128 the C128 kernal is 16KB and it does not have to be paired with a Basic ROM. The C64 ROM in a C128 is the same as the one in a C64 so it needs basic+kernal pairs.

C128CR/C128DCR
In the C128CR/DCR the C128 kernal is 16KB and needs to be paired with the C64 Basic and C64 Kernal. As the switch will switch both C64 and C128 kernal at the same time you will have to pay extra attention to how you mix the images to not get a confusing setup.

# Document revision history

1.0 Initial version
1.1 Document title corrected
1.2 C128DCR pictures added and minor adjustments
1.3 Added information about Kernal ROM locations and sockets 1.4 Added information about R/W on C128
1.5 Expanded information about R/W problems on C128


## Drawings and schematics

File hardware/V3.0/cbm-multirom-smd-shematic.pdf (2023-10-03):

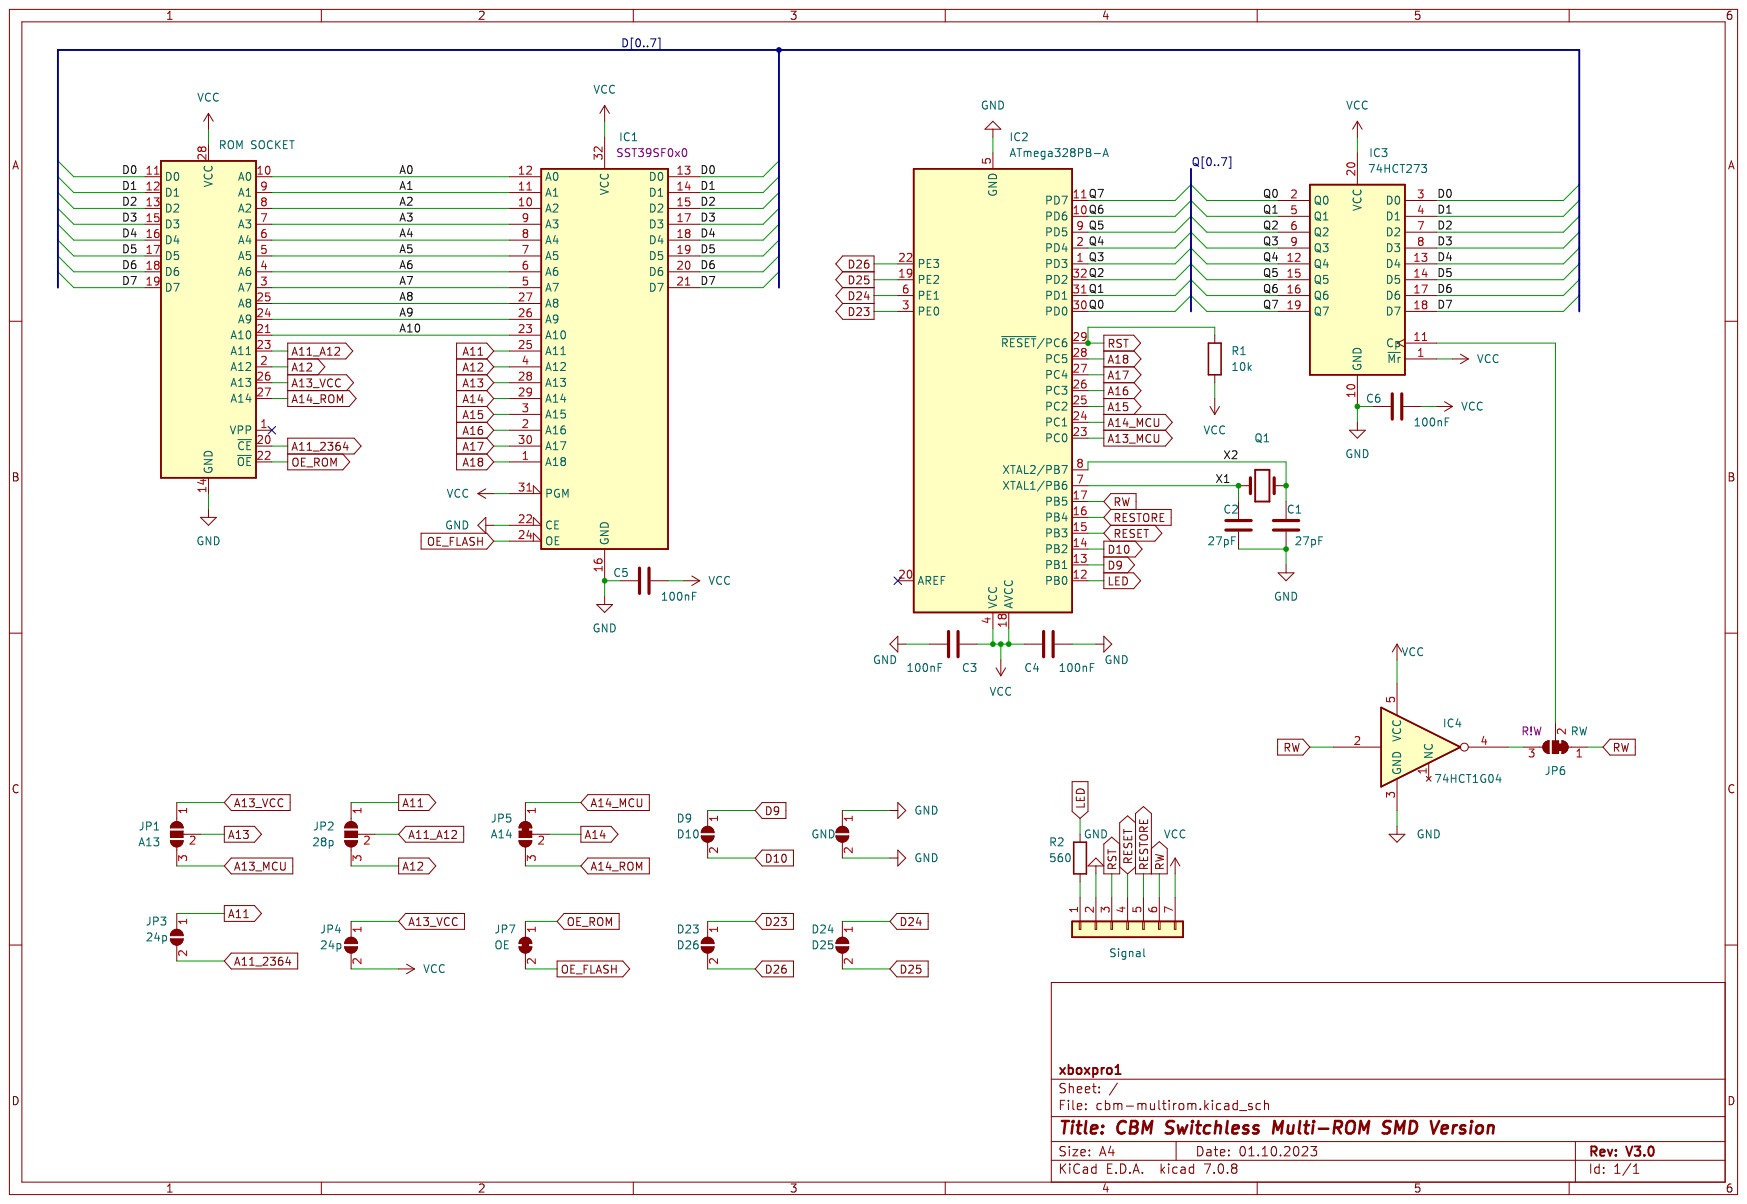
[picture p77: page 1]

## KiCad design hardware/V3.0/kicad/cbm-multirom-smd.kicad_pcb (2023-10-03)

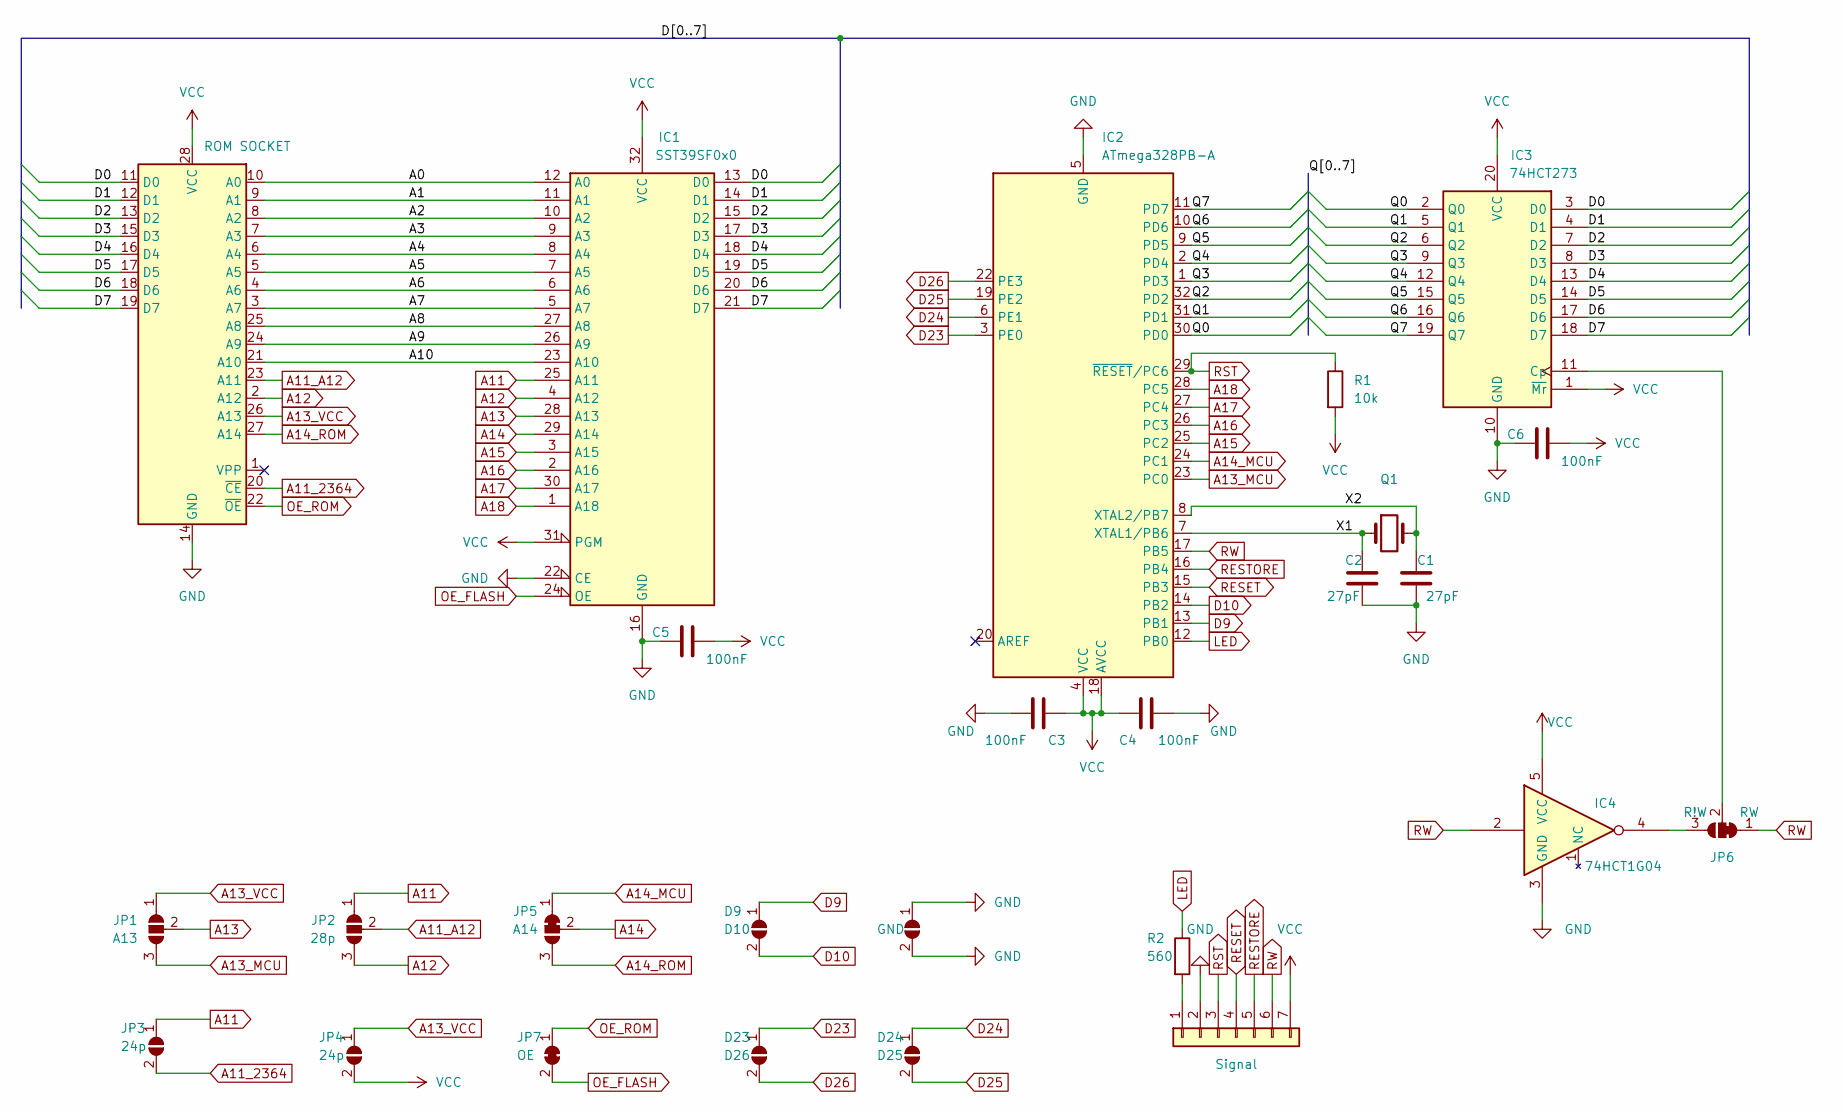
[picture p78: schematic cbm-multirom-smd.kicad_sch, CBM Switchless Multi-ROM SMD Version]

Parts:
C1, C2: 27pF; C_0805_2012Metric_Pad1.18x1.45mm_HandSolder
C3, C4, C5, C6: 100nF; C_0805_2012Metric_Pad1.18x1.45mm_HandSolder
Con1: Signal; PinHeader_1x07_P2.54mm_Horizontal
D9: D10; SolderJumper-2_P1.3mm_Open_RoundedPad1.0x1.5mm
D23: D26; SolderJumper-2_P1.3mm_Open_RoundedPad1.0x1.5mm
D24: D25; SolderJumper-2_P1.3mm_Open_RoundedPad1.0x1.5mm
GND1: GND; SolderJumper-2_P1.3mm_Open_RoundedPad1.0x1.5mm
IC1: SST39SF0x0; PLCC-32_SMD-Socket
IC2: 328P(B); TQFP-32_7x7mm_P0.8mm
IC3: 74HCT273; SO-20_12.8x7.5mm_P1.27mm
IC4: 74HCT1G04; SOT-23-5_HandSoldering
JP1: A13; SolderJumper-3_P1.3mm_Open_RoundedPad1.0x1.5mm
JP2: 28p; SolderJumper-3_P1.3mm_Open_RoundedPad1.0x1.5mm
JP3, JP4: 24p; SolderJumper-2_P1.3mm_Open_RoundedPad1.0x1.5mm
JP5: A14; SolderJumper-3_P1.3mm_Bridged12_RoundedPad1.0x1.5mm
JP6: RW; SolderJumper-3_P1.3mm_Bridged12_RoundedPad1.0x1.5mm
JP7: OE; SolderJumper-2_P1.3mm_Bridged_RoundedPad1.0x1.5mm
Q1: 20MHz; Crystal_SMD_HC49-SD
R1: 10k; R_0805_2012Metric_Pad1.20x1.40mm_HandSolder
R2: 560; R_0805_2012Metric_Pad1.20x1.40mm_HandSolder
ROM1: ROM SOCKET; RomAdapter_28_P

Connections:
/A0: IC1.12 (A0), ROM1.10 (A0)
/A1: IC1.11 (A1), ROM1.9 (A1)
/A2: IC1.10 (A2), ROM1.8 (A2)
/A3: IC1.9 (A3), ROM1.7 (A3)
/A4: IC1.8 (A4), ROM1.6 (A4)
/A5: IC1.7 (A5), ROM1.5 (A5)
/A6: IC1.6 (A6), ROM1.4 (A6)
/A7: IC1.5 (A7), ROM1.3 (A7)
/A8: IC1.27 (A8), ROM1.25 (A8)
/A9: IC1.26 (A9), ROM1.24 (A9)
/A10: IC1.23 (A10), ROM1.21 (A10)
/D0: IC1.13 (D0), IC3.3 (D0), ROM1.11 (D0)
/D1: IC1.14 (D1), IC3.4 (D1), ROM1.12 (D1)
/D2: IC1.15 (D2), IC3.7 (D2), ROM1.13 (D2)
/D3: IC1.17 (D3), IC3.8 (D3), ROM1.15 (D3)
/D4: IC1.18 (D4), IC3.13 (D4), ROM1.16 (D4)
/D5: IC1.19 (D5), IC3.14 (D5), ROM1.17 (D5)
/D6: IC1.20 (D6), IC3.17 (D6), ROM1.18 (D6)
/D7: IC1.21 (D7), IC3.18 (D7), ROM1.19 (D7)
/Q0: IC2.30 (PD0), IC3.2 (Q0)
/Q1: IC2.31 (PD1), IC3.5 (Q1)
/Q2: IC2.32 (PD2), IC3.6 (Q2)
/Q3: IC2.1 (PD3), IC3.9 (Q3)
/Q4: IC2.2 (PD4), IC3.12 (Q4)
/Q5: IC2.9 (PD5), IC3.15 (Q5)
/Q6: IC2.10 (PD6), IC3.16 (Q6)
/Q7: IC2.11 (PD7), IC3.19 (Q7)
/X1: C2.1, IC2.7 (XTAL1/PB6), Q1.1
/X2: C1.1, IC2.8 (XTAL2/PB7), Q1.2
A11: IC1.25 (A11), JP2.1 (A), JP3.1 (A)
A11_2364: JP3.2 (B), ROM1.20 (~CE)
A11_A12: JP2.2 (C), ROM1.23 (A11)
A12: IC1.4 (A12), JP2.3 (B), ROM1.2 (A12)
A13: IC1.28 (A13), JP1.2 (C)
A13_MCU: IC2.23 (PC0), JP1.3 (B)
A13_VCC: JP1.1 (A), JP4.1 (A), ROM1.26 (A13)
A14: IC1.29 (A14), JP5.2 (C)
A14_MCU: IC2.24 (PC1), JP5.1 (A)
A14_ROM: JP5.3 (B), ROM1.27 (A14)
A15: IC1.3 (A15), IC2.25 (PC2)
A16: IC1.2 (A16), IC2.26 (PC3)
A17: IC1.30 (A17), IC2.27 (PC4)
A18: IC1.1 (A18), IC2.28 (PC5)
D9: D9.1 (A), IC2.13 (PB1)
D10: D9.2 (B), IC2.14 (PB2)
D23: D23.1 (A), IC2.3 (PE0)
D24: D24.1 (A), IC2.6 (PE1)
D25: D24.2 (B), IC2.19 (PE2)
D26: D23.2 (B), IC2.22 (PE3)
GND: C1.2, C2.2, C3.2, C4.2, C5.2, C6.2, Con1.2, GND1.1 (A), GND1.2 (B), IC1.16 (GND), IC1.22 (CE), IC2.5 (GND), IC2.21 (GND), IC3.10 (GND), IC4.3 (GND), ROM1.14 (GND)
LED: IC2.12 (PB0), R2.1
unnamed: Con1.1, R2.2
unnamed: IC3.11 (Cp), JP6.2 (C)
unnamed: IC4.4, JP6.3 (B)
OE_FLASH: IC1.24 (OE), JP7.2 (B)
OE_ROM: JP7.1 (A), ROM1.22 (~OE)
RESET: Con1.4, IC2.15 (PB3)
RESTORE: Con1.5, IC2.16 (PB4)
RST: Con1.3, IC2.29 (~RESET/PC6), R1.1
RW: Con1.6, IC2.17 (PB5), IC4.2, JP6.1 (A)
VCC: C3.1, C4.1, C5.1, C6.1, Con1.7, IC1.31 (PGM), IC1.32 (VCC), IC2.4 (VCC), IC2.18 (AVCC), IC3.1 (~Mr), IC3.20 (VCC), IC4.5 (VCC), JP4.2 (B), R1.2, ROM1.28 (VCC)

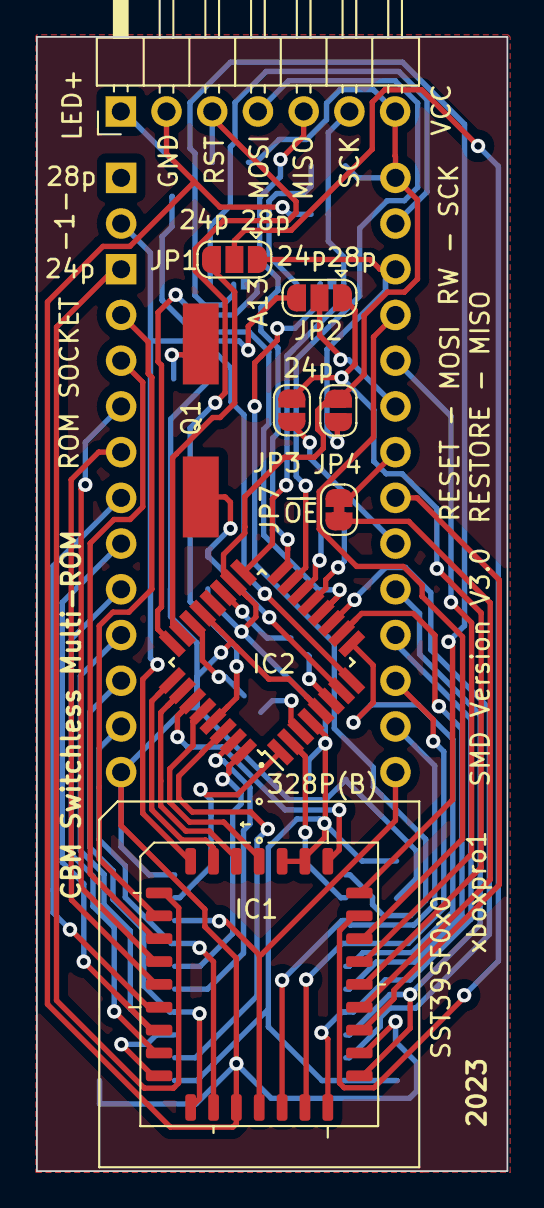
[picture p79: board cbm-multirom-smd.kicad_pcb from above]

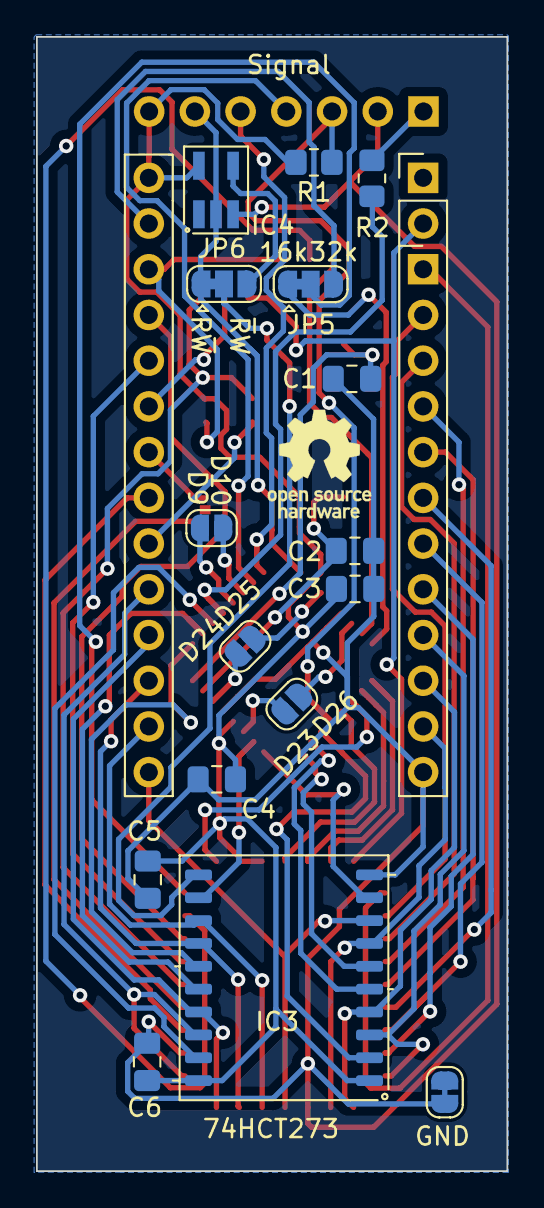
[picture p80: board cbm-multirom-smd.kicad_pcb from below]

Board: 2 copper layers, 26.1 x 63.0 mm, 26 parts (16 on the bottom side), 61 nets.

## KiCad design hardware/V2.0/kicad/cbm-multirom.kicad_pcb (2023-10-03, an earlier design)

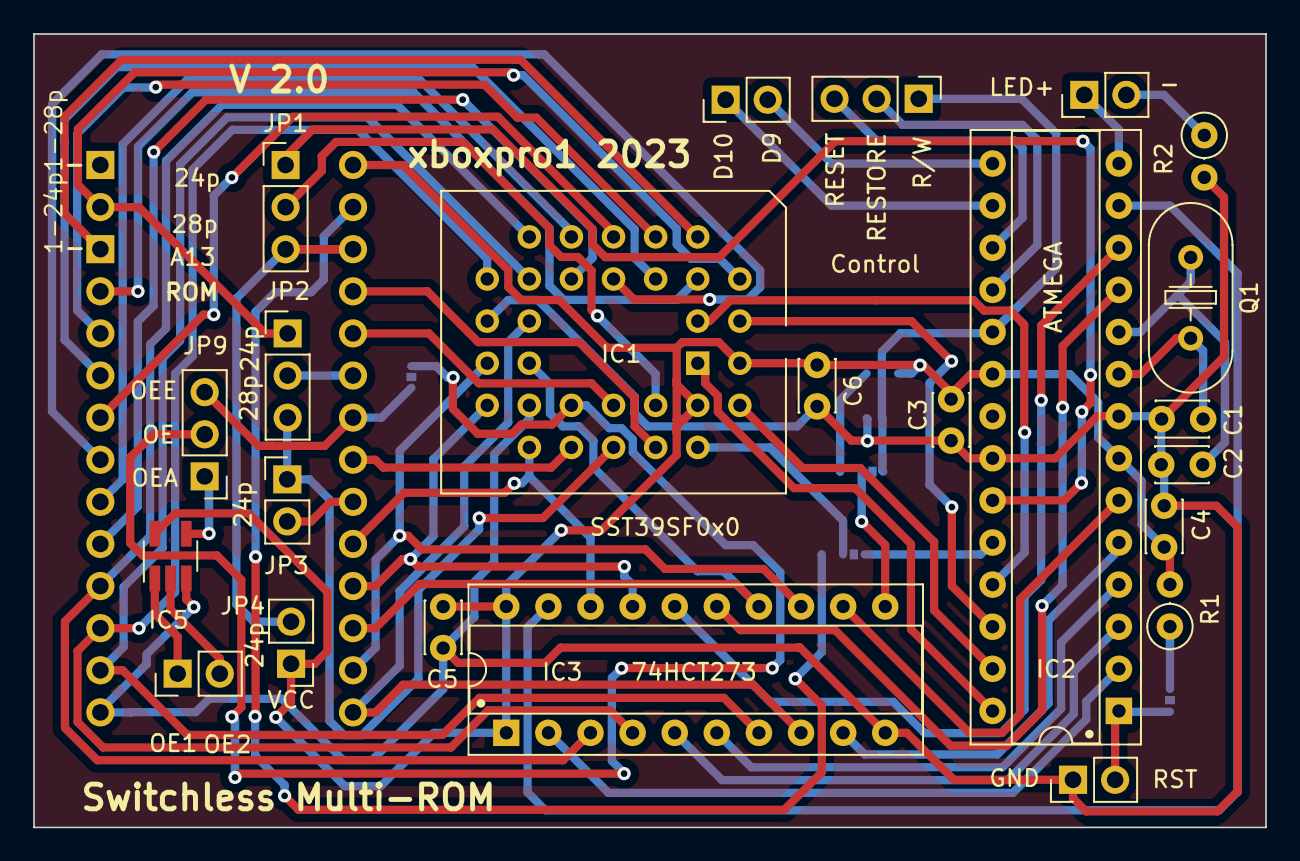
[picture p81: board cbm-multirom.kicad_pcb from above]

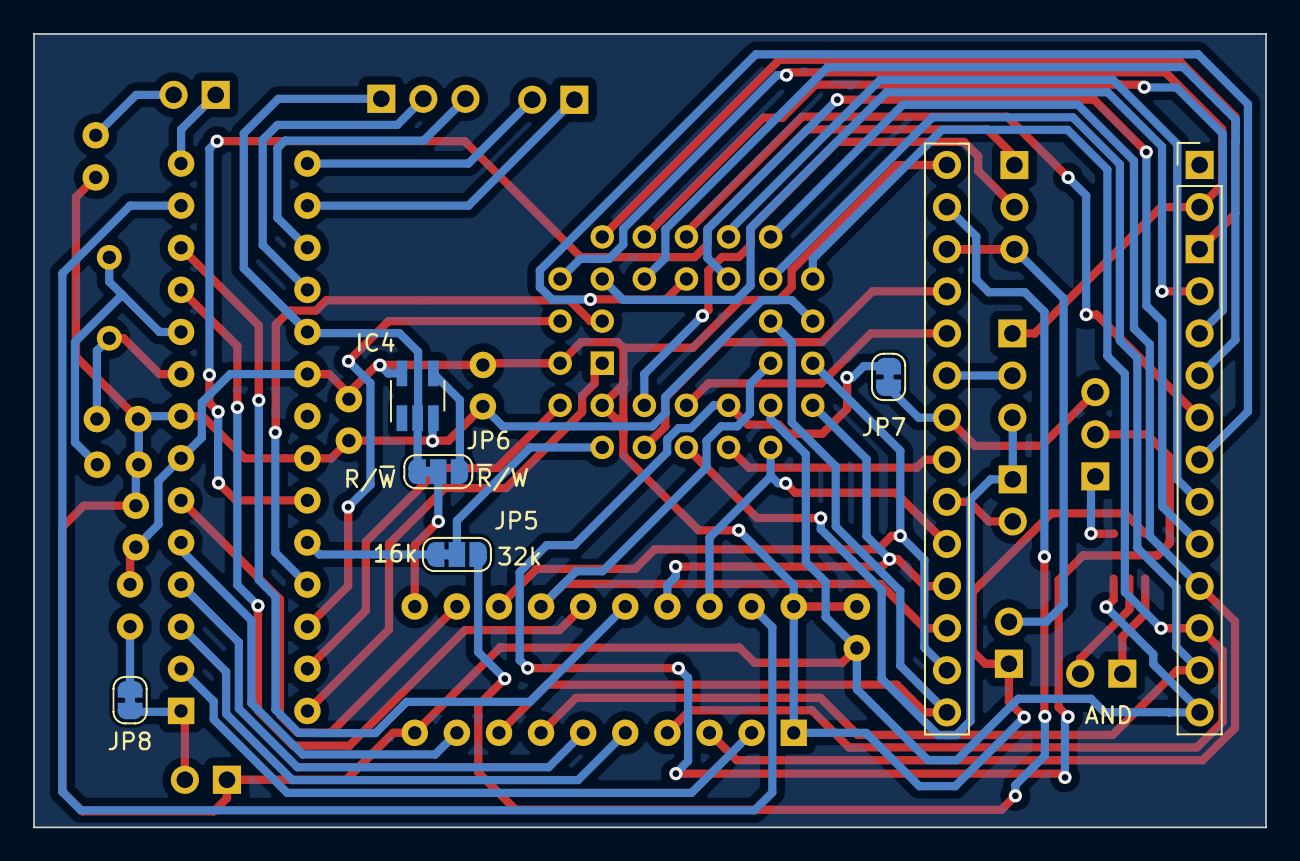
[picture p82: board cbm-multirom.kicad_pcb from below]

Board: 2 copper layers, 74.3 x 47.9 mm, 29 parts (5 on the bottom side), 32 nets.

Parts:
AND: PinHeader_1x02_P2.54mm_Vertical
C1, C2: 30p; C_Disc_D3.0mm_W2.0mm_P2.50mm
C3, C4, C5, C6: 100; C_Disc_D3.0mm_W2.0mm_P2.50mm
Control: PinHeader_1x03_P2.54mm_Vertical
IC1: PLCC-32_THT-Socket
IC2: DIP-28_W7.62mm_Socket
IC3: DIP-20_W7.62mm_Socket
IC4, IC5: SOT-23-5_HandSoldering
JP1, JP2, JP9: PinHeader_1x03_P2.54mm_Vertical
JP3, JP4: PinHeader_1x02_P2.54mm_Vertical
JP5, JP6: SolderJumper-3_P1.3mm_Bridged12_RoundedPad1.0x1.5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; SolderJumper-3_P1.3mm_Bridged12_RoundedPad1.0x1.5mm_NumberL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
JP7, JP8: RST; SolderJumper-2_P1.3mm_Bridged_RoundedPad1.0x1.5mm
LED+: PinHeader_1x02_P2.54mm_Vertical
PinD: PinHeader_1x02_P2.54mm_Vertical
Q1: 20MHz; Crystal_HC49-4H_Vertical
R1, R2: 100k; R_Axial_DIN0207_L6.3mm_D2.5mm_P2.54mm_Vertical
ROM: RomAdapter_28_P
RSTC: PinHeader_1x02_P2.54mm_Vertical

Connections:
/A5: IC1.7, ROM.5
/D5: IC3.14, ROM.17
/D7: IC1.21, ROM.19
/Q7: IC2.13, IC3.19
A11: IC1.25, JP2.3, JP3.1
A11_A12: JP2.2, ROM.23
A12: IC1.4, JP2.1, ROM.2
A13: IC1.28, JP1.2
A13_Select: IC2.23, JP1.1
A13_VCC: JP1.3, JP4.2, ROM.26
A14: IC1.29, JP5.2
A14_27256: JP5.3, ROM.27
A14_Select: IC2.24, JP5.1
A15: IC1.3, IC2.25
A16: IC1.2, IC2.26
A17: IC1.30, IC2.27
A18: IC1.1, IC2.28
And1: AND.1, IC5.1
And2: AND.2, IC5.2
GND: C1.2, C2.2, C3.2, C4.2, C5.1, C6.1, IC1.16, IC1.22, IC2.8, IC2.22, IC3.10, IC4.3, IC5.3, R2.2, ROM.14, RSTC.1
JRST: JP8.2, R1.1
LED: IC2.14, LED+.1
OE: IC1.24, JP7.2, JP9.2
OEA: IC5.4, JP9.1
OEE: JP7.1, JP9.3, ROM.22
RESET: Control.3, IC2.17
RESTORE: Control.2, IC2.18
RST: IC2.1, JP8.1, RSTC.2
RW: Control.1, IC2.19, IC4.2, JP6.1
RWB: IC3.11, JP6.2
RWI: IC4.4, JP6.3
VCC: C3.1, C4.1, C5.2, C6.2, IC1.31, IC1.32, IC2.7, IC2.20, IC3.1, IC3.20, IC4.5, IC5.5, JP4.1, R1.2, ROM.28

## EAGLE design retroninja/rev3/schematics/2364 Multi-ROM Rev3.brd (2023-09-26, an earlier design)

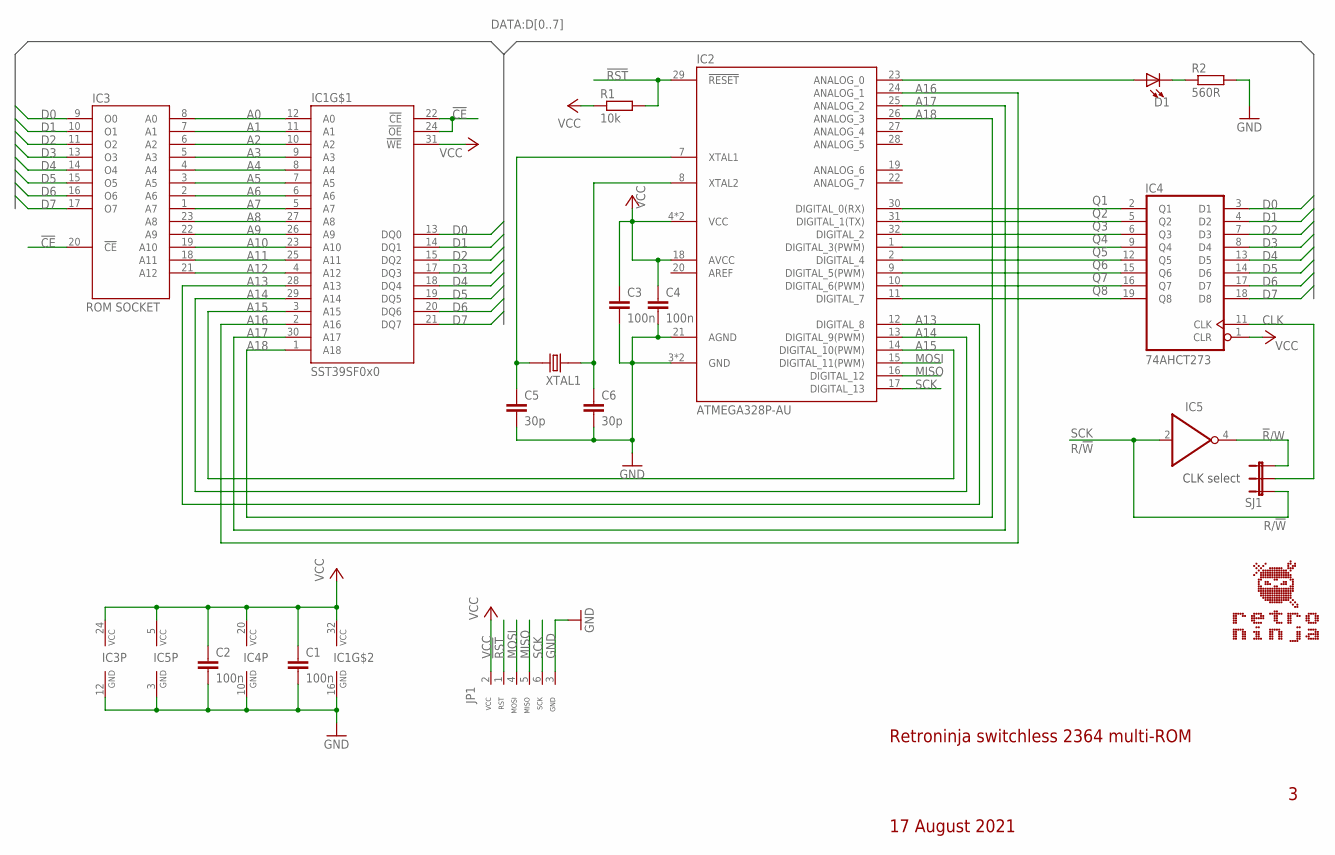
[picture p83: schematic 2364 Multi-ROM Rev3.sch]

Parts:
C1, C2, C3, C4: 100n; C0805
C5, C6: 30p; C0805
D1: LED_0805; LED0805
IC1: SST39SF0x0; PLCC32_SHORT
IC2: ATMEGA328P-AU; TQFP32
IC3: ROM SOCKET; DIL24-6_DOWNPINS
IC4: 74AHCT273; SO20
IC5: 741G04_SOT23; SOT23-5
JP1: ICSP_CONNECTOR_TL866_RIGHT2; HEADER_1X6_RIGHT
R1: 10k; R0805
R2: 560R; R0805
SJ1: JUMPER-3SJ; SJ-3
XTAL1: CRYSTAL; CRYSTAL_SMD-2_7X4X2.3

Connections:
!CE: IC1.22 (!CE), IC1.24 (!OE), IC3.20 (!CE)
!R!/W: IC5.4 (O), SJ1.3
!RST: IC2.29 (!RESET), JP1.1 (RST), R1.2
A0: IC1.12 (A0), IC3.8 (A0)
A1: IC1.11 (A1), IC3.7 (A1)
A2: IC1.10 (A2), IC3.6 (A2)
A3: IC1.9 (A3), IC3.5 (A3)
A4: IC1.8 (A4), IC3.4 (A4)
A5: IC1.7 (A5), IC3.3 (A5)
A6: IC1.6 (A6), IC3.2 (A6)
A7: IC1.5 (A7), IC3.1 (A7)
A8: IC1.27 (A8), IC3.23 (A8)
A9: IC1.26 (A9), IC3.22 (A9)
A10: IC1.23 (A10), IC3.19 (A10)
A11: IC1.25 (A11), IC3.18 (A11)
A12: IC1.4 (A12), IC3.21 (A12)
A13: IC1.28 (A13), IC2.12 (DIGITAL_8)
A14: IC1.29 (A14), IC2.13 (DIGITAL_9(PWM))
A15: IC1.3 (A15), IC2.14 (DIGITAL_10(PWM))
A16: IC1.2 (A16), IC2.24 (ANALOG_1)
A17: IC1.30 (A17), IC2.25 (ANALOG_2)
A18: IC1.1 (A18), IC2.26 (ANALOG_3)
CLK: IC4.11 (CLK), SJ1.2
D0: IC1.13 (DQ0), IC3.9 (O0), IC4.3 (D1)
D1: IC1.14 (DQ1), IC3.10 (O1), IC4.4 (D2)
D2: IC1.15 (DQ2), IC3.11 (O2), IC4.7 (D3)
D3: IC1.17 (DQ3), IC3.13 (O3), IC4.8 (D4)
D4: IC1.18 (DQ4), IC3.14 (O4), IC4.13 (D5)
D5: IC1.19 (DQ5), IC3.15 (O5), IC4.14 (D6)
D6: IC1.20 (DQ6), IC3.16 (O6), IC4.17 (D7)
D7: IC1.21 (DQ7), IC3.17 (O7), IC4.18 (D8)
GND: C1.2, C2.2, C3.2, C4.2, C5.2, C6.2, IC1.16 (GND), IC2.3 (GND), IC2.5 (GND), IC2.21 (AGND), IC3.12 (GND), IC4.10 (GND), IC5.3 (GND), JP1.3 (GND), R2.2
MISO: IC2.16 (DIGITAL_12), JP1.5 (MISO)
MOSI: IC2.15 (DIGITAL_11(PWM)), JP1.4 (MOSI)
unnamed: C6.1, IC2.8 (XTAL2), XTAL1.1
unnamed: C5.1, IC2.7 (XTAL1), XTAL1.2
unnamed: D1.A, IC2.23 (ANALOG_0)
unnamed: D1.C, R2.1
Q1: IC2.30 (DIGITAL_0(RX)), IC4.2 (Q1)
Q2: IC2.31 (DIGITAL_1(TX)), IC4.5 (Q2)
Q3: IC2.32 (DIGITAL_2), IC4.6 (Q3)
Q4: IC2.1 (DIGITAL_3(PWM)), IC4.9 (Q4)
Q5: IC2.2 (DIGITAL_4), IC4.12 (Q5)
Q6: IC2.9 (DIGITAL_5(PWM)), IC4.15 (Q6)
Q7: IC2.10 (DIGITAL_6(PWM)), IC4.16 (Q7)
Q8: IC2.11 (DIGITAL_7), IC4.19 (Q8)
SCK: IC2.17 (DIGITAL_13), IC5.2 (I), JP1.6 (SCK), SJ1.1
VCC: C1.1, C2.1, C3.1, C4.1, IC1.31 (!WE), IC1.32 (VCC), IC2.4 (VCC), IC2.6 (VCC), IC2.18 (AVCC), IC3.24 (VCC), IC4.1 (CLR), IC4.20 (VCC), IC5.5 (VCC), JP1.2 (VCC), R1.1

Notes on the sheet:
R/!W
Retroninja switchless 2364 multi-ROM
17 August 2021
CLK select

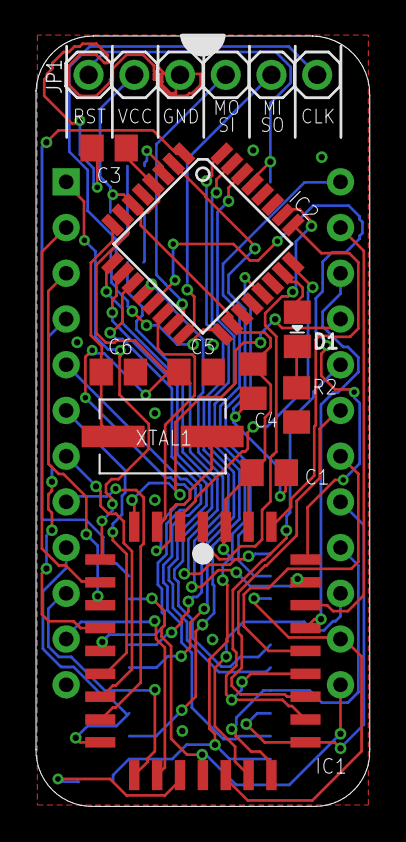
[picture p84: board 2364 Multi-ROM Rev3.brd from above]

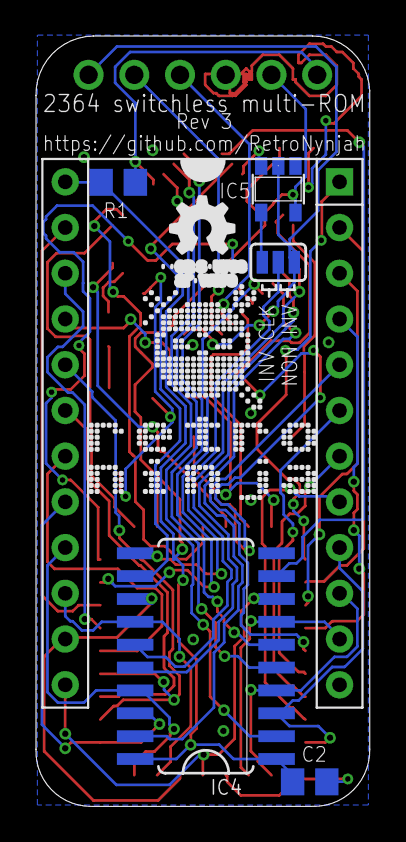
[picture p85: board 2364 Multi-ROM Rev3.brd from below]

Board: 2 copper layers, 18.5 x 42.8 mm, 19 parts (7 on the bottom side), 48 nets.

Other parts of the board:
U$1: RETRONINJA_12MM
U$2: OSHW_5MM

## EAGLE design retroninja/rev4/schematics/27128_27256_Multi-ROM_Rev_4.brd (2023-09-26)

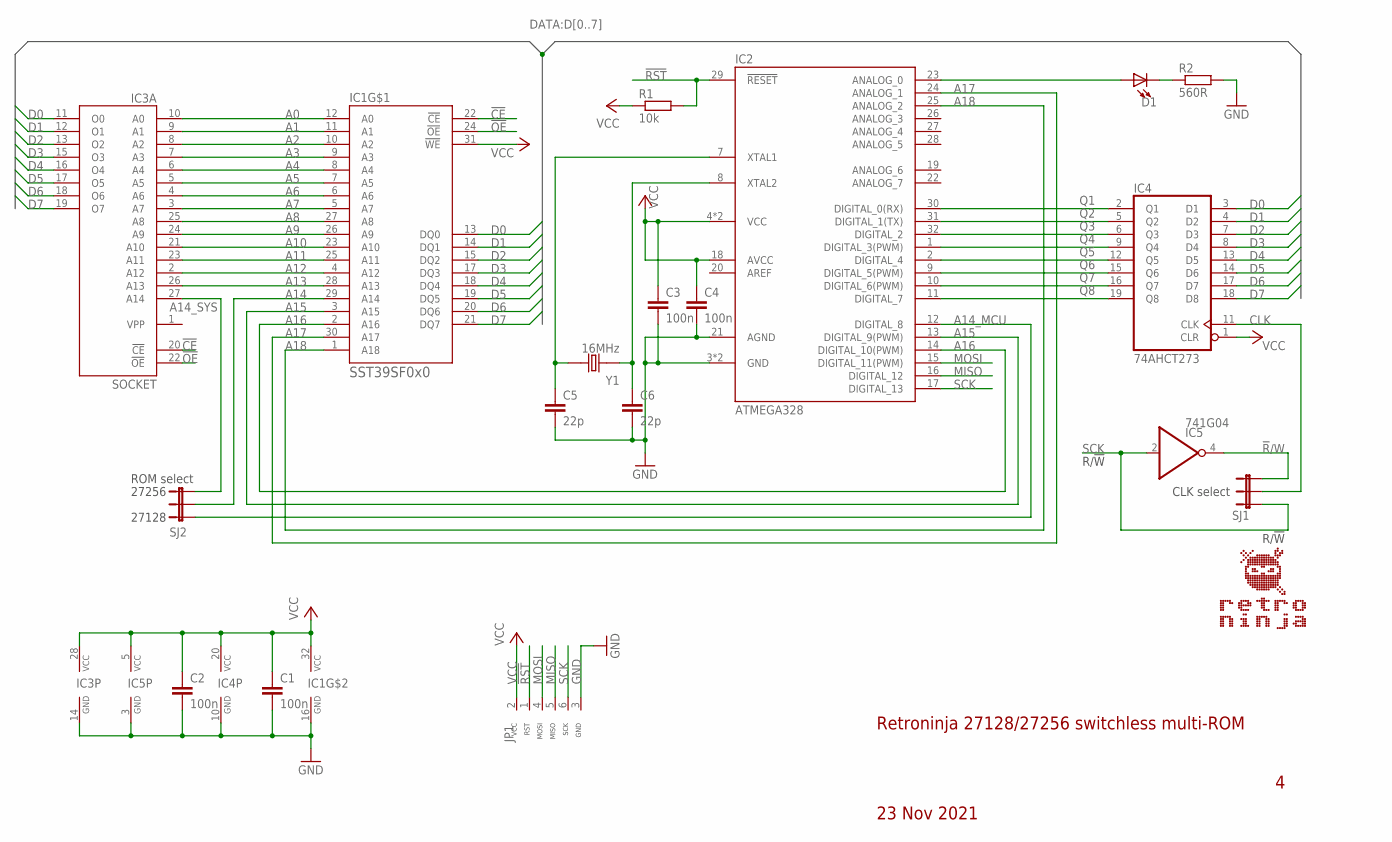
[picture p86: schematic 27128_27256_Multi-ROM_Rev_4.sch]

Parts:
C1, C2, C3, C4: 100n; C0805
C5, C6: 22p; C0805
D1: LED_0805; LED0805
IC1: SST39SF0x0; PLCC32_SHORT
IC2: ATMEGA328; TQFP32
IC3: SOCKET; DIL28-6_DOWNPINS
IC4: 74AHCT273; SO20
IC5: 741G04; SOT23-5
JP1: ICSP_CONNECTOR_TL866_RIGHT2; HEADER_1X6_RIGHT
R1: 10k; R0805
R2: 560R; R0805
SJ1, SJ2: JUMPER-3SJ; SJ-3
Y1: 16MHz; CRYSTAL_SMD-2_7X4X2.3

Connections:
!CE: IC1.22 (!CE), IC3.20 (!CE)
!OE: IC1.24 (!OE), IC3.22 (!OE)
!R!/W: IC5.4 (O), SJ1.3
!RST: IC2.29 (!RESET), JP1.1 (RST), R1.2
A0: IC1.12 (A0), IC3.10 (A0)
A1: IC1.11 (A1), IC3.9 (A1)
A2: IC1.10 (A2), IC3.8 (A2)
A3: IC1.9 (A3), IC3.7 (A3)
A4: IC1.8 (A4), IC3.6 (A4)
A5: IC1.7 (A5), IC3.5 (A5)
A6: IC1.6 (A6), IC3.4 (A6)
A7: IC1.5 (A7), IC3.3 (A7)
A8: IC1.27 (A8), IC3.25 (A8)
A9: IC1.26 (A9), IC3.24 (A9)
A10: IC1.23 (A10), IC3.21 (A10)
A11: IC1.25 (A11), IC3.23 (A11)
A12: IC1.4 (A12), IC3.2 (A12)
A13: IC1.28 (A13), IC3.26 (A13)
A14: IC1.29 (A14), SJ2.2
A14_MCU: IC2.12 (DIGITAL_8), SJ2.1
A14_SYS: IC3.27 (A14), SJ2.3
A15: IC1.3 (A15), IC2.13 (DIGITAL_9(PWM))
A16: IC1.2 (A16), IC2.14 (DIGITAL_10(PWM))
A17: IC1.30 (A17), IC2.24 (ANALOG_1)
A18: IC1.1 (A18), IC2.25 (ANALOG_2)
CLK: IC4.11 (CLK), SJ1.2
D0: IC1.13 (DQ0), IC3.11 (O0), IC4.3 (D1)
D1: IC1.14 (DQ1), IC3.12 (O1), IC4.4 (D2)
D2: IC1.15 (DQ2), IC3.13 (O2), IC4.7 (D3)
D3: IC1.17 (DQ3), IC3.15 (O3), IC4.8 (D4)
D4: IC1.18 (DQ4), IC3.16 (O4), IC4.13 (D5)
D5: IC1.19 (DQ5), IC3.17 (O5), IC4.14 (D6)
D6: IC1.20 (DQ6), IC3.18 (O6), IC4.17 (D7)
D7: IC1.21 (DQ7), IC3.19 (O7), IC4.18 (D8)
GND: C1.2, C2.2, C3.2, C4.2, C5.2, C6.2, IC1.16 (GND), IC2.3 (GND), IC2.5 (GND), IC2.21 (AGND), IC3.14 (GND), IC4.10 (GND), IC5.3 (GND), JP1.3 (GND), R2.2
MISO: IC2.16 (DIGITAL_12), JP1.5 (MISO)
MOSI: IC2.15 (DIGITAL_11(PWM)), JP1.4 (MOSI)
unnamed: C6.1, IC2.8 (XTAL2), Y1.1
unnamed: C5.1, IC2.7 (XTAL1), Y1.2
unnamed: D1.A, IC2.23 (ANALOG_0)
unnamed: D1.C, R2.1
Q1: IC2.30 (DIGITAL_0(RX)), IC4.2 (Q1)
Q2: IC2.31 (DIGITAL_1(TX)), IC4.5 (Q2)
Q3: IC2.32 (DIGITAL_2), IC4.6 (Q3)
Q4: IC2.1 (DIGITAL_3(PWM)), IC4.9 (Q4)
Q5: IC2.2 (DIGITAL_4), IC4.12 (Q5)
Q6: IC2.9 (DIGITAL_5(PWM)), IC4.15 (Q6)
Q7: IC2.10 (DIGITAL_6(PWM)), IC4.16 (Q7)
Q8: IC2.11 (DIGITAL_7), IC4.19 (Q8)
SCK: IC2.17 (DIGITAL_13), IC5.2 (I), JP1.6 (SCK), SJ1.1
VCC: C1.1, C2.1, C3.1, C4.1, IC1.31 (!WE), IC1.32 (VCC), IC2.4 (VCC), IC2.6 (VCC), IC2.18 (AVCC), IC3.28 (VCC), IC4.1 (CLR), IC4.20 (VCC), IC5.5 (VCC), JP1.2 (VCC), R1.1
VPP: IC3.1 (VPP)

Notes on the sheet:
Retroninja 27128/27256 switchless multi-ROM
23 Nov 2021
27128
27256
R/!W
CLK select
ROM select

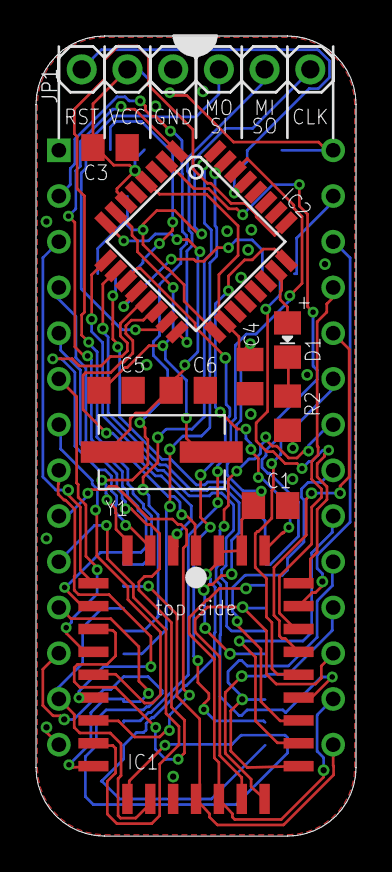
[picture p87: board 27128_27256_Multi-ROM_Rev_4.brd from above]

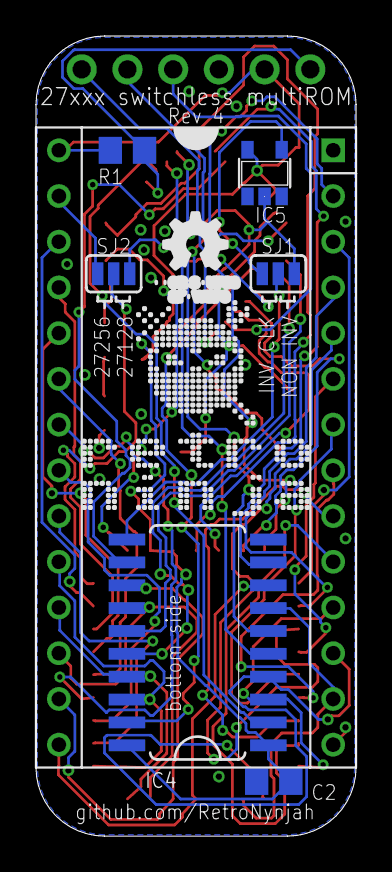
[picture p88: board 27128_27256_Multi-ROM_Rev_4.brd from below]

Board: 2 copper layers, 17.8 x 44.5 mm, 20 parts (8 on the bottom side), 51 nets.

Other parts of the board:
U$1: RETRONINJA_12MM
U$2: OSHW_5MM

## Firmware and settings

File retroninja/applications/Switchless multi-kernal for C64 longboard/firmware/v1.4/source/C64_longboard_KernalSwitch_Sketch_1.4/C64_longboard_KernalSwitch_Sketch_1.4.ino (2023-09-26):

/*
#########################################################################################
#                                                                                       #
#  Kernal switcher sketch for C64 longboard (24-pin ROM)                                #
#  To be used with the Retroninja 2364 switchless multi-ROM                             #
#                                                                                       #
#  Version 1.4                                                                          #
#  https://github.com/retronynjah                                                       #
#                                                                                       #
#########################################################################################
*/

#include <EEPROM.h>

// searchString is the command that the kernalselector firmware sends to the ROM switcher.
// Searchstring below is RNROM64#
// The command will be followed by a single byte ROM number between 1 (0x01) and 15 (0x0f)
byte searchString[] = {0x52,0x4E,0x52,0x4F,0x4D,0x36,0x34,0x23}; // "RNROM64#"

// pin defitions
int resetPin = 11;
int restorePin = 12;
int clockPin = 13;
int ledPin = A0;

int savedROM;
int commandLength = sizeof(searchString);
int bytesCorrect = 0;
int blinkROM = 0;
bool ledstate = LOW;
long ledchange = 0;
volatile bool clockstate;
bool restorestate;
bool restoreholding = false;
bool inmenu = false;
long restorepressed;

void pciSetup(byte pin) {
  // enable Pin Change Interrupt for requested pin
  *digitalPinToPCMSK(pin) |= bit(digitalPinToPCMSKbit(pin));  // enable pin
  PCIFR |= bit(digitalPinToPCICRbit(pin));                    // clear any outstanding interrupt
  PCICR |= bit(digitalPinToPCICRbit(pin));                    // enable interrupt for the group
}



ISR(PCINT0_vect)  // handle pin change interrupt for D8 to D13 here
{
  // read state of clock pin (D13)
  clockstate = PINB & B100000;
}


void cleareeprom() {
  for (int i = 0; i < EEPROM.length(); i++) {
    EEPROM.write(i, 0);
  }
}


void switchrom(int romnumber, bool doreset){

  if (doreset){
    // hold reset 
    digitalWrite(resetPin, LOW);
    delay(100);
    pinMode(resetPin, OUTPUT);
    digitalWrite(resetPin, LOW);
  }
 
  // switch eprompin A13 (D8)
  if (romnumber & B0001){
    digitalWrite(8, HIGH);
  }  
  else {
    digitalWrite(8, LOW);
  }

  // switch eprompin A14 (D9)
  if (romnumber & B000010){
    digitalWrite(9, HIGH);
  }  
  else {
    digitalWrite(9, LOW);
  }

  // switch eprompin A15 (D10)
  if (romnumber & B000100){
    digitalWrite(10, HIGH);
  }  
  else {
    digitalWrite(10, LOW);
  }

  // switch eprompin A16 (A1)
  if (romnumber & B001000){
    digitalWrite(A1, HIGH);
  }  
  else {
    digitalWrite(A1, LOW);
  }

  // switch eprompin A17 (A2)
  if (romnumber & B010000){
    digitalWrite(A2, HIGH);
  }  
  else {
    digitalWrite(A2, LOW);
  }

  // switch eprompin A18 (A3)
  if (romnumber & B100000){
    digitalWrite(A3, HIGH);
  }  
  else {
    digitalWrite(A3, LOW);
  }

  // if switching to a new kernal that isn't the menu kernal - save kernal to EEPROM address 0
  if ((romnumber != savedROM) && (romnumber != 0)){
    EEPROM.write(0, romnumber);
    savedROM = romnumber;
  }
  
  if (romnumber != 0){
    inmenu = false;
  }
  
  if (doreset) {
    // Release reset
    delay(200);
    pinMode(resetPin, INPUT);
  }

  // Give system some time to reset before entering main loop again.
  delay(500);
  blinkROM = romnumber;
}


void setup() {

  // set data pins 0..7 as inputs
  DDRD = B00000000;

  // Keep reset active (low) during setup
  digitalWrite(resetPin, LOW);
  pinMode(resetPin, OUTPUT);
  pinMode(clockPin, INPUT);
  
  pinMode(8, OUTPUT); // eprom A13
  pinMode(9, OUTPUT); // eprom A14
  pinMode(10, OUTPUT); // eprom A15
  pinMode (A1, OUTPUT); // eprom A16
  pinMode (A2, OUTPUT); // eprom A17
  pinMode (A3, OUTPUT); // eprom A18
  pinMode (ledPin, OUTPUT);

  pinMode (restorePin, INPUT);
  digitalWrite(ledPin, LOW);
  
  // retrieve last used ROM from ATmega EEPROM and switch ROM using ROM address pins A13-A18
  savedROM = EEPROM.read(0);
  if (savedROM > 15){
    savedROM = 0;
  }
  if (savedROM == 0) {
    inmenu = true;
  }
  
  switchrom(savedROM, false);
  
  // Release reset
  pinMode(resetPin, INPUT);
  delay(500); // Give system some time to finish reset before entering loop

  // Enable pin change interrupt on pin D13(PB5) connected to R/!W signal
  pciSetup(clockPin);
  
}


void loop() {

  if (inmenu) {
    ledstate = LOW;
    blinkROM = 0;
    // while in menu mode, listen for command
    if (clockstate == HIGH) {
      byte byteCurr = PIND;
      clockstate = LOW;
      if (bytesCorrect == commandLength) {
        // We have already found our command string. This byte must be the ROM number
        // Valid numbers are 1-15
        if ((byteCurr >= 1) && (byteCurr <= 15)) {
          // ROM number within valid range. Switch ROM and perform a reset
          switchrom(byteCurr, true);
        } else {
          bytesCorrect = 0;
        }
      }
      // We don't have full command string yet. Check if current byte is what we are looking for
      else if (byteCurr == searchString[bytesCorrect]) {
        // Increase bytesCorrect to check for next character
        bytesCorrect++;
      } else {
        bytesCorrect = 0;
      }
    }

    // Check if reset pin is active (low)
    if (!(PINB & B1000)) {
      // Reset is active. Other switch might be active and doing a reset or user is resetting.
      // Switch ROM to give up menu in case we're in menu and don't perform another reset as a reset is already in progress.
      switchrom(savedROM, false);
    }
  } else {
    // while not in menu mode, listen for restore key
    restorestate = PINB & B010000;
    if (restorestate == LOW) {
      // restore pressed
      ledstate = HIGH;
      if (restoreholding == false) {
        // start counting restore hold time
        restorepressed = millis();
        restoreholding = true;
      }
      if ((millis() - restorepressed) > 2000) {
        // Switch to menu ROM and perform a reset
        inmenu = true;
        switchrom(0, true);
        ledstate = LOW;
        restoreholding = false;
      }
    } else {
      // restore not held
      if (restoreholding){
        // restore has just been released
        ledstate = LOW;
        restoreholding = false;
      }
      
      //if kernal has just been switched we can do some led blinking now to indicate selected kernal
      if (blinkROM > 0) {
        if (ledchange == 0) {
          // first blink turn on LED and start counting
          ledstate = HIGH;
          ledchange = millis() + 50;
        } else {
          if (millis() > ledchange) {
            // time to toggle LED
            if (ledstate == HIGH) {
              ledstate = LOW;
              blinkROM--;
              if (blinkROM > 0) {
                // turn off LED and start counting
                ledchange = millis() + 250;
              } else {
                ledchange = 0;
              }
            } else {
              // turn on LED and start counting
              if (blinkROM > 0) {
                ledstate = HIGH;
                ledchange = millis() + 50;
              }
            }
          }
        }
      } 
    }
    digitalWrite(ledPin, ledstate);
  }
}

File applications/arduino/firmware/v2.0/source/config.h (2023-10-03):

/*
#########################################################################################
#                                                                                       #
#  config.h for CBM multi-ROM THT version (24-pin & 28-pin ROM)                         #
#  To be used with the switchless cbm-multi-ROM THT version                             #
#                                                                                       #
#  Version 1.0                                                                          #
#  https://github.com/xboxpro1                                                          #
#########################################################################################
*/

#pragma once

// include librarys
#include <Arduino.h>
#include <EEPROM.h>
#include <FastGPIO.h>               // pololu FastGPIO library. see https://github.com/pololu/fastgpio-arduino

// define mcu variant for additional pins
#if defined(__AVR_ATmega48PB__) || defined(__AVR_ATmega88PB__) || defined(__AVR_ATmega168PB__) || defined(__AVR_ATmega328PB__)
    #define PBVARIANT
#endif

// define CBM ids
#define VIC20 1000
#define C64 1001
#define C64C 1002
#define C128 1003
#define C128DCR 1004

// define fastgpio atmega pins
#define ledPin IO_B0                // LED pin
#define pin8 IO_B0                  // pin 8 (free to use if LED is disabled)
#define pin9 IO_B1                  // pin 9 (free to use)
#define pin10 IO_B2                 // pin 10 (free to use)
#define resetPin IO_B3              // reset pin 11
#define restorePin IO_B4            // restore pin 12
#define rwPin IO_B5                 // rw pin 13
#ifdef PBVARIANT
    #define pin23 IO_E0             // pin 23 pb-variant
    #define pin24 IO_E1             // pin 24 pb-variant
    #define pin25 IO_E2             // pin 25 pb-variant
    #define pin26 IO_E3             // pin 26 pb-variant
#endif

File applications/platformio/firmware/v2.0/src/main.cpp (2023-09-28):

/*
#########################################################################################
#                                                                                       #
#  CBM kernal switcher sketch for multi-ROM THT version (24-pin & 28-pin ROM)           #
#  To be used with the switchless cbm-multi-ROM THT version                             #
#                                                                                       #
#  Version 1.4                                                                          #
#  https://github.com/retronynjah                                                       #
#  modified by xboxpro1                                                                 #
#  Version 2.0                                                                          #
#  https://github.com/xboxpro1                                                          #
#########################################################################################
*/

#include "config.h"                                                                         // include definitions and librarys

//  set commodore cbm id, possible ids
//  VIC20 - (24pin ROM, 8k ROM, flashbank -> 0) 
//  C64 - (longboard, 24pin ROM, 8k ROM, flashbank -> 0)
//  C64C - (shortboard, 28pin ROM, 16k ROM, flashbank -> 1)
//  C128 - (28pin ROM, 16k ROM, flashbank -> 1)
//  C128DCR - (28pin ROM, 32k ROM, flashbank -> 2)

#define CBMID C64	                                                                        // set CBM ID

// enable LED for blinking
#define LED                                                                                 // enable LED, commend out to disable

// nothing to setup below
#ifndef CBMID
  #define CBMID C64                                                                         // for security reasons in case something goes wrong with defining CBMID
#endif

// searchString is the command that the kernalselector minikernal sends to the THT ROM switcher.
// The command will be followed by a single byte ROM number between 1 (0x01) and 10 (0x0a)
// flashbank selects 8k, 16k, or 32k ROM

// VIC20 config
#if CBMID == VIC20
  byte searchString[] = {0x43,0x42,0x4D,0x52,0x4F,0x4D,0x32,0x30,0x23};                     // searchstring is "CBMROM20#"
  #define flashBank 0                                                                       // 8k ROM
  #define maxROM  10                                                                        // max minikernal ROM entries 
#endif

// C64 longboard config
#if CBMID == C64
  byte searchString[] = {0x43,0x42,0x4D,0x52,0x4F,0x4D,0x36,0x34,0x23};                     // searchstring is "CBMROM64#"
  #define flashBank 0                                                                       // 8k ROM
  #define maxROM  10                                                                        // max minikernal ROM entries
#endif

// C64C shortboard config
#if CBMID == C64C
  byte searchString[] = {0x43,0x42,0x4D,0x52,0x4F,0x4D,0x36,0x34,0x23};                     // searchstring is "CBMROM64#"
  #define flashBank 1                                                                       // 16k ROM
  #define maxROM  10                                                                        // max minikernal ROM entries
#endif

// C128 config
#if CBMID == C128
  byte searchString[] = {0x43,0x42,0x4D,0x52,0x4F,0x4D,0x31,0x32,0x38,0x23};                // searchstring is "CBMROM128#"
  #define flashBank 1                                                                       // 16k ROM
  #define maxROM  10                                                                        // max minikernal ROM entries
#endif

// C128DCR config
#if CBMID == C128DCR
  byte searchString[] = {0x43,0x42,0x4D,0x52,0x4F,0x4D,0x31,0x32,0x38,0x44,0x43,0x52,0x23}; // searchstring is "CBMROM128DCR#"
  #define flashBank 2                                                                       // 32k ROM
  #define maxROM  10                                                                        // max minikernal ROM entries
#endif

// variables

byte commandLength = sizeof(searchString);
byte savedROM;
byte bytesCorrect = 0;
byte dataByte = 0x00;
long restorepressed;
volatile bool rwstate;
//volatile bool pin9state;
//volatile bool pin10state;
bool restorestate;
bool resetstate;
bool restoreholding = false;
bool inmenu = false;

#ifdef LED
  byte blinkCounter = 0;
  unsigned long ledtiming = 0;
#endif

// interrupt vector handling

ISR(PCINT0_vect)                                              // handle pin change interrupt for Port B0 - B5, Pin 8 to 13
{
  rwstate = FastGPIO::Pin<rwPin>::isInputHigh();              // read state of rw pin (D13); indicate that data on port d is available
  //pin9state = FastGPIO::Pin<pin9>::isInputHigh();           // read state of pin9 (D9)
  //pin10state = FastGPIO::Pin<pin10>::isInputHigh();         // read state of pin10 (D10)
}

// interrupt vector handling end

// functions

void pciSetup(byte pin) {                                     // enable Pin Change Interrupt for requested pin
  *digitalPinToPCMSK(pin) |= bit(digitalPinToPCMSKbit(pin));  // enable pin
  PCIFR |= bit(digitalPinToPCICRbit(pin));                    // clear any outstanding interrupt
  PCICR |= bit(digitalPinToPCICRbit(pin));                    // enable interrupt for the group
}
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

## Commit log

2023-09-26 V2.0
    THT Version
    [cbm-multirom.kicad_pcb, cbm-multirom.kicad_sch]
2023-10-03 V3.0
    Added hardware SMD PCB V3.0
    [cbm-multirom-smd.kicad_pcb, cbm-multirom-smd.kicad_sch, cbm-multirom.kicad_pcb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]
2023-10-03 V3.0
    Changed Jumper setup
    [cbm-multirom-smd.kicad_pcb, cbm-multirom-smd.kicad_sch]
